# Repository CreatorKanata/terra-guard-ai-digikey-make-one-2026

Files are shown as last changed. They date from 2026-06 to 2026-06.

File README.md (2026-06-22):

<p align="center">
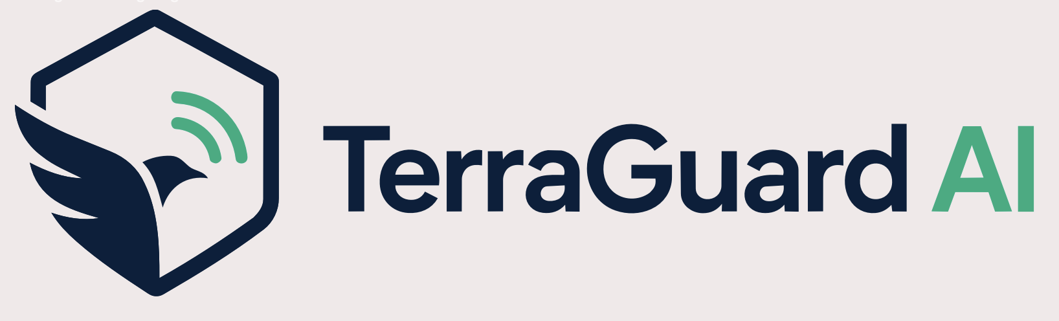
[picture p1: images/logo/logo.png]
TerraGuard AI
  
</p>

<p align="center">
  <b>カメラを使わない、ネットにつながない。<br>
  1 枚のマイコンだけで「カラスがいる」と気づくエッジAI。</b>
</p>

<p align="center">
  <a href="https://protopedia.net/event/digikey2026">DigiKey Make ONE Challenge 2026</a> 応募作品 ／ 使用ボード: <b>NXP FRDM-MCXN947</b>（おすすめ製品）
</p>

---

## 🎥 デモ動画（2分）

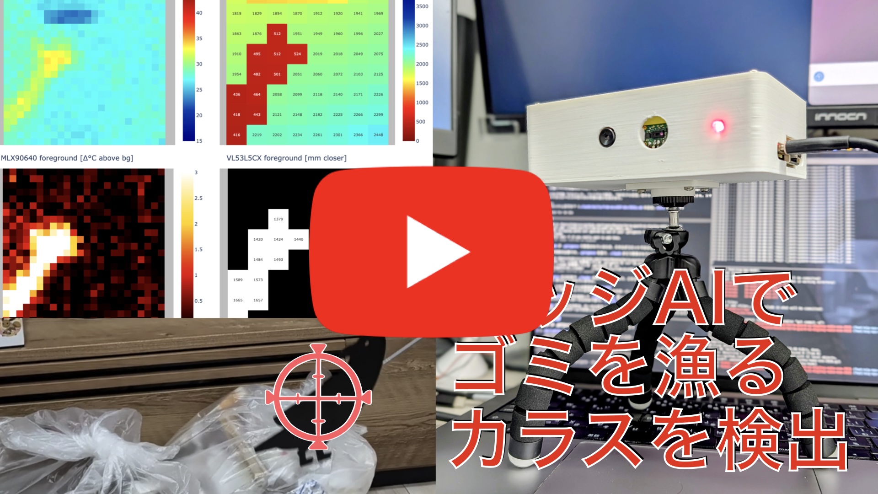
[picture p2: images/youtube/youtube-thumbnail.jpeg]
TerraGuard AI デモ動画 (https://youtu.be/Pb8VNFVwH3w)


> サムネイルをクリックで YouTube が開きます → **https://youtu.be/Pb8VNFVwH3w**

---

## これは何？

**TerraGuard AI** は、ゴミ置き場を荒らすカラスを検出するエッジAIです。
カメラの代わりに **低解像度サーマルセンサ（32×24）** と **距離センサ（8×8）** だけを使い、
**NXP FRDM-MCXN947 という 1 枚のボード上**で、取得 → AI推論 → 検出までを完結させます。

カラスは「**暖かくて（羽毛表面 約30〜35℃）・背景より手前に出た・小さなまとまり**」として現れます。
温度と距離を 1 つの小さな AI（CNN）に同時入力し、約1.4秒の連続検出で確定判定します。

| | |
| --- | --- |
| 🛰 **インターネット接続 不要** | 取得〜推論〜判定まで全部オンボード。クラウドに 1 バイトも送らない。 |
| 🔋 **低消費電力** | 推論はオンチップの **eIQ Neutron NPU**（実測 推論1回 約0.2ms）。 |
| 🔒 **プライバシー配慮** | カメラレス。32×24＋8×8 の低解像度では人物が判別できる映像が原理的に存在しない。 |
| 🧩 **追加ボード 0** | 中継用 Arduino 等は不使用。センサを FRDM-MCXN947 に直接 I2C 接続。 |

> **今回のスコープは「カラス検出」**。これは**カラス追い払いソリューションの第一歩**で、
> 次の展開は検出をトリガーにした **緑色レーザーによる追い払い**です。

---

## ✨ この作品の「イチ（ONE）」

本コンテストのテーマ「**1（イチ）**」に、性質の違う 3 つの「1」を重ねました。

1. **ONE chip** — たった 1 枚の MCU だけでエッジAIを完結（クラウド0・追加ボード0・カメラ0）
2. **ONE crow** — たった 1 羽の侵入者も見逃さない、プライバシー配慮型の番人
3. **ONE first** — 私にとって “1 回目” の、**人間がコードを 1 行も書かない完全AIファームウェア開発**

詳しくは [docs/protopedia/story.md](./docs/protopedia/story.md) を参照してください。

---

## 📸 デモの様子

| カラス検出（ダミーガラス） | 人がいても誤検出しない |
| :---: | :---: |
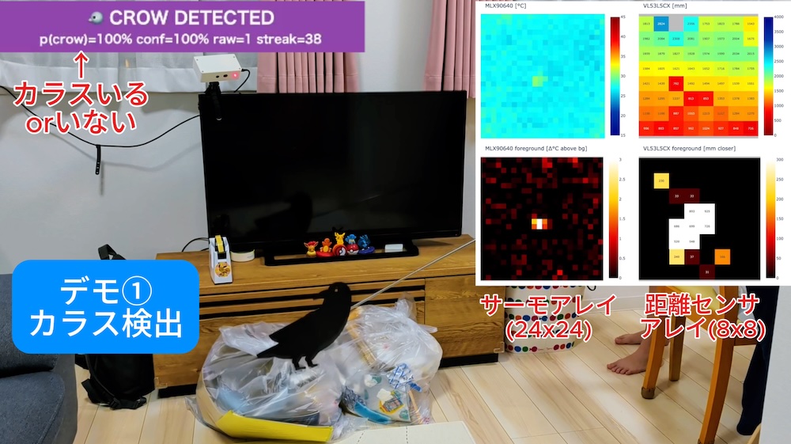
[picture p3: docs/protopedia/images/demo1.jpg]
カラス検出
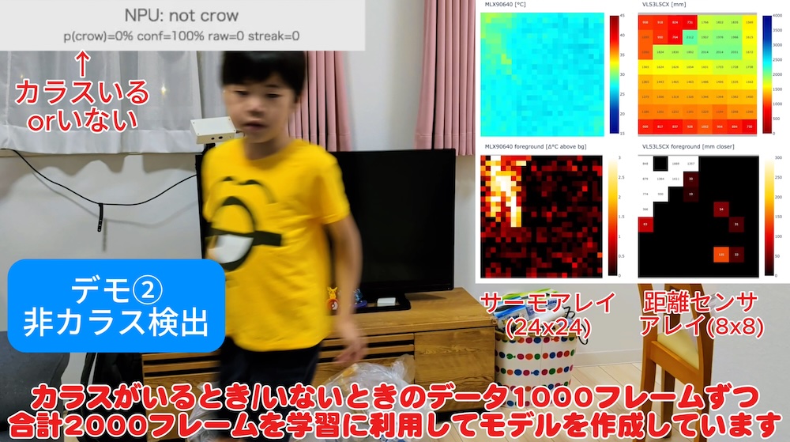
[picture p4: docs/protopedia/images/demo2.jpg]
非カラス
|  |  |
| **CROW DETECTED**（p=100%）。サーマルと距離に「暖かく手前のまとまり」が出ている。 | **not crow**。人が写っても、温度・距離のパターンが違うため誤検出しない。 |

右側の 4 分割は、ホスト側ビューア（`tools/dual_viewer_web.py`）で可視化したサーマル/距離とその前景です。

---

## 🔧 ハードウェア

| 完成体（3Dプリント外装＋三脚） | 中身（FRDM-MCXN947 ＋ センサ2個） |
| :---: | :---: |
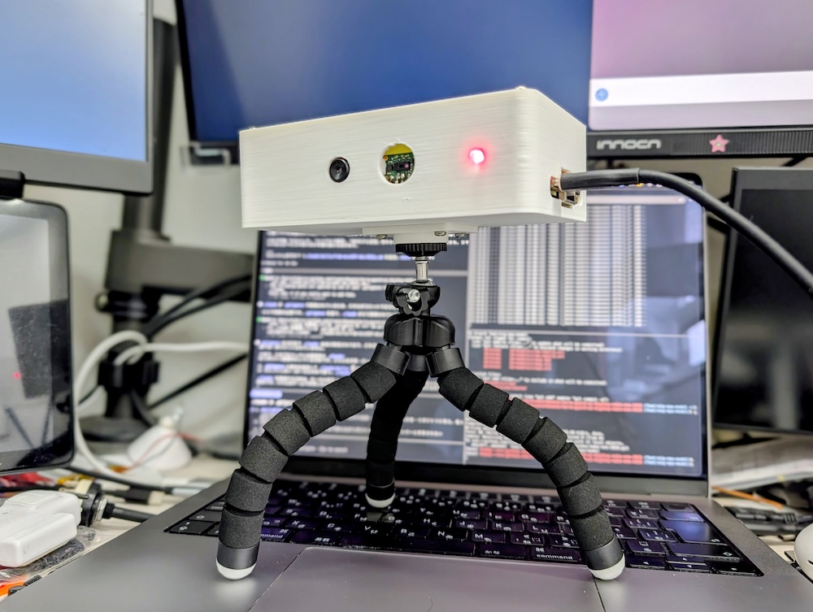
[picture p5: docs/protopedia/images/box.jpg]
外装
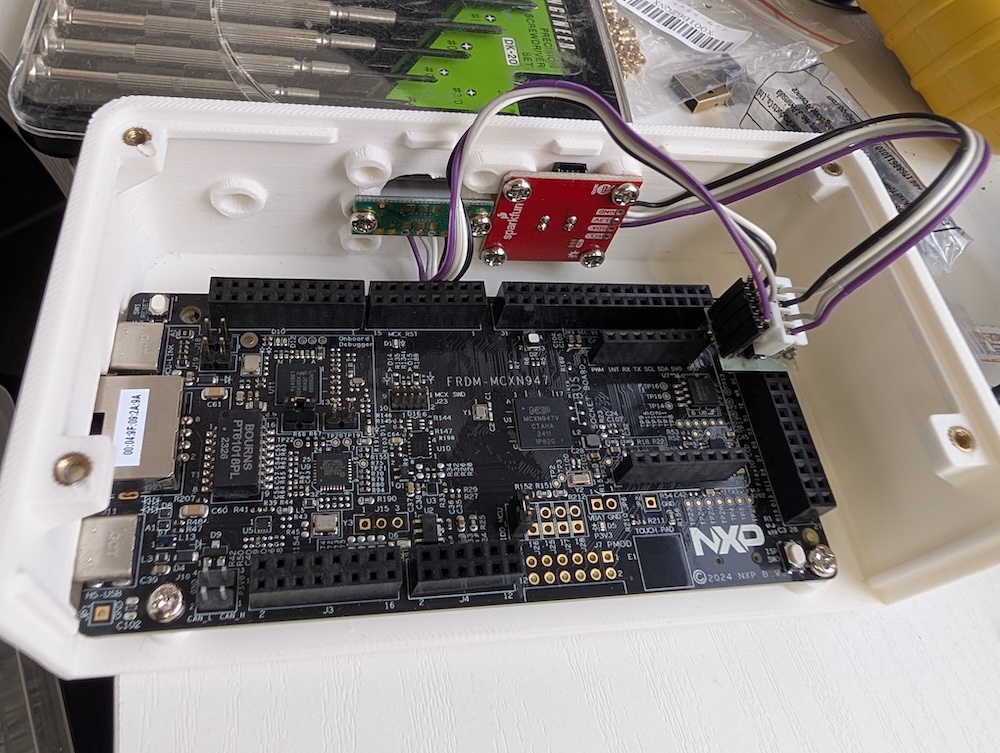
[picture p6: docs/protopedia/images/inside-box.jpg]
内部
|  |  |

| 要素 | 内容 |
| --- | --- |
| 開発ボード | **NXP FRDM-MCXN947**（デュアル Cortex-M33 + DSP + **eIQ Neutron NPU**、オンボード MCU-Link） |
| サーマルセンサ | **MLX90640**（32×24, I2C 0x33） |
| 距離センサ | **VL53L5CX**（ToF 8×8, I2C 0x29） |
| 外装 | Autodesk Fusion で 3D 設計し 3Dプリンタで製作 |

センサは同一 I2C バス（J8 pin1〜4）に直結。配線・ピン配置は [docs/hardware.md](./docs/hardware.md) を参照。

---

## 🧠 どうやってカラスを見分けるか

サーマルと距離をそれぞれ背景差分で「いま現れたもの（前景）」にし、
**4 チャンネル 24×24 のテンソル**にまとめて、オンチップの NPU で動く小型 CNN に通します。

<p align="center">
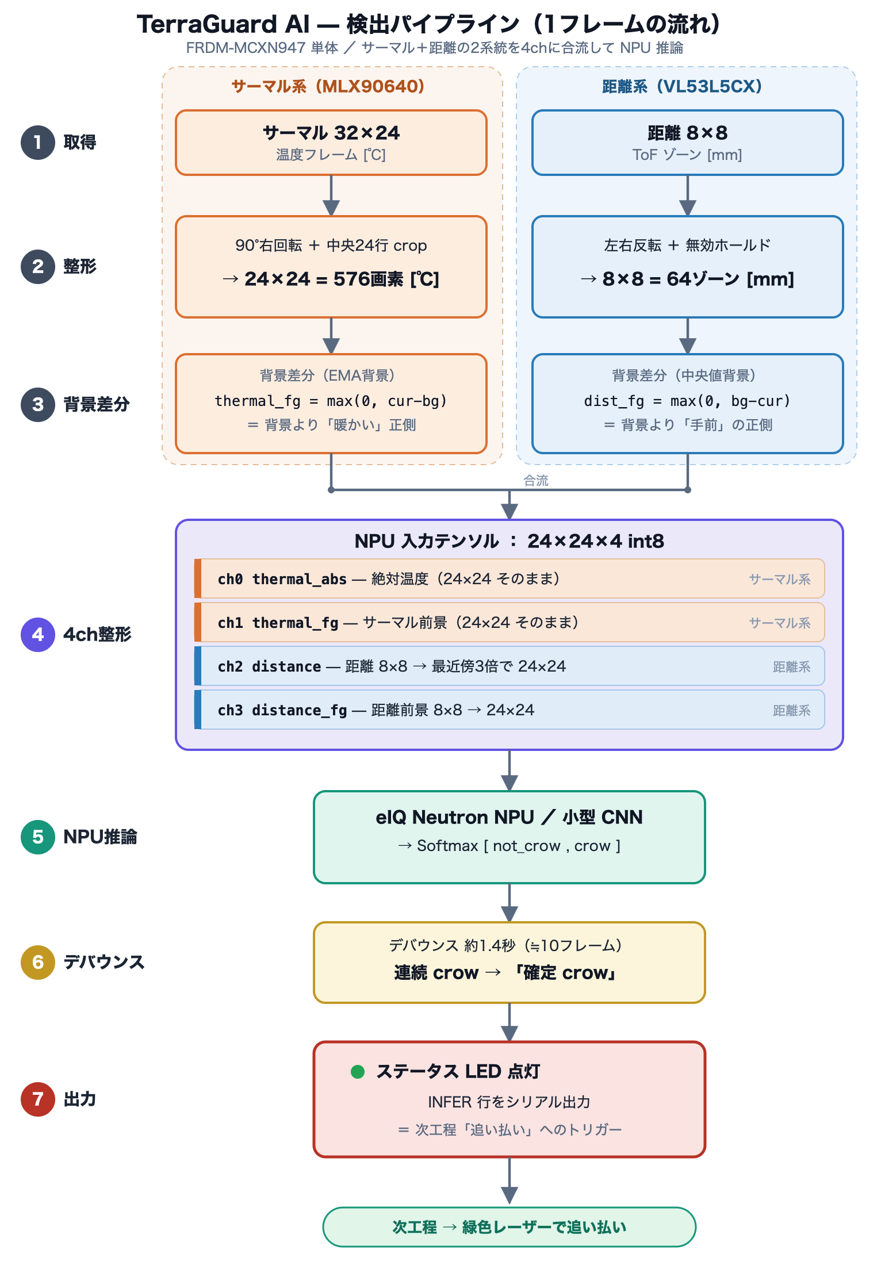
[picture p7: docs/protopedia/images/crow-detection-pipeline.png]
カラス検出パイプライン
  
</p>

ロジックの詳細は [docs/sensor-processing.md](./docs/sensor-processing.md)、
学習データの作り方は [docs/dataset.md](./docs/dataset.md) を参照してください。

---

## 🤖 完全AIファームウェア開発

本作のファームウェアは、**AI コーディングエージェント Claude Code が実装**しました。
制作者（人間）は **コードを 1 行も書かず・1 度も開かず**、ビルド・書き込み（flash）・学習コマンドの実行も**すべて AI がハンドリング**しています。

これを支えたのが、**FRDM-MCXN947 開発用に自作した「スキル」**です。
ビルド／書き込み／シリアル確認／NPU学習などの確定手順とハマりどころを AI 向けに記述しており、
AI はスキルを起動するだけで毎回ブレずに実機開発を進められます。

→ 仕組みと再現方法は [docs/dev-skill.md](./docs/dev-skill.md) を参照。

### 開発体制（人間 × AI）

| 担当 | 役割 |
| --- | --- |
| **キッズクリエーター かなた** | 発案、意匠デザイン、デモデザイン |
| **Claude Code**（AIエージェント） | ファームウェア開発、学習モデルデザイン |
| **かなたパパ** | AI の進捗管理、開発しやすい環境構築、はんだづけ |
| **かなた ＋ かなたパパ**（協働） | 外装の 3D 設計（Autodesk Fusion）・3Dプリント |

---

## 🚀 はじめかた

### センサ可視化ツール（PC側）

FRDM-MCXN947 がシリアル出力するサーマル/距離フレームをブラウザでリアルタイム可視化します。

```bash
cd tools
uv sync --all-extras                 # uv 推奨（pip の場合は pip install -e ".[web,gui]"）
uv run python dual_viewer_web.py     # → http://127.0.0.1:8050
```

### ファームのビルド・書き込み・再学習

NXP 開発（ビルド／flash／学習）は専用スキルに手順を集約しています。
→ [docs/dev-skill.md](./docs/dev-skill.md) ／ [docs/firmware.md](./docs/firmware.md) ／ [docs/ml-model.md](./docs/ml-model.md)

---

## 📁 リポジトリ構成

```text
.
├─ src/FRDM-MCXN947/   FRDM-MCXN947 の MCUXpresso SDK プロジェクト（ファーム本体）
├─ tools/              PC側のセンサ可視化・データ収集・学習ツール（Python）
├─ dataset/            学習データ（raw/=生サンプル, validation/）。built/ は再生成物
├─ docs/               プロジェクトドキュメント（日本語）
│  └─ protopedia/      ProtoPedia 掲載用（ストーリー・システム構成）
└─ images/             ロゴ・デモ・テスト画像
```

---

## 📚 ドキュメント

| ドキュメント | 内容 |
| --- | --- |
| [docs/protopedia/story.md](./docs/protopedia/story.md) | **ストーリー**（課題・3つの「イチ」・完全AI開発） |
| [docs/protopedia/system.md](./docs/protopedia/system.md) | **システム構成**（1チップ完結・部品表） |
| [docs/overview.md](./docs/overview.md) | 課題・ソリューション概要・全体アーキテクチャ |
| [docs/hardware.md](./docs/hardware.md) | 使用部品・配線・ピン配置 |
| [docs/sensor-processing.md](./docs/sensor-processing.md) | センサ処理・特徴量・カラス検出ロジック |
| [docs/dataset.md](./docs/dataset.md) | 学習データの作り方・`dataset/` 構成 |
| [docs/ml-model.md](./docs/ml-model.md) | 学習〜int8量子化〜NPUデプロイ |
| [docs/firmware.md](./docs/firmware.md) | FRDM-MCXN947 開発・ビルド・書き込み |
| [docs/dev-skill.md](./docs/dev-skill.md) | FRDM-MCXN947 開発用スキルの解説 |
| [docs/roadmap.md](./docs/roadmap.md) | 開発ステップ・追い払い機構の拡張 |

ドキュメントの入口は [docs/README.md](./docs/README.md) です。

---

## 🔗 関連リンク

- **[ProtoPedia 作品ページ](https://protopedia.net/prototype/8589)**
- **[デモ動画（YouTube）](https://youtu.be/Pb8VNFVwH3w)**
- **[DigiKey myLists 部品リスト](https://www.digikey.jp/ja/mylists/list/QGSF94NSJU)**

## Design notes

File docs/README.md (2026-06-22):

# TerraGuard AI — DigiKey Make ONE Challenge 2026

## プライバシー配慮型 害鳥・害獣監視＆追い払いAIソリューション

TerraGuard AI は、カラスなどの害鳥・害獣によるゴミ荒らし、農作物被害、施設侵入を検知し、必要に応じて追い払い動作へつなげるエッジAIソリューションである。

一般的なカメラ画像認識ではなく、低解像度サーマルセンサと距離センサアレイを利用し、「温度分布」「奥行き分布」「分布の動き」から異常状態を検出する。人物を識別可能な画像を取得しないため、住宅地や集合住宅のゴミ置き場でも導入しやすいプライバシー配慮型の仕組みを目指す。

本リポジトリは **DigiKey Make ONE Challenge 2026** 向けの実装である。**NXP FRDM-MCXN947 単体**で、センサを直接接続してセンサフュージョンとエッジAI処理を行う。外部のArduino等の中継ボードは使用しない。

> **今回のスコープ: まずは「カラスの検出」のみを実装する。**

---

## 関連リンク

| リンク | 内容 |
| --- | --- |
| [ProtoPedia 作品ページ](https://protopedia.net/prototype/8589) | コンテスト応募作品ページ。開発過程・デモを記事として公開中 |

---

## ドキュメント一覧

| ドキュメント | 内容 |
| --- | --- |
| [overview.md](./overview.md) | 課題・ソリューション概要・全体アーキテクチャ |
| [hardware.md](./hardware.md) | 使用部品・配線・システム構成（[pin-layout.png](./pin-layout.png) 参照） |
| [sensor-processing.md](./sensor-processing.md) | センサデータ処理・特徴量設計・カラス検出ロジック |
| [dataset.md](./dataset.md) | 学習データの作り方・`dataset/` 構成・再現手順 |
| [ml-model.md](./ml-model.md) | eIQ Neutron NPU 向け学習モデルの作り方とデプロイ（Mac → FRDM-MCXN947） |
| [firmware.md](./firmware.md) | FRDM-MCXN947 (MCUXpresso SDK) の開発・ビルド・書き込み |
| [dev-skill.md](./dev-skill.md) | FRDM-MCXN947 開発用スキルの解説（完全AI開発を支える仕組み） |
| [demo.md](./demo.md) | デモ構成・実験手順 |
| [roadmap.md](./roadmap.md) | 開発ステップ・追い払い機構の拡張 |
| [protopedia/](./protopedia/) | ProtoPedia 掲載用（[ストーリー](./protopedia/story.md)・[システム構成](./protopedia/system.md)） |
| [datasheets/](./datasheets/) | ボード/センサの公式マニュアル・ジャンパ早見表 |

---

## クイックスタート（FRDM-MCXN947）

FRDM-MCXN947 はオンボードの MCU-Link デバッガを搭載しているため、USB 接続のみでビルド・書き込み・デバッグができる。

```text
1. MCUXpresso IDE もしくは VS Code 用 MCUXpresso 拡張をインストール
2. FRDM-MCXN947 用 MCUXpresso SDK を取得
3. src/FRDM-MCXN947 のプロジェクトをビルド
4. USB(MCU-Link)経由で書き込み・デバッグ
```

詳細は [firmware.md](./firmware.md) を参照。

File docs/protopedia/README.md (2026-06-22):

# ProtoPedia 掲載用ドキュメント

DigiKey Make ONE Challenge 2026（ProtoPedia 登録）向けの、TerraGuard AI 紹介ドキュメントです。

- [story.md](./story.md) — **ストーリー**。なぜ作ったか、何を実現したか（カラス検出＝追い払いソリューションの第一歩）、次の展開（緑色レーザー追い払い）、3つの「イチ」、アプローチの面白さ。
- [system.md](./system.md) — **システム構成**。ハードウェア（FRDM-MCXN947・センサ）、検出パイプライン、AIモデル、開発手法、部品表。

> 技術詳細は `docs/` 直下（[overview](../overview.md) / [hardware](../hardware.md) / [sensor-processing](../sensor-processing.md) / [ml-model](../ml-model.md)）を参照。

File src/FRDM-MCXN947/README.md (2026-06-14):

# src/FRDM-MCXN947

NXP FRDM-MCXN947 の MCUXpresso SDK プロジェクト。MCUXpresso for VS Code 拡張で作成した、リポジトリ管理（repo-managed）プロジェクト。

- 開発ボード: NXP FRDM-MCXN947（Cortex-M33 ×2 + DSP + eIQ Neutron NPU）
- 現状: **LED点滅（led_blinky）でビルド・書き込み環境を確認する段階**
- 今回のスコープ: カラスの検出（センサ取得は次ステップ）

## ディレクトリ構成

- `terra-guard-ai/` — アプリ本体（VS Code 拡張が生成したプロジェクト）
  - `led_blinky.c` — メイン（SysTick割り込みでオンボードLEDをトグル）
  - `CMakePresets.json` / `mcux_include.json` — ビルド設定（toolchain / SDK パス / board / core_id）
  - `frdmmcxn947_cm33_core0/` — ボード初期化・pin_mux・clock 等
  - `.vscode/` — VS Code 用の build / debug / flash 設定
- `sdks/`（gitignore） — プロジェクト専用の MCUXpresso SDK クローン。**コミットしない**（容量大。west / VS Code 拡張で再取得）。

## ビルド・書き込み

### VS Code（推奨）

1. `terra-guard-ai/` を MCUXpresso for VS Code 拡張で開く
2. プロジェクトをビルド（preset: `debug`）
3. FRDM-MCXN947 を USB-C で MCU-Link ポート（J17）に接続
4. Flash / Debug ボタンで書き込み・実行 → オンボードLEDが点滅

### CLI（CMake Presets）

必要な環境変数は `terra-guard-ai/mcux_include.json` の preset 内に定義済み（ARMGCC_DIR / SdkRootDirPath / MCUX_VENV_PATH）。

```bash
cd terra-guard-ai
cmake --preset debug      # configure
cmake --build debug       # build → debug/terra-guard-ai_cm33_core0.elf
```

> 注: `mcux_include.json` の SDK パス等はローカル環境の絶対パスを含む。別環境では VS Code 拡張で再生成するか、パスを調整する。

詳細な開発方針は [../../docs/firmware.md](../../docs/firmware.md) を参照。

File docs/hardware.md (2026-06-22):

# ハードウェア — 使用部品・配線・システム構成

| 完成体（3Dプリント外装） | 内部（FRDM-MCXN947 ＋ センサ2個の結線） |
| :---: | :---: |
| 外装 | 内部 |

## 部品一覧

### 1. サーマルセンサ — MLX90640（視野角110°版）

SparkFun MLX90640 Thermal Camera Breakout
<https://www.sparkfun.com/products/14843>

用途：

- 32×24 の低解像度サーマル画像を取得
- ゴミ置き場周辺の温度分布を取得
- 背景との差分から、熱源の出現や移動を検出

備考：

- 今回の試作では 110° 版を使用する（広角のため近距離でゴミ置き場全体を捉える用途に向く）
- **解像度の扱い**: センサ生は 32×24=768 だが、**取得直後に `rotate_crop()`（90度右回転＋中央24行crop）で 24×24=576 に整える**（センサを90度回転して取り付けているため）。背景差分・特徴量・**NPU入力まで、すべての処理は 24×24** で行う（旧設計の「16×12へ縮小」は廃止）。
- インターフェースは I2C

---

### 2. ToF距離センサ — VL53L5CX

用途：

- 8×8 のマルチゾーン距離データを取得
- ゴミ袋の形状変化を検出
- カラスがゴミ袋の上に乗る、袋を引っ張る、周辺で動くなどの奥行き変化を取得

備考：

- 8×8 の距離マップをそのまま特徴量として利用可能
- サーマルでは見えにくい夏場や高温背景に対して、距離変化で補完する
- インターフェースは I2C

---

### 3. 制御・AIボード — NXP FRDM-MCXN947

本プロジェクトの中核ボード。センサを直接接続し、取得・前処理・AI推論まで単体で完結する。外部のArduino等の中継ボードは使用しない。

| 項目 | 内容 |
| --- | --- |
| MCU | MCXN947（**デュアル Arm Cortex-M33、最大150MHz** + DSP コプロセッサ） |
| AIアクセラレータ | **eIQ Neutron NPU**（エッジAI推論を高速・低消費電力で実行） |
| メモリ | 最大 2MB デュアルバンク Flash（ECC RAM オプション） |
| センサ接続 | **I2C / I3C**（MLX90640・VL53L5CX を直接接続） |
| デバッガ | オンボード **MCU-Link**（USB接続のみで書き込み・デバッグ可。追加プローブ不要） |
| 拡張 | Arduino シールド互換ヘッダ、MikroElektronika Click、Pmod |
| 開発環境 | **MCUXpresso SDK**（MCUXpresso IDE / VS Code 拡張） |

用途：

- MLX90640 と VL53L5CX を I2C で直接取得
- センサデータの前処理（差分マップ生成、特徴量抽出）
- カラス検出のAI推論（eIQ / 必要に応じて Neutron NPU を活用）またはルールベース判定
- 検出結果に応じた出力（今回はLED等での通知、後続で追い払い機構）

このボードを使う理由：

- eIQ Neutron NPU によりエッジで低消費電力AI推論ができる
- I2C/I3C でサーマル・距離センサを直接扱える
- オンボード MCU-Link で開発・デバッグが容易
- DigiKey で入手可能

---

## システム構成

```text
MLX90640 110°
32×24 サーマルアレイ
        │
        │ I2C
        ▼
┌─────────────────────────────┐
│  NXP FRDM-MCXN947           │
│   Cortex-M33 ×2 + DSP       │
│   + eIQ Neutron NPU         │
└─────────────────────────────┘
        ▲
        │ I2C
        │
VL53L5CX
8×8 ToF距離センサ
```

ボード上で行う処理：

```text
1. サーマルデータ取得
2. 距離データ取得
3. 背景フレームとの差分計算
4. 時間差分の計算
5. 重心位置・変化量などの特徴量抽出
6. カラス検出の判定（AI推論 / ルールベース）
7. 検出結果の出力（今回はLED等での通知）
```

---

## ピン配置（ピンレイアウト図）

FRDM-MCXN947 の全ヘッダのピン配置は [pin-layout.png](./pin-layout.png) を参照（配線時の早見図）。

## 外部センサ（MLX90640 / VL53L5CX）の I2C 配線

外部I²Cセンサは **バス LPI2C2 / FLEXCOMM2**（P4_0=SDA / P4_1=SCL）に接続する。オンボード温度センサ(I3C1)とは別バスで独立。このバスは複数のヘッダに引き出されており、**どれを使っても電気的に同一バス**（同じ P4_0/P4_1）。

### 推奨: J8（FlexIO ヘッダ）pin1〜4 ← **疎通確認済み**

| センサ側 | J8 ピン | 信号 / MCU |
| --- | --- | --- |
| **VCC** | **J8 pin 1** | **3.3V (P3V3)** |
| **GND** | **J8 pin 2** | **GND** |
| **SCL** | **J8 pin 3** | I2C_SCL / **P4_1**（FC2_I2C_SCL） |
| **SDA** | **J8 pin 4** | I2C_SDA / **P4_0**（FC2_I2C_SDA） |

- **コネクタ実装済み**なので追加ハンダ付け不要。電源・GND・I²Cがpin1〜4に隣接して並び、センサ1個ぶんが最短で配線できる。
- **✅ MLX90640 を J8 pin3/4 に接続し、起動時 I²Cスキャンで 0x33 の ACK を確認済み**（[firmware.md](./firmware.md) 参照）。

```text
FRDM-MCXN947                     センサ(MLX90640 / VL53L5CX)
  J8 pin1 (P3V3, 3.3V) ───────── VCC/VIN
  J8 pin2 (GND)        ───────── GND
  J8 pin3 (P4_1, SCL)  ───────── SCL
  J8 pin4 (P4_0, SDA)  ───────── SDA
```

### 代替: J2（Arduino ヘッダ）pin18/20 — J8 と同一バス

| センサ側 | 接続先 | 信号 / デバイスピン |
| --- | --- | --- |
| **SDA** | **J2 pin 18** | ARD_D18 / **P4_0**（FC2_I2C_SDA） |
| **SCL** | **J2 pin 20** | ARD_D19 / **P4_1**（FC2_I2C_SCL） |
| **VCC** | **J3 の P3V3（3.3V）** | 3.3V（5Vピンは使わない） |
| **GND** | J2/J3 の GND | — |

> J8 pin3/4 と J2 pin18/20 は**同じ P4_0/P4_1（同一 FC2 バス）**。電源/GNDの取り回しの都合で選んでよい。

### 別系統が欲しい場合: J7（Pmod）pin6/8/10/12 — 独立 FC7 バス（要ハンダ付け）

2本目の独立 I²C バスが必要なときは J7 を使える。**ただし J7 はコネクタDNP（未実装）でヘッダのハンダ付けが必要**。

| J7 ピン | 信号 / MCU |
| --- | --- |
| 6 | FC7_I2C_SCL / P3_3（SJ12 デフォルトのまま） |
| 8 | FC7_I2C_SDA / P3_2 |
| 10 | GND |
| 12 | 3.3V (P3V3) |

> J7 は別バス（**LPI2C7 / FLEXCOMM7**）。ソフトは FC7 用に別途セットアップが必要。当面は J8/J2(FC2) を主に使い、2系統に分ける必要が出たら検討する。

### 共通の注意

- 信号は **3.3V レベル**。MLX90640・VL53L5CX とも3.3V直結OK（レベル変換不要）。
- ソフト側は「pin_mux で P4_0/P4_1 を FC2 に割当 + `CLOCK_AttachClk(kFRO12M_to_FLEXCOMM2)` + `prj.conf` にドライバ」の3点セット（[firmware.md](./firmware.md) のペリフェラル追加手順参照）。

## I2C アドレスの注意

MLX90640（0x33）と VL53L5CX（0x29）は同一 I2C バス上に共存可能（アドレス衝突なし）。複数センサ接続時のプルアップ・電源容量に注意する。Breakout基板は通常プルアップ実装済み。各センサ単体での疎通（I²Cスキャンでの ACK 確認）を先に済ませてから統合する。

---

関連: [sensor-processing.md](./sensor-processing.md) / [firmware.md](./firmware.md) / [datasheets/](./datasheets/)

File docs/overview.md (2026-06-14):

# 概要 — 課題・ソリューション・全体アーキテクチャ

## 解決したい課題

都市部や住宅地では、カラスがゴミ袋を破り、ゴミ置き場を荒らす被害が発生している。従来の対策はネット、物理カバー、人による監視が中心であり、カラスの学習能力や設置環境によって効果が限定的になることがある。

カメラAIによる監視も考えられるが、住宅地では通行人や住民の映像を取得してしまうため、プライバシー面の課題がある。また、クラウドAIは通信環境、消費電力、運用コストの問題もある。

TerraGuard AI は、低解像度センサとオンデバイスAIを用いることで、カメラを使わず、クラウドにも依存しない害鳥・害獣検知を目指す。

---

## ソリューション概要

TerraGuard AI は、ゴミ置き場などの監視対象エリアに設置し、以下の情報を取得する。

- サーマルセンサによる温度分布
- ToF距離センサによる奥行き分布
- 背景との差分
- 時間方向の変化
- 変化領域の重心位置や移動量

本システムは、カラスをカメラ画像で直接認識するのではなく、ゴミ置き場に発生する状態変化を学習する。

分類対象の例：

```text
1. 通常状態
2. カラスによるゴミ漁り
3. 人によるゴミ出し
```

**今回のスコープでは「カラスによるゴミ漁り」の検出に絞って確実に動作させる。** その後、追加学習により「人によるゴミ出し」を含む多状態分類へ拡張する。

---

## 全体アーキテクチャ

DigiKey Make ONE Challenge 2026 版では、**NXP FRDM-MCXN947 単体**で、センサを直接接続してセンサフュージョンとエッジAI処理を行う。外部のArduino等の中継ボードは使用しない。

FRDM-MCXN947 は **eIQ Neutron NPU** を内蔵しており、低消費電力でエッジAI推論を実行できる。

```text
  MLX90640 (サーマル 32×24)
        │ I2C
        ▼
  ┌─────────────────────────────────────┐
  │  NXP FRDM-MCXN947                    │
  │   - Cortex-M33 ×2 + DSP             │
  │   - eIQ Neutron NPU (エッジAI推論)   │
  │                                     │
  │   センサ取得 → 前処理(差分/特徴量)     │
  │     → カラス検出AI/ルール判定         │
  └─────────────────────────────────────┘
        ▲                    │
        │ I2C                │ 検出結果
        │                    ▼
  VL53L5CX (ToF 8×8)   追い払い機構（後続: LED/ブザー/サーボ等）
```

> 今回は「カラス検出」まで。追い払い機構の駆動は後続ステップ（[roadmap.md](./roadmap.md)）。

---

## 重点ポイント（DigiKey Make ONE Challenge 2026）

- NXP MCU 単体でのセンサフュージョン（サーマル + 距離）
- eIQ Neutron NPU を活かしたエッジAI推論
- 害鳥・害獣対策ソリューションとしての実用性
- DigiKey で入手可能な部品構成
- 検知から追い払いまでの一連の動作デモ（最終形）
- カメラを使わないプライバシー配慮型検知

---

関連: [hardware.md](./hardware.md) / [sensor-processing.md](./sensor-processing.md)

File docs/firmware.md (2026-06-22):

# ファームウェア — FRDM-MCXN947 (MCUXpresso SDK) の開発

本プロジェクトのファームウェアは **NXP FRDM-MCXN947** 上で動作する。開発には **MCUXpresso SDK** を使用する。プロジェクトルートは `src/FRDM-MCXN947`。外部のArduino等の中継ボードは使用しない。

## ボード概要

| 項目 | 内容 |
| --- | --- |
| MCU | MCXN947（デュアル Arm Cortex-M33、最大150MHz + DSP） |
| AIアクセラレータ | eIQ Neutron NPU |
| センサ接続 | I2C / I3C（MLX90640・VL53L5CX を直接接続） |
| デバッガ | オンボード MCU-Link（USB接続のみで書き込み・デバッグ・仮想COM） |

## 開発環境のセットアップ

以下のいずれかを使用する。

1. **MCUXpresso IDE** + FRDM-MCXN947 用 MCUXpresso SDK
2. **VS Code** + MCUXpresso for VS Code 拡張（CMake / arm-none-eabi-gcc）

手順の概要：

```text
1. MCUXpresso IDE もしくは VS Code 用 MCUXpresso 拡張をインストール
2. FRDM-MCXN947 用の MCUXpresso SDK を取得（NXP の SDK Builder / 拡張から）
3. src/FRDM-MCXN947 のプロジェクトをインポート / 生成
4. ビルド
5. USB(MCU-Link)経由で書き込み・デバッグ
```

## プロジェクト構成（`src/FRDM-MCXN947/terra-guard-ai`）

CLI ビルドの中心は MCUXpresso SDK の CMake/Kconfig。役割ごとにファイルが分かれている。

| ファイル | 役割 |
| --- | --- |
| `led_blinky.c` | アプリ本体（`main`）。薄いオーケストレータ。起動時に外部I²Cスキャン → P3T1755(I3C)初期化 → **MLX90640(サーマル)と VL53L5CX(距離)を同時初期化し、1ループで両センサのフレームを同一シリアルへ出力** |
| `app/sensor_bus.c` / `.h` | センサ共通基盤。I3C 低レベルアクセス、P3T1755(オンボード温度)初期化/読み出し、外部I²C(LPI2C2)初期化・バススキャン、float温度のシリアル出力 |
| `app/thermal_mlx90640.c` / `.h` | MLX90640 サーマルセンサ（初期化 / data-ready 確認 / サブフレーム取得・温度変換 / 統計・全画素フレーム出力） |
| `app/tof_vl53l5cx.c` / `.h` | VL53L5CX ToF距離センサ（初期化 / 新フレームのポーリング取得 / 8×8 距離・状態の出力） |
| `prj.conf` | 有効化する SDK コンポーネント（ドライバ等）。**新ドライバを使うときはここに追記して `cmake --preset debug` を再実行** |
| `frdmmcxn947_cm33_core0/cm33_core0/app.h` | ペリフェラル/アドレス等のマクロ定義（I3C1=0x48, LPI2C2 ベース/クロック等） |
| `frdmmcxn947_cm33_core0/cm33_core0/hardware_init.c` | `BOARD_InitHardware()`。**クロックアタッチ**と各ピン初期化呼び出しをまとめる |
| `frdmmcxn947_cm33_core0/led_blinky/pin_mux.c` / `.h` | **ピンmux**設定（`BOARD_InitPins`=UART/LED, `BOARD_InitI3CPins`=温度センサ, `BOARD_InitI2CPins`=外部I²C） |
| `CMakeLists.txt` | ソース/インクルード登録 |
| `CMakePresets.json` / `mcux_include.json` | CMake preset と環境変数（SDKパス・ツールチェイン）の供給 |

> ⚠️ `pin_mux.c` の冒頭コメントに「Config Tools が上書きする」とあるが、本プロジェクトは CLI 開発のため**手書き編集して問題ない**（Config Tools を再実行しない運用）。

### ペリフェラルを追加する手順（I²C/I3C/UART 共通の「3点セット」）

新しいバス・ペリフェラルを使うときは必ず以下の3つをそろえる。1つでも漏れると**ハング or 無音**になる（何度もハマった実績あり）。

1. **クロックアタッチ**（`hardware_init.c`）: `CLOCK_SetClkDiv(...)` + `CLOCK_AttachClk(...)`
2. **ピンmux**（`pin_mux.c`）: 対象ピンを該当 FLEXCOMM/I3C の機能に割当（`PORT_SetPinConfig`）
3. **ドライバ有効化**（`prj.conf`）: `CONFIG_MCUX_COMPONENT_driver.xxx=y` を追記
   （+ 必要に応じて `RESET_ClearPeripheralReset(...)`、`app.h` にベース/クロックのマクロ追加）

確立済みの具体値:

| バス | 用途 | クロック | ピン(mux) | ドライバ(prj.conf) |
| --- | --- | --- | --- | --- |
| **FLEXCOMM4 (LPUART4)** | デバッグUART/PRINTF | `kFRO12M_to_FLEXCOMM4`, Div=1 | P1_8/P1_9 = `kPORT_MuxAlt2` | `driver.lpflexcomm_lpuart` |
| **I3C1** | オンボード温度センサ | `kPLL0_to_I3C1FCLK`, Div=6 | P1_11/16/17 = `kPORT_MuxAlt10` | `driver.i3c`, `driver.p3t1755` |
| **FLEXCOMM2 (LPI2C2)** | 外部I²Cセンサ（1MHz/FM+） | `kFRO_HF_DIV_to_FLEXCOMM2`, FRO_HF_DIV=÷2(24MHz) | P4_0/P4_1 = `kPORT_MuxAlt2`(内部PU有効) | `driver.lpflexcomm_lpi2c` |

> ⚠️ **I²C を 1MHz で動かす鍵はクロック源**: MLX90640/VL53L5CX とも最大1MHz(FM+)対応だが、FC2 に FRO12M(12MHz) を供給すると 1MHz SCL を12分周でしか作れず波形が規格を満たさず**通信不可**になる。**FRO_HF(48MHz)→FRO_HF_DIV ÷2=24MHz** を供給すれば 1MHz SCL を綺麗に生成でき、両センサが安定動作する（`hardware_init.c`）。`BOARD_InitBootClocks()` で FRO_HF を確定させた**後**にアタッチすること。
>
> ⚠️ **バスロックの回復**: 高速化テスト等でセンサが I²C バスをロック(SDA Low張り付き)すると、以後 probe/通信がハングし MCU リセット(flash/run)では戻らない。**USB 抜き差しで電源リセット**すると解除される。

> FLEXCOMM2 のクロック周波数取得は `CLOCK_GetLPFlexCommClkFreq(2u)`、ベースは `LPI2C2`。
> NXP の `driver_examples/lpi2c/polling_b2b/master`（`LPI2C2_InitPins`）が正準リファレンス。

## ビルド・書き込み・デバッグ

- FRDM-MCXN947 を USB で PC に接続すると、オンボードの **MCU-Link** がデバッガ兼仮想COMポートとして認識される。
- MCUXpresso IDE / VS Code 拡張からビルドし、そのまま書き込み・ステップ実行ができる。追加のデバッグプローブは不要。
- ログは **デバッグUART（MCU-Link の仮想COM, 921600 baud）** に出力し、PC のシリアルターミナルで確認する（高fpsのサーマルフレームを捌くため 115200→921600 に引き上げ済み・`board.h`）。
- **出力フォーマット**: 距離はテキスト行 `DIST,<z0..z63>` / `STAT,<s0..s63>`、サーマルは**バイナリフレーム** `0xAA 0x55 + Ta(int16 LE) + 576×int16 LE`（計1156B、PRINTF の書式変換コストを避け高速化）。サーマル前景（背景差分の正側）は `0xAA 0x56 + 576×int16 LE`。`tools/dual_viewer.py` がバイナリ＋テキスト混在を `extract_messages` で分離して2画面表示する。
  - **解像度は 24×24（576画素）**: MLX90640 の生は 32×24=768 だが、ファームは**取得直後に `rotate_crop()`（90度右回転＋中央24行crop）で 24×24 に整える**（センサを物理的に90度回転して取り付けているため）。**送出・統計・背景差分・NPU入力・データ収集まで、すべての処理は 24×24 で行われる**。シリアルに流れるサーマルフレームも 576×int16 である。

### CLI でのビルド・書き込み・シリアル確認

> 🛠️ **実行コマンドは `frdm-mcxn947-dev` スキルに一本化**してある。ビルド・書き込み・
> シリアル確認・west サンプルビルドを行うときは、まず `frdm-mcxn947-dev` スキルを起動し、
> その手順（確定パス／ビルド／書き込み／シリアル確認）に従うこと。VS Code を使わず
> ターミナルだけで完結できる。以下は手順そのものではなく、運用上の**重要な前提知識**。

- **ビルド**: CMake Presets（`debug`/`release`）。`prj.conf` 変更時のみ configure を再実行。
  成果物は `src/FRDM-MCXN947/terra-guard-ai/debug/terra-guard-ai_cm33_core0.elf`。
- **書き込み**: LinkServer で上記 ELF を flash。`LinkServer` に単体の `reset` サブコマンドは無い。
- **シリアル確認**（最重要）: ⚠️ **必ず `921600` で開くこと**。本ファームの VCOM は `board.h` の
  `BOARD_DEBUG_UART_BAUDRATE=921600U`（MLX90640 の大フレームを捌くため 115200 の8倍）。
  **115200 で開くと全バイト文字化けし「ファーム異常」「センサ無反応」と誤診しやすい。**
  受信側ツール（`dual_viewer.py` / `dual_viewer_web.py` / `fps_meter.py`）のデフォルトも 921600。
  （※ core1 のデバッグUARTのみ 115200。hello_world で経路切り分けする際も hello_world 側は 115200。）
  サーマルはバイナリなので `screen` では文字化けする。pyserial で時間窓読みするのが基本。
- **起動直後の1回きりの出力（I²Cスキャン等）を拾うコツ**: 後からシリアルを開くと取り逃す。
  **先に受信をバックグラウンド開始 → その後 flash** すると再起動時の起動ログを最初から拾える。
- ⚠️ **flash 中に VCOM が切断される環境がある**: flash 中にシリアルを開いたままだと MCU-Link が
  一旦 USB から消え `Device not configured` で読み取りが落ちる（無音=ハングは誤り）。
  定常出力（DIST/STAT 等）を見たいときは **flash 完了 → ポート再列挙を待つ → 改めて開く** 手順が安定。

### west で SDK サンプルを直接ビルド（動作確認に便利）

新機能はまず公式サンプルを west で焼いて疎通確認すると早い（例: 温度センサ）。
**実行コマンドは `frdm-mcxn947-dev` スキルを参照。** 注意点だけ記す:
システムPython（3.14等）には yaml が無くビルドが失敗するため、必ず MCUXpresso venv の
Python/west を PATH 先頭に入れること（`ARMGCC_DIR` の設定も必要）。

### トラブル: シリアルに何も出ない / MCU-Link が消えた

これは何度かハマった実績がある。チェック順:

1. **MCU-Link ファームが古い** → VCOM が機能しないことがある。`LinkServer probes` で版を確認し、古ければ更新（[datasheets/README.md](./datasheets/README.md) のリカバリ手順、J21ショート→`program_CMSIS -s`→J21戻す）。
2. **J18 がショート** されていると VCOM 無効。**オープン**にする。
3. アプリ側の **UART(FC4) pin_mux** と **FLEXCOMM4 クロックアタッチ** が両方必要。
4. センサ通信がハングする場合、対象バスの **クロックアタッチ + pin_mux** が両方そろっているか確認（I3Cなら PLL0→I3C1、`BOARD_InitI3CPins`）。

> 切り分けのコツ: 純正 `hello_world` を west で焼いて 115200 で読む。出れば「シリアル経路OK＝自分のコードの問題」、出なければ「ハード/ファーム側の問題」と一発で分かる。

## センサ接続

### オンボード温度センサ（P3T1755DP / I3C, 0x48）— 疎通確認に最適

FRDM-MCXN947 には **温度センサ P3T1755DP** がオンボード実装されている（**加速度センサは非搭載**）。配線なしで I3C・シリアルの動作確認に使える。

- バス: **I3C1**（P1_16=SCL / P1_17=SDA）、アドレス 0x48
- SDK ドライバ `components/sensor/p3t1755`、公式サンプル `driver_examples/i3c/master_read_sensor_p3t1755`
- **動作確認済み**: 上記サンプルで約28℃の室温がシリアル出力されることを確認
- 詳細: [datasheets/FRDM-MCXN947.md](./datasheets/FRDM-MCXN947.md)

### 外部センサ（MLX90640 / VL53L5CX）— I2C 接続（LPI2C2/FC2）

- バスは **LPI2C2 / FLEXCOMM2**（P4_0=SDA / P4_1=SCL）。配線は **J8(FlexIO) pin1〜4** が最も楽（後述）。J2(Arduino) pin18/20 も**同一バス**。
- MLX90640（サーマル 32×24, **0x33**）と VL53L5CX（ToF 8×8, **0x29**）はアドレス衝突せず同一バス共存可。プルアップ・電源容量に注意（Breakout基板はプルアップ実装済みが通常）。
- **✅ 疎通確認済み**: J8 pin3=SCL/pin4=SDA に MLX90640 を接続し、起動時の **I²Cバススキャンで 0x33 の ACK を確認**（`led_blinky.c` の `i2c_bus_scan()`）。

#### J8 ピン配置（I²C 接続の早見）

| J8 ピン | 信号 | MCU |
| --- | --- | --- |
| 1 | **3.3V (P3V3)** | — |
| 2 | **GND** | — |
| 3 | **I2C_SCL** | P4_1 / FC2_I2C_SCL |
| 4 | **I2C_SDA** | P4_0 / FC2_I2C_SDA |

> J8 はコネクタ実装済みのため**ハンダ付け不要**。J2 と同一の FC2 バスなので**ソフトは共通**。別系統の独立 I²C バスが欲しい場合のみ J7(FC7, ただし DNP=要ハンダ付け) を使う。詳細は [hardware.md](./hardware.md)。

#### I²C 疎通確認の定番手法（バススキャン）

新規 I²Cデバイスはまず **アドレススキャンで ACK を確認**してからレジスタアクセスへ進む。
`LPI2C_MasterStart(addr, kLPI2C_Write)` → `LPI2C_MasterStop()` の戻り値が `kStatus_Success` なら、そのアドレスにデバイスが存在（ACK）。0x08〜0x77 を総当たりすれば結線・電源・アドレスを一発で確認できる（`led_blinky.c` 参照）。

#### MLX90640 フレーム取得（✅ 実装・実機確認済み）

Melexis 公式 API（Apache-2.0）を `vendor/mlx90640/` に移植し、I²Cドライバ層だけ LPI2C2 で自前実装。
センサ生は 32×24=768 画素の校正済み温度[℃]を取得し、**取得直後に `rotate_crop()` で 24×24=576 に整えてから**シリアル出力・背景差分・NPU入力へ渡す（以降の処理はすべて 24×24。[datasheets/MLX90640.md](./datasheets/MLX90640.md) に詳細）。

- **vendor 構成**: `MLX90640_API.c/.h`・`MLX90640_I2C_Driver.h`（公式原文）＋ `mlx90640_i2c_lpi2c.c`（自前/BSD-3）。
  CMake で `mcux_add_source` と `mcux_add_include(INCLUDES vendor/mlx90640)`。インクルードは `<MLX90640_API.h>` 形式。
- **API 呼び出し順**: `SetRefreshRate(2Hz) → SetChessMode → DumpEE → ExtractParameters`（起動時1回）→
  ループ `GetFrameData → GetTa → CalculateTo(0.95, Ta-8)`。
- **ハマりどころ2点（重要・再発しやすい）**:
  1. **大容量連続リードでハング** → `MLX90640_I2CRead` を 32ワードずつ**分割読み出し**で実装。
  2. **`ExtractParameters` が `float[768]`(3KB) のローカル配列を使い、デフォルトスタック2KBで HardFault**
     → CMake に `mcux_add_linker_symbol(SYMBOLS __stack_size__=0x4000)` を追加（16KBへ拡張）。
- **メモリ見積り**: 校正パラメータ(約2.5KB)＋eeData(1.6KB)＋frameData(1.6KB)＋to[768](3KB) を **static** に確保
  （スタックではなく BSS）。RAM 512KB に対し十分余裕。

#### VL53L5CX 距離取得（✅ 実装・実機確認済み）

ST 公式 ULD（BSD-3）を `vendor/vl53l5cx/` に移植し、プラットフォーム層だけ LPI2C2 で自前実装。
8×8 の距離[mm]マップを取得（[datasheets/VL53L5CX.md](./datasheets/VL53L5CX.md) に詳細）。

- **vendor 構成**: `vl53l5cx_api.c/.h`・`vl53l5cx_buffers.h`(FW 84KB)・`platform.h`（ST公式原文）＋ `vl53l5cx_platform_lpi2c.c`（自前/BSD-3）。
- **API 呼び出し順**: `is_alive → init(FW転送) → set_resolution(8X8) → set_ranging_frequency_hz(15) → start_ranging`
  → ループ `check_data_ready → get_ranging_data → WaitMs(5)`（ST公式 Example_1 準拠）。
- **ハマりどころ（重要）**:
  1. **FW転送(84KB)・大容量転送でハング** → `RdMulti`/`WrMulti` を **128バイトずつ分割**（分割時はアドレスを `reg+処理済み` で進める）。
  2. **8bit/7bit アドレス**: ULD は 0x52（8bit）→ platform 層で `>>1`（0x29）して LPI2C に渡す。
  3. **全ゾーンの距離を常に出力**（status で捨てない）。status==255 は「対象なし」で距離0が正常。`debug_console_lite` の `%d` は負数を符号表示できない点も注意。
- **メモリ**: `VL53L5CX_Configuration` と `VL53L5CX_ResultsData` は **static** 配置。FW本体は `const` で Flash へ。

## AI推論（eIQ）

- カラス検出はまずルールベースで実装し、その後 **eIQ**（必要に応じて eIQ Neutron NPU）で軽量モデル推論へ拡張する。
- 学習データは、デバッグUART 経由で収集した差分マップ・特徴量を用いる。

---

関連: [hardware.md](./hardware.md) / [roadmap.md](./roadmap.md)

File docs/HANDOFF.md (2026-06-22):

# 引き継ぎメモ（セッション間の作業状態）

最終更新: 2026-06-22（コード分割・両センサ同時動作・1MHz化・NPU推論まで完了。実測 サーマル・距離とも 約7fps）

## プロジェクト概要

TerraGuard AI — DigiKey Make ONE Challenge 2026 向け。**FRDM-MCXN947 単体**（MCUXpresso SDK）で、
カラスなどの害鳥をサーマル+距離センサで検知するプライバシー配慮型エッジAI。
**今回のスコープ: カラス検出のみ。** 外部Arduino等の中継ボードは使わない。ROHM関連記述は禁止。

ルール: ドキュメント・チャットは**日本語**（[CLAUDE.md](../CLAUDE.md) 参照）。

## いまどこまで完了したか（✅）

### Step 1: 環境・疎通 — 完了
- ✅ ビルド・書き込み・デバッグ環境（CLI / VS Code 両方）
- ✅ LED点滅、シリアル出力（115200）動作確認
- ✅ **オンボード温度センサ P3T1755DP（I3C1, 0x48）の読み取りを `terra-guard-ai` プロジェクトに実装・実機確認・コミット済み**（約29℃出力）
- ✅ MCU-Link ファーム更新（V3.160）でVCOM復活
- ✅ ドキュメント・データシート・実装メモ・メモリ完備

### Step 2(前半): 外部I²C(MLX90640)疎通 — 完了
- ✅ **外部I²Cバス LPI2C2/FLEXCOMM2（P4_0=SDA / P4_1=SCL）を初期化**（`BOARD_InitI2CPins` + FC2クロックアタッチ + `prj.conf` に `driver.lpflexcomm_lpi2c`）。
- ✅ **配線は J8(FlexIO) pin1=3.3V / pin2=GND / pin3=SCL / pin4=SDA**（コネクタ実装済みでハンダ付け不要。J2 pin18/20 と同一 FC2 バス）。
- ✅ **起動時の I²Cバススキャンで MLX90640(0x33) の ACK を実機確認**（`led_blinky.c` の `i2c_bus_scan()`）。温度センサ(I3C)とも並行動作。
- 📝 訂正: 旧メモの「J7 は FC0 ベース」は誤り。J7 pin6/8 は **FC7_I2C**（独立バス, ただしコネクタDNP=要ハンダ）。外部I²Cの標準は J8/J2 の **FC2**。

### Step 2(後半): MLX90640 サーマルフレーム取得 — 完了
- ✅ **Melexis 公式 API(Apache-2.0) を `vendor/mlx90640/` に移植**。I²Cドライバ層 `mlx90640_i2c_lpi2c.c` だけ LPI2C2 で自前実装(BSD-3)。
- ✅ **32×24 の校正済み温度[℃]フレームを取得・シリアル出力**（2Hz/Chess、放射率0.95、tr=Ta-8）。室温で Ta≈31℃/min≈27.6/max≈33/avg≈28.8℃、P3T1755 と整合。
- ⚠️ **2大ハマりどころ（[datasheets/MLX90640.md](./datasheets/MLX90640.md) / [firmware.md](./firmware.md)）**:
  1. 大容量連続リードで `LPI2C_MasterTransferBlocking` がハング → `I2CRead` を32ワードずつ**分割読み出し**。
  2. `ExtractParameters` が `float[768]`(3KB)ローカル配列を使い 2KBスタックで **HardFault** → CMake で `__stack_size__=0x4000`。

### Step 2(完): VL53L5CX 8×8 距離取得 — 完了
- ✅ **ST 公式 ULD(BSD-3) を `vendor/vl53l5cx/` に移植**。platform 層 `vl53l5cx_platform_lpi2c.c` だけ LPI2C2 で自前実装。FW(84KB)転送→8×8/15Hz 測距。
- ✅ **全64ゾーンの距離[mm]を取得・出力**（`DIST,...` + `STAT,...`）。天井2.5m環境で center≈2000mm の妥当な奥行き勾配を確認。`tools/distance_viewer.py`(term/gui) で表示。
- ⚠️ **ハマりどころ**:
  1. FW転送(84KB)・大容量転送でハング → `RdMulti`/`WrMulti` を128バイト分割（アドレスを進める）。
  2. ULDは8bitアドレス0x52 → platformで `>>1`(0x29)。
  3. **全ゾーン距離を常に出す**（status で捨てない）。status==255=「対象なし」で距離0が正常。「一部画素取れない」はこれ。
  4. **flash中にシリアルを開くと VCOM 切断**（`Device not configured`）→ flash完了→ポート再列挙待ち→開く。

### Step 3(完): コード分割 + 両センサ同時動作 + 高速化 — 完了
- ✅ **センサごとにモジュール分割**: `led_blinky.c` を薄いオーケストレータに縮小し、`app/sensor_bus.{c,h}`（I3C/P3T1755/LPI2C 共通基盤）・`app/thermal_mlx90640.{c,h}`・`app/tof_vl53l5cx.{c,h}` に分離。
- ✅ **MLX90640 と VL53L5CX を同一 FC2 バスで同時動作**。アドレスが異なる(0x33/0x29)ためバス共存可。1ループで「VL53 を高頻度ポーリング → `DIST`/`STAT` 出力」「MLX は data-ready を**非ブロッキング確認**してから取得 → バイナリ`FRAME`出力」。
- ✅ **両方を同一シリアルへ出力** → `tools/dual_viewer.py` でサーマル(左)と距離(右)を1ウィンドウに並べてリアルタイム表示。
- ✅ **実測レート（実機）: サーマル・距離とも 約7fps、壊れフレーム0**。
- ✅ **市松模様の解消**: Chess は subpage 0/1 を市松状に交互測定するため、動体時は片サブページだけ更新されて市松模様になる。**0/1 両方が揃ってから1完成フレーム**として扱う（`thermal_mlx90640_poll_frame`）。
- ✅ **I²C を 1MHz(FM+) 化**（両センサとも公式最大1MHz）。**鍵は FC2 のクロック源**: FRO12M(12MHz) では 1MHz SCL を12分周でしか作れず波形が規格を満たさず通信不可だった。**FRO_HF(48MHz)→FRO_HF_DIV ÷2=24MHz を FC2 へ供給**し 1MHz SCL を綺麗に生成（`hardware_init.c`）。これで 100kHz 時代の 1.3/3.3fps から約5.5倍/3倍に。
- ✅ **シリアル高速化**: サーマルフレームは**バイナリ送出**（`0xAA 0x55` + Ta(int16) + 768×int16 = 1540B、`thermal_mlx90640_send_frame_bin`）で PRINTF の書式変換コストを回避。VCOM は **921600 baud**（`board.h`）。距離 DIST/STAT はテキストのまま（軽量）。`dual_viewer.py` がバイナリ＋テキスト混在を `extract_messages` でパース。
- ⚠️ **ポイント1**: MLX の `GetFrameData` は data-ready までブロックするため、先に status レジスタ(0x8000)の data-ready ビットだけを読んで準備済みのときのみ取得する。これで VL53(10Hz)のポーリングを阻害しない。
- ⚠️ **ポイント2**: MLX リフレッシュは **16Hz(完成8Hz狙い)が最良で実測 約7fps**。32Hz に上げると data-ready とポーリング間隔(VL53と交互)の同期がずれ逆に 5.9fps に低下した。
- ⚠️ **ポイント3（重要・ハマり）**: 高速化テスト等でセンサが**I²Cバスをロック**(SDA Low張り付き)すると、以後 probe/通信がハングし、MCU リセット（flash/run）では回復しない。**USB を抜き差しして電源リセット**すると解除される。`i2c_probe_addr` は NACK 検出＋タイムアウト＋STOP 解放で堅牢化済みだが、バスロック自体はソフトでは戻せない。

### コミット履歴（直近）
- `047f4b2` docs: ピンレイアウト図と外部センサI2C配線情報
- `eff5f05` docs: roadmapに温度センサ実装完了
- `725fac1` feat: オンボード温度センサP3T1755DP(I3C)読み取り実装 ← **動作する実装**
- `a84b745` docs: 開発手順の実績反映
- `a2f3585` docs: MLX90640/VL53L5CX/FRDM-MCXN947の実装メモとデータシート

## 開発環境（重要・確立済み）

🛠️ **ビルド・書き込み・シリアル確認・ビューア・west サンプルビルドの実行コマンドは
`frdm-mcxn947-dev` スキルに一本化**してある。開発作業を行うときは、まず
`frdm-mcxn947-dev` スキルを起動し、その確定パス・手順に従うこと。
（成果物 ELF は `src/FRDM-MCXN947/terra-guard-ai/debug/terra-guard-ai_cm33_core0.elf`、
シリアルは 921600、ビューアは `tools/dual_viewer.py` 等を使用。）

## 重要な教訓（ハマりどころ）

1. **UART(FC4)の pin_mux 必須**: `BOARD_InitPins` に P1_8/P1_9(FC4, MuxAlt2)を入れないと PRINTF が物理ピンに出ず無音。
2. **クロックアタッチ + pin_mux の3点セット**: I2C/I3C/UART すべて「pin_mux + CLOCK_AttachClk (+リセット)」が必要。漏れるとハング or 無音。
3. **debug_console_lite は %f 非対応**: 温度等は整数演算で小数表示する。
4. **west は mcux venv の python/west を使う**: システムPython(3.14)は yaml が無く失敗。
5. **MCU-Link ファーム古いとVCOM不調**: J21ショート→`MCU-LINK_installer/scripts/program_CMSIS -s`→J21戻す（[datasheets/README.md](./datasheets/README.md)）。
6. **オンボードは温度センサのみ**（加速度センサFXLS8974CFは非搭載。SDK汎用board.cの定義に注意）。
7. **I²C 大容量連続リードはハングする**: MLX90640 の EEPROM(832ワード)/画素(768ワード)を `LPI2C_MasterTransferBlocking` で一括読みすると固まる → **32ワードずつ分割読み出し**（`mlx90640_i2c_lpi2c.c`）。
8. **大きなローカル配列でスタックオーバーフロー→HardFault**: 公式 `ExtractParameters` が `float[768]`(3KB)を複数使う。デフォルト2KBでは落ちる → CMake `mcux_add_linker_symbol(SYMBOLS __stack_size__=0x4000)`。ログが途中で止まりリセットもしない症状はこれを疑う。

## 現状の構成（`led_blinky.c`）
起動シーケンス: ①I²Cバススキャン(ACK確認) → ②I3C温度センサ(P3T1755)初期化 → ③MLX90640初期化(2Hz/Chess/DumpEE/ExtractParameters) → ④ループでサーマルフレーム取得・温度統計表示（数フレームごとにP3T1755も参考表示）。I3C(温度)とLPI2C(サーマル)は独立バスで並行動作。

## 次にやること: Step 4 — 前処理（両センサ同時取得まで完了）

### 配線（確定済み・実機確認済み・[hardware.md](./hardware.md) / [pin-layout.png](./pin-layout.png)）
外部I²Cセンサ（MLX90640=0x33, VL53L5CX=0x29）は **J8(FlexIO) pin1〜4** に共存接続。バスは **LPI2C2 / FLEXCOMM2**（P4_0/P4_1）。

| センサ側 | 接続先 |
| --- | --- |
| VCC | **J8 pin1**（P3V3 / 3.3V） |
| GND | **J8 pin2** |
| SCL | **J8 pin3**（P4_1 / FC2_I2C_SCL） |
| SDA | **J8 pin4**（P4_0 / FC2_I2C_SDA） |

- 信号は 3.3V レベル。J8 はコネクタ実装済みでハンダ付け不要。両センサとも実機で ACK・データ取得確認済み。
- J2 pin18/20 も同一 FC2 バス。別系統の独立 I²C が要るときのみ J7(FC7, DNP=要ハンダ)。

### 進め方の推奨
1. ✅ サーマル(MLX90640) 32×24 温度[℃]取得 — **完了**
2. ✅ 距離(VL53L5CX) 8×8 距離[mm]取得 — **完了**
3. ✅ **コード分割 + 両センサ同時動作 + 高速化** — **完了**。`app/` にセンサ別モジュール分割。1MHz(FRO_HF クロック源)＋バイナリFRAME＋921600baud で **サーマル・距離とも 約7fps**。`tools/dual_viewer.py` で2画面同時表示。
4. **前処理**（[sensor-processing.md](./sensor-processing.md)）: サーマルは**取得直後に 32×24→`rotate_crop`→24×24** に整え、以降の背景差分・特徴量化・NPU入力まですべて 24×24 で行う（旧「16×12縮小」は廃止）。距離は 8×8 の背景差分。
   重心/変化量/面積などを特徴量化（`thermal_mlx90640` の 24×24 温度配列と `tof_vl53l5cx` の距離データが入力）。
5. その後 **カラス検出判定**（まずルールベース、のちに eIQ/Neutron NPU）。

## 参照ドキュメント
- [datasheets/FRDM-MCXN947.md](./datasheets/FRDM-MCXN947.md) — ボード・ピン・クロック
- [datasheets/MLX90640.md](./datasheets/MLX90640.md) — サーマルセンサ
- [datasheets/VL53L5CX.md](./datasheets/VL53L5CX.md) — 距離センサ
- [firmware.md](./firmware.md) — ビルド/書き込み/トラブル対処
- [hardware.md](./hardware.md) — 配線・ピン配置
- [roadmap.md](./roadmap.md) — 開発ステップ

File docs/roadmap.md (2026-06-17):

# 開発ロードマップ

開発はすべて **NXP FRDM-MCXN947 単体**（MCUXpresso SDK）で行う。センサは FRDM-MCXN947 に直接 I2C 接続する。

> **今回のゴール: カラスの検出まで（Step 1〜4）。** 多状態分類・追い払い機構は後続。

## Step 1: 開発環境とボード疎通 ✅ 完了

- ✅ MCUXpresso SDK + VS Code 拡張のセットアップ
- ✅ FRDM-MCXN947 のLED点滅で書き込み・デバッグ（MCU-Link）を確認
- ✅ デバッグUART（仮想COM, 115200）でのログ出力を確認（hello_world）
- ✅ オンボード温度センサ P3T1755DP（I3C, 0x48）を読み、約29℃をシリアル出力確認
  → **I3C・シリアル・センサ通信の一連が動作することを実証**
- ✅ **`terra-guard-ai` プロジェクト本体に温度センサ読み取りを実装・コミット済み**
  （I3C動的アドレス割当 → P3T1755_Init → 1秒周期で温度をUART出力）
- ✅ CLI でのビルド(`cmake --preset/--build`)・書き込み(LinkServer)・west サンプルビルドを確立
- ✅ MCU-Link ファーム更新手順を確立（[datasheets/README.md](./datasheets/README.md)）

### Step 1 で得た実装上の要点（[firmware.md](./firmware.md) 参照）

- **UART(FC4)ピンの pin_mux 設定が必須**（漏れると PRINTF が物理ピンに出ず無音）
- **クロックアタッチ + pin_mux の3点セット**（I3C/UART共通。漏れるとハングor無音）
- **debug_console_lite は `%f` 非対応** → 温度は整数演算で小数表示
- I3C は PLL0 を使うため `BOARD_InitBootClocks()`(PLL150M) が必要

## Step 2: センサ取得（外部センサ I2C 直結）

- ✅ **外部I²Cバス LPI2C2/FC2（J8 pin1〜4）を確立、MLX90640(0x33)・VL53L5CX(0x29)を同一バスで2台検出**
- ✅ **MLX90640 のサーマル画像取得（32×24, I²C 0x33）完了** — Melexis公式API移植、2Hz/Chess、放射率0.95/tr=Ta-8で温度[℃]をUART出力。室温で妥当値を実機確認
- ✅ **VL53L5CX の 8×8 距離データ取得（I²C 0x29, ULD）完了** — ST公式ULD移植、FW(84KB)転送→8×8/15Hz。全64ゾーンの距離[mm]をUART出力。天井2.5m環境で妥当値を実機確認
- ✅ 取得データをデバッグUARTで確認（サーマル: Ta/min/max/avg/center、距離: DIST/STAT 全ゾーン）。`tools/` に Python ビューア

### Step 2 で得た実装上の要点（[datasheets/MLX90640.md](./datasheets/MLX90640.md) / [datasheets/VL53L5CX.md](./datasheets/VL53L5CX.md) / [firmware.md](./firmware.md)）

- **I²C 大容量連続リード/ライトはハングする** → MLX90640は32ワード、VL53L5CXは128バイトで分割転送
- **公式 `ExtractParameters` が `float[768]` ローカル配列で HardFault** → スタックを `__stack_size__=0x4000` に拡張
- 公式ドライバは `vendor/` に隔離（MLX90640=Apache-2.0, VL53L5CX=BSD-3）、I²C層のみ自前(BSD-3)
- **VL53L5CX は全ゾーンの距離を常に出力**（status で捨てない）。status==255=「対象なし」で距離0が正常
- **flash中にシリアルを開くと VCOM 切断**（`Device not configured`）→ flash完了→ポート再列挙待ち→開く

## Step 3: 差分・特徴量

- 通常状態の背景データ取得
- サーマル差分マップ / 距離差分マップ生成
- 平均/最大変化量・重心位置・移動量・継続時間などの特徴量抽出

## Step 4: カラス検出（今回のゴール）

- ルールベースでカラスの有無を判定
- ダミーカラス実験で検出が動くことを確認
- （発展）eIQ / Neutron NPU による軽量モデル推論へ拡張

## Step 5: 多状態分類への拡張（後続）

- 「人によるゴミ出し」のデータ収集とロジック追加
- 通常 / カラス / 人 の分類

## Step 6: 追い払い機構の追加（後続）

- LED
- ブザー
- サーボ
- 音声
- 水噴射 など

検出から追い払いまでの一連の動作をデモとして仕上げる。

---

関連: [overview.md](./overview.md) / [demo.md](./demo.md)

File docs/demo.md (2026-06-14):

# デモ構成 — 仮想ゴミ置き場・実験手順

> **今回のスコープ: カラス検出のデモ。** FRDM-MCXN947 にセンサを直接接続し、カラスを検出できることを示す。

## 仮想ゴミ置き場

- ゴミ入りゴミ袋を 5〜6 個設置
- USBヒーターを 40℃ 程度に設定
- 鳥ぬいぐるみに USBヒーターまたはカイロを組み込む（ダミーカラス）
- ダミーカラスに棒を取り付け、センサ視野外から動かせるようにする

---

## デモ動作（カラス検出）

```text
1. 通常状態
   ゴミ袋だけを設置し、背景データを取得する（カラスなし）

2. カラスゴミ漁り状態
   ヒーター入りダミーカラスをゴミ袋付近で動かす

3. 検出結果表示
   FRDM-MCXN947 がカラスを検出したら、オンボードLED等で通知する
   （検証用にデバッグUART/MCU-Link経由でサーマル・距離・特徴量・判定を出力）
```

ポイント：

- 「通常状態 → カラス出現 → 検出」の流れを実演する
- 検出のオン/オフがダミーカラスの動きに追従することを示す

---

## 検証用の出力（開発時）

開発・チューニング時には、ボードから以下を確認できるようにする。FRDM-MCXN947 のデバッグUART（MCU-Link 経由の仮想COM）でPCへ送る想定。

- サーマルマップ / サーマル差分マップ
- 距離マップ / 距離差分マップ
- 抽出特徴量
- カラス検出の判定結果

これにより、センサが何を捉えているかを確認しながらしきい値やモデル入力を調整できる。

---

## 追い払い動作（将来）

カラス検出が安定したら、検出結果に応じて追い払い動作を追加する。

- LED
- ブザー
- サーボ
- 音声
- 水噴射 など

詳細は [roadmap.md](./roadmap.md) を参照。

---

関連: [sensor-processing.md](./sensor-processing.md) / [firmware.md](./firmware.md)

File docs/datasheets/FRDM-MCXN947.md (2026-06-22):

# FRDM-MCXN947 実装メモ

TerraGuard の中核ボード。MCUXpresso SDK で開発（[../firmware.md](../firmware.md)）。

- 原本: [`UM12018_FRDM-MCXN947_User_Manual_Rev2.0.pdf`](./FRDM-MCXN947/UM12018_FRDM-MCXN947_User_Manual_Rev2.0.pdf)（NXP UM12018, Rev 2.0）
- クイックスタート: [`FRDM-MCXN947-QSG.pdf`](./FRDM-MCXN947/FRDM-MCXN947-QSG.pdf)、基板図: [`FAB_90818_C.pdf`](./FRDM-MCXN947/FAB_90818_C.pdf)
- ジャンパ早見表・MCU-Linkリカバリ手順は [README.md](./README.md) を参照

## MCU 仕様

| 項目 | 値 |
| --- | --- |
| MCU | MCXN947（デュアル Arm Cortex-M33、最大150MHz） |
| AI | DSP コプロセッサ + **eIQ Neutron NPU** |
| Flash | 2MB デュアルバンク（内蔵） + 64Mbit QSPI外部Flash（Winbond W25Q64） |
| RAM | 512KB |
| デバッガ | オンボード **MCU-Link**（LPC55S69ベース、USB Type-C J17） |

## オンボード実装部品（UM12018で確認・確定）

| 部品 | 種別 | 接続 | 備考 |
| --- | --- | --- | --- |
| **P3T1755DP** | **温度センサ** | **I3C1**（P1_16/P1_17, アドレス0x48） | 唯一のオンボード環境センサ |
| W25Q64JVSSIQ | 64Mbit QSPI Flash | FlexSPI | 実装済み |
| LAN8741 | Ethernet PHY | ENET0 | RJ45コネクタ |
| TJA1057GTK/3Z | CAN PHY | FlexCAN | 4ピンCAN FDコネクタ |
| RGB LED | LED | GPIO | 赤=オンボードLED（Lチカで使用） |
| Touch pad | 静電容量タッチ | TSI | — |
| Push buttons | ボタン（SW2/SW3等） | GPIO | SW3はISPモードスイッチ |
| SDHC | microSDスロット | uSDHC | **カードスロットはDNP（未実装）** |

> ⚠️ **加速度センサ(FXLS8974CF)は搭載されていない。** SDKの汎用 board.c に `BOARD_ACCEL_I2C`（LPI2C2）の定義があるが、これは別ボード向けの汎用コードで、FRDM-MCXN947 の実機には加速度センサが無い。オンボードで使える環境センサは温度センサ P3T1755DP（I3C, 0x48）のみ。

## オンボード温度センサ P3T1755DP

| 項目 | 値 |
| --- | --- |
| 種別 | デジタル温度センサ、12bit、±0.5℃（-20〜+85℃） |
| バス | **I3C1**（I2C互換アクセスも可） |
| ピン | **P1_16 = I3C1_SCL / P1_17 = I3C1_SDA** |
| プルアップ | P1_11/I3C1_PUR が 1kΩ(R53)経由でPUR制御 |
| アドレス | **0x48**（7bit I2C） |
| アラート | プログラム可能な過温度アラート出力 |

## センサ拡張ヘッダ（外部センサ接続用）

MLX90640 / VL53L5CX などの外部I²Cセンサは以下のヘッダに接続:

| ヘッダ | 用途 |
| --- | --- |
| **J3 / J4** | Arduino互換（外側）/ FRDM（内側）ヘッダ。I²C(SCL/SDA)ピンあり |
| **J6** | mikroBUS ヘッダ（I²C/SPI/UART/AN/PWM/INT） |
| J7 | Pmod コネクタ（DNP） |
| J5 | SmartDMA / カメラ |
| J8 | FlexIO / LCD |

> 外部I²Cセンサは Arduino ヘッダの SCL/SDA、または mikroBUS の I²C ピンに接続する。実際のポート/FLEXCOMM番号は MCUXpresso Config Tools の pin_mux で割り当てる。

## クロックとペリフェラルの注意（実装で重要）

MCXN947 の LPFLEXCOMM / I3C を使うときは、**ピンmux + クロックアタッチ + リセット解除**の3点セットが必要:

```c
/* 例: FLEXCOMMn を使う場合 */
CLOCK_SetClkDiv(kCLOCK_DivFlexcomNClk, 1u);
CLOCK_AttachClk(kFRO12M_to_FLEXCOMMn);   /* クロック源アタッチ */
/* + pin_mux で SCL/SDA を該当ピンに割当 */
/* + 必要に応じて RESET_ClearPeripheralReset(...) */
```

> 教訓: クロックアタッチ漏れ → I²C転送がハング。pin_mux漏れ → 信号が物理ピンに出ない（UARTなら出力されない、I²Cなら通信不可）。デバッグUART(FC4)・センサバス、どちらもこの3点を揃えること。

## デバッグUART（シリアル / PRINTF）

| 項目 | 値 |
| --- | --- |
| ペリフェラル | **LPUART4 (FLEXCOMM4)** |
| ピン | **P1_8 = FC4_P0 (TX) / P1_9 = FC4_P1 (RX)**（MuxAlt2） |
| クロック | kFRO12M_to_FLEXCOMM4 |
| ボーレート | **115200**（8N1） |
| 経路 | MCU-Link 仮想COM (VCOM) → PC |

> シリアルが出ないときは: ①J18オープン(VCOM有効) ②MCU-Linkファーム最新 ③pin_mux(P1_8/P1_9) ④FC4クロックアタッチ を確認（[README.md](./README.md)）。

## ビルド・書き込み（CLI）

🛠️ ビルド・書き込みの実行コマンドは `frdm-mcxn947-dev` スキルに一本化してある。
ビルド／書き込みを行うときは、まず `frdm-mcxn947-dev` スキルを起動してその手順に従うこと。

## MCU-Link ファーム更新（VCOM不調・USB消失時）

詳細は [README.md](./README.md) のリカバリ手順を参照。要点:
1. USB抜く → **J21ショート**（強制ISPモード）→ USB挿す
2. `MCU-LINK_installer/scripts/program_CMSIS -s` でファーム書き込み
3. **J21オープンに戻す** → USB再接続

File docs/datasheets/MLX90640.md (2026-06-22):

# MLX90640（サーマルセンサ 32×24）実装メモ

TerraGuard で使うサーマルセンサ。**110°広角版**（SparkFun Breakout は標準55°版なので、視野角の違いに注意）。

- 原本データシート: [`MLX90640_Datasheet_Melexis.pdf`](./MLX90640_Datasheet_Melexis.pdf)（Melexis, Rev.11）

## 基本仕様

| 項目 | 値 |
| --- | --- |
| 画素数 | **32×24 = 768画素**（FIR） |
| インターフェース | **I²C**（最大1MHz、EEPROMアクセス時は400kHzまで） |
| **I²C スレーブアドレス** | **0x33**（デフォルト、プログラム可能） |
| 電源電圧 | **3.3V** |
| リフレッシュレート | 0.5Hz〜64Hz（プログラム可能） |
| NETD | 0.1K RMS @1Hz |
| 視野角 | 今回は **110°版**（広角） |
| 測定対象温度 | -40℃〜300℃ |

## メモリ／レジスタ構成（16bitワード単位、I²Cは16bitアドレス）

| 領域 | アドレス範囲 | 用途 |
| --- | --- | --- |
| EEPROM | 0x2400〜0x273F | 校正パラメータ（起動時に全部読み出して保持） |
| RAM | 0x0400〜0x073F | 画素データ・Ta・VDD等（測定結果） |
| Status register | **0x8000** | サブページ更新フラグ、データ準備完了 |
| Control register1 | **0x800D** | リフレッシュレート、解像度、読み出しパターン（chess/interleaved）、サブページモード |
| I²C config register | **0x800F** | I²C動作設定 |

### Status register (0x8000) 主要ビット
- データ準備完了フラグ（新フレーム取得済み）
- どのサブページ(0/1)が更新されたか

### Control register1 (0x800D) 主要設定
- リフレッシュレート設定
- 解像度（ADC）
- 読み出しパターン: **Chess pattern（工場デフォルト・推奨）** / Interleaved
- サブページモード有効化

## 読み出しの基本フロー

```text
1. 起動時: EEPROM(0x2400〜)を全読み出し → 校正パラメータをRAMに保持
2. Control register1 (0x800D) でリフレッシュレート・パターン設定
3. ループ:
   a. Status register (0x8000) をポーリングし、新データ準備完了を待つ
   b. RAM (0x0400〜) からサブページの画素データを読む
   c. 校正パラメータを使って生データ → 温度[℃] に変換
   d. サブページ0と1の両方が揃うと1フレーム(32×24)完成
```

> MLX90640 は1フレームを2サブページ（chessパターン）に分けて更新する。32×24の全画素を得るには両サブページを読む。

## TerraGuard での前処理（[../sensor-processing.md](../sensor-processing.md)）

- **取得直後に 32×24（生）→ `rotate_crop`（90度右回転＋中央24行crop）→ 24×24=576** に整える（センサを90度回転して取り付けているため）。**以降のすべての処理（背景差分・特徴量化・バイナリ送出・NPU入力・データ収集）は 24×24 で行う**（旧設計の「16×12縮小」は廃止）。
- 背景差分・時間差分
- 平均/最大温度変化量、熱源の重心・移動量、変化継続時間 を特徴量化

## FRDM-MCXN947 への接続

- **I²C**（LPI2C または I3C のI²C互換モード）で接続。Arduino R3 / mikroBUS ヘッダを利用。
- 3.3V 電源。SCL/SDA にプルアップ必要（Breakout基板に実装済みのことが多い）。
- VL53L5CX と同一バス共存可（アドレス 0x33 と 0x29 で衝突しない）。

## ライブラリ（実装済み）

- **Melexis 公式ドライバ（Apache-2.0）を移植して使用**。MCUXpresso SDK には専用コンポーネントが無い。
- 配置: `src/FRDM-MCXN947/terra-guard-ai/vendor/mlx90640/`
  - `MLX90640_API.c` / `.h` … 公式原文（EEPROM展開・温度変換、OS非依存。`math.h` のみ）。
  - `MLX90640_I2C_Driver.h` … 公式原文（プロトタイプ宣言）。
  - `mlx90640_i2c_lpi2c.c` … **自前(BSD-3)** の I²Cドライバ層。`LPI2C_MasterTransferBlocking`
    （`subaddress`=16bitレジスタ, `subaddressSize=2`, MSBファースト）で実装。
- 主要 API 呼び出し順（実装済み・`led_blinky.c`）:
  `SetRefreshRate(2Hz) → SetChessMode → DumpEE → ExtractParameters`（起動時1回）→
  ループで `GetFrameData → GetTa → CalculateTo(放射率0.95, tr=Ta-8)`。

## ✅ 動作確認済み（2026-06-17）

- J8 pin1〜4（LPI2C2/FC2）に接続し、32×24 の校正済み温度[℃]フレームを取得・シリアル出力。
- 室温で Ta≈31℃ / 画素 min≈27.6℃・max≈33℃・avg≈28.8℃。オンボード温度センサ(P3T1755, I3C)とも整合。
- フレームを Python（`tools/thermal_viewer.py`）で受信しヒートマップ化。手をかざすと体温域(36℃)がはっきり写る。

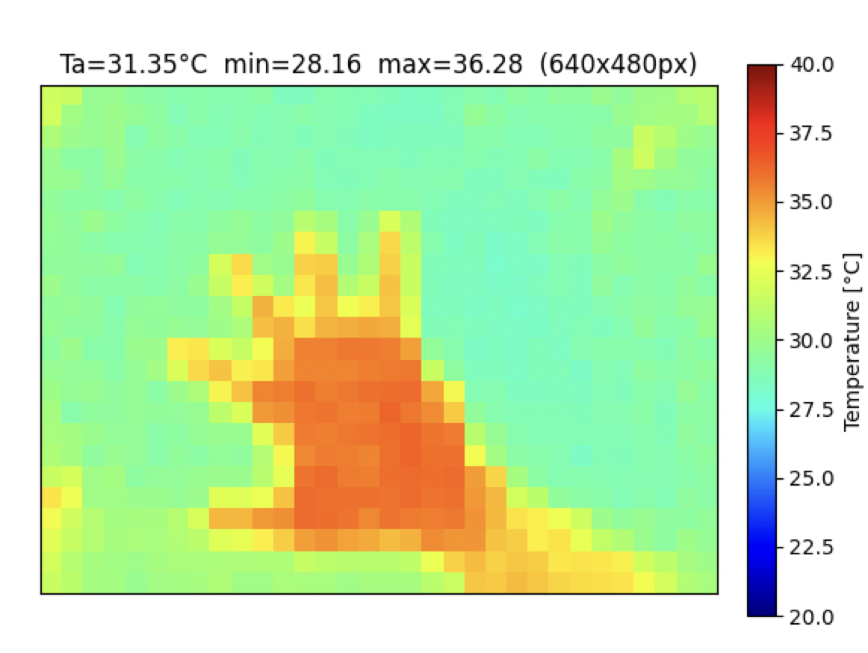
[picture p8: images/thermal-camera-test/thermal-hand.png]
サーマルカメラ動作テスト（手をかざした例, 640×480px）


## 実装上のハマりどころ（重要）

1. **大容量連続リードでハング**: EEPROM(832ワード=1664B) や画素(768ワード)を LPI2C の単一
   トランザクションで読むと `LPI2C_MasterTransferBlocking` がハングする。
   → `MLX90640_I2CRead` を **32ワードずつ分割読み出し**に実装（アドレスを更新して連続読み）。
2. **スタックオーバーフロー → HardFault**: `MLX90640_ExtractParameters` 内の
   `ExtractAlpha/Kta/KvPixelParameters` が `float[768]`(各3KB) のローカル配列を使う。
   デフォルトスタック 0x800(2KB) では溢れて HardFault。
   → CMake で `mcux_add_linker_symbol(SYMBOLS __stack_size__=0x4000)` に拡張。
3. スキャン(低レベル Start/Stop)後はバス状態をクリーンにするため、フレーム取得前に LPI2C を再初期化。

## 注意点

- EEPROM書き換え時は事前に該当セルへ 0x0000 を書く（消去）必要あり。
- 110°版は広角ゆえ周辺画素の歪み・感度低下に注意。
- 16bitレジスタアドレス・16bitデータのMSBファースト。
- Chess パターンでは1フレーム=サブページ0/1の両方。起動直後の1フレーム目は片サブページのみで
  min/center が 0 になることがある（2フレーム目以降は正常）。

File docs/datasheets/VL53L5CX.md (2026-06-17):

# VL53L5CX（ToF 距離センサ 8×8）実装メモ

TerraGuard で使う Time-of-Flight マルチゾーン距離センサ。

- ULDガイド（実装の主資料）: [`UM2884_VL53L5CX_ULD_Guide.pdf`](./UM2884_VL53L5CX_ULD_Guide.pdf)（ST UM2884）
- データシート本体（DS13754）は ST サイト参照: <https://www.st.com/resource/en/datasheet/vl53l5cx.pdf>
  （bot除けにより自動DL不可だったため未格納。必要時に手動取得）

## 基本仕様

| 項目 | 値 |
| --- | --- |
| 測距ゾーン | **4×4 または 8×8**（マルチゾーン） |
| 視野角 (FoV) | 63°対角（ソフトで縮小可） |
| 測距範囲 | 最大 **400cm** |
| フレームレート | 最大 **60Hz**（8×8時は最大15Hz程度） |
| インターフェース | **I²C**（最大1MHz）/ SPI |
| **I²C アドレス** | **0x52**（8bit表記、デフォルト）= 7bit表記 **0x29** |
| 電源 | 3.3V または 2.8V（IOVDD 1.8V併用可） |
| パッケージ | 6.4 × 3.0 × 1.5 mm |

> アドレス表記注意: STは **8bit表記 0x52** を使う。多くのMCU I²C APIは7bit表記なので **0x29** を渡す。

## ULD（Ultra Lite Driver）の構成

VL53L5CX は「ハードウェア + ホスト上で動く ULD ソフト」で構成。**センサ内蔵RAMにファームウェア(~84KB)をI²Cで転送してから動作**する点が他センサと大きく異なる。

### Platform層の自前実装が必須
`/Platform` フォルダの2ファイルをターゲット(FRDM-MCXN947)向けに実装する:

- **platform.h**: 必須マクロ定義（I²Cアドレス、バッファ形式など）
- **platform.c**: 以下のI²C low-level関数をMCUXpresso LPI2C/I3Cで実装
  - `VL53L5CX_RdByte` / `VL53L5CX_WrByte`
  - `VL53L5CX_RdMulti` / `VL53L5CX_WrMulti`（マルチバイト転送。FW転送で必須）
  - `VL53L5CX_WaitMs`（ミリ秒待ち）
  - （任意）`VL53L5CX_Reset_Sensor`, `SwapBuffer`

## 初期化〜測距の基本フロー（ULD API）

```text
1. platform.c の I²C 関数を実装
2. VL53L5CX_Dev 構造体に I²Cアドレス等を設定
3. vl53l5cx_is_alive()           … センサ存在確認
4. vl53l5cx_init()               … FW(~84KB)をI²Cで転送（数十ms〜）
5. vl53l5cx_set_resolution(8x8)  … 解像度設定（4x4 or 8x8）
6. vl53l5cx_set_ranging_frequency_hz(...) … フレームレート
7. vl53l5cx_start_ranging()      … 測距開始
8. ループ:
   a. vl53l5cx_check_data_ready() で新データを待つ
   b. vl53l5cx_get_ranging_data() で結果取得
      → 各ゾーンの距離[mm]・ステータスが得られる(8x8=64ゾーン)
```

## 主要API（ULD）

| 関数 | 用途 |
| --- | --- |
| `vl53l5cx_is_alive()` | デバイス存在確認 |
| `vl53l5cx_init()` | FW転送・初期化（必須・重い） |
| `vl53l5cx_set_resolution()` | 4×4 / 8×8 |
| `vl53l5cx_set_ranging_frequency_hz()` | フレームレート |
| `vl53l5cx_start_ranging()` / `stop_ranging()` | 測距開始/停止 |
| `vl53l5cx_check_data_ready()` | 新データ準備確認 |
| `vl53l5cx_get_ranging_data()` | 距離データ取得（mm） |
| `vl53l5cx_set_i2c_address()` | アドレス変更（複数台共存時） |

## TerraGuard での前処理（[../sensor-processing.md](../sensor-processing.md)）

- 8×8 距離マップをそのまま特徴量に利用
- 背景差分・時間差分
- 平均/最大距離変化量、変化領域の重心・面積、ゴミ袋表面の形状変化、小刻みな動きの有無

## FRDM-MCXN947 への接続

- **I²C**（LPI2C / I3CのI²C互換）。Arduino R3 / mikroBUS ヘッダを利用。
- 3.3V電源。SCL/SDA プルアップ必要。
- MLX90640(0x33) と同一バス共存可（0x29 と衝突しない）。
- LPn / I2C_RST ピンは、複数台でアドレス変更する場合に制御。単体なら固定でよい。

## 複数台を同一バスに繋ぐ場合

各デバイスの **LPn ピンで1台ずつ有効化 → `vl53l5cx_set_i2c_address()` で別アドレスに変更** していく（デフォルト0x52同士は衝突するため）。TerraGuardでは1台想定なので通常不要。

## ライブラリ（実装済み）

- **ST 公式 VL53L5CX ULD（BSD-3-Clause）を移植して使用**。配置: `src/FRDM-MCXN947/terra-guard-ai/vendor/vl53l5cx/`
  - `vl53l5cx_api.c` / `.h` … ULD コア（ST公式原文）。
  - `vl53l5cx_buffers.h` … **約84KBのファームウェア本体**（22000行/550KB。起動時にセンサへ転送）。
  - `platform.h` … ST公式 porting テンプレート原文（6関数プロトタイプ + マクロ）。
  - `vl53l5cx_platform_lpi2c.c` … **自前(BSD-3)** のプラットフォーム層。LPI2C2 で I²C を実装。
  - `LICENSE.md` … ST の BSD-3 条文（保持）。
- 取得元: `STMicroelectronics/stm32-vl53l5cx`（modules/ と porting/）。
- 主要 API 呼び出し順（実装済み・`led_blinky.c` の `vl53l5cx_setup()`）:
  `is_alive → init(FW転送) → set_resolution(8X8) → set_integration_time_ms(20) → set_ranging_frequency_hz(10) → start_ranging`
  → ループ `check_data_ready → get_ranging_data`。
- **積分時間の設定で低信頼ゾーンを低減**: `set_integration_time_ms` は `set_ranging_frequency_hz` の**前**に呼ぶ。
  積分時間を伸ばすと遠距離・弱反射ゾーンの信頼度が上がり、status==255 が減る（実機で 30%→15%）。
  制約: integration は **2〜1000ms** かつ **< (1000/freq − 4)ms**（10Hzなら最大96ms、15Hzなら62ms）。8×8 の最大レートは 15Hz。

## ✅ 動作確認済み（2026-06-17）

- MLX90640 と同じ FC2 バス（J8）に共存（0x29 と 0x33、I²Cスキャンで2台検出）。
- 8×8 の距離[mm]マップを取得・シリアル出力。正面2.5mに天井がある環境で **center≈2000mm / avg≈1800mm** と妥当な奥行き勾配を確認。
- **全64ゾーンの距離を常に出力**（ST公式 `Example_1_ranging_basic` に準拠。status でゾーンを捨てない）。
  status==255 のゾーンも distance_mm は妥当な値を持つ（例: 天井2.3m）。**距離は捨てず、status は信頼度ラベルとして別途見る**。
- 10Hz / 積分時間20ms で **高信頼ゾーン 57〜60/64** を安定取得。
- 出力形式（`led_blinky.c` の `vl53l5cx_print_frame()`）:
  - `DIST,z0,...,z63` … 全64ゾーンの距離[mm]（status不問）
  - `STAT,s0,...,s63` … 各ゾーンの target_status（受信側で信頼度フィルタ可能）
- Python ビューア `tools/distance_viewer.py`（term/gui）で 8×8 を表示。全ゾーンを色表示し、status==255 は括弧/`*` で区別（白抜けなし）。

### target_status の意味（UM2884）— 「全画素が取れない」の理解に必須
- **5** = 100% 有効（最高信頼）
- **6 / 9** = 50%以上の信頼度（実用可）
- **10** = range valid だが wrap-around の可能性
- **255** = **測距範囲内に対象なし**（4m超 or 反射が弱い方向）。距離は 0 が返る。**センサの正常動作**であり故障ではない。
- → 「一部ゾーンが取れない」と見えるのは status==255（その方向に物理的に対象が無い）か、status で隠していたのが原因。
  公式どおり**全ゾーンの距離を出し、status を別途見て判断**するのが正しい。

## 実装上のハマりどころ（重要）

1. **FW転送(84KB)・大容量転送でハング**: `vl53l5cx_init` は FW を `WrMulti(addr=0, &FW[off], 0x8000)` を3回で転送する。
   LPI2C の単一トランザクションで32KBを送るとハングするため、`RdMulti`/`WrMulti` を **128バイトずつ分割**で実装。
   分割時は **レジスタアドレスを進める**（`reg + 既処理バイト数`。ST公式 HAL と同じ流儀）。
2. **8bit/7bit アドレス**: ULD は `VL53L5CX_DEFAULT_I2C_ADDRESS=0x52`（8bit表記）。LPI2C は7bitを要求するので platform 層で `>>1`（=0x29）して渡す。
3. **`debug_console_lite` の `%d` は負数を符号表示できない**（neg を無視する実装）。無効ゾーンの `-1` は自前で `",-1"` を出力する。
4. **メモリ**: `VL53L5CX_Configuration`（temp_buffer 等内包, 数KB）と `VL53L5CX_ResultsData` は **static 配置**（スタックに置かない）。FW本体は `const` で Flash に載る。
5. **連続取得ループは ST公式 `Example_1_ranging_basic` に準拠**: `check_data_ready` → ready なら `get_ranging_data` → `WaitMs(5)`。ゾーン読み出しは `distance_mm[VL53L5CX_NB_TARGET_PER_ZONE * i]`。
6. **flash 中はシリアルを開かない**（環境依存の重要点）: `LinkServer flash` 実行中に VCOM を開いていると MCU-Link がリセットで一旦消え、`Device not configured` でハングに見える。**flash 完了 → ポート再列挙を待つ（`ls /dev/cu.usbmodem*`）→ 開く** 順にする。「無音=ハング」と早合点しない。
7. **「近距離で数秒固定」はセンサでなく Python GUI の描画ブロックが原因**だった: matplotlib ビューアで `ser.read(timeout=1)` がデータ待ちで最大1秒固まり、描画が止まって見えた。センサ側は stream カウンタが常時更新され値固定なし（直接シリアル読みで確認）。対策: GUIは **timeout を短く(0.02s) + `in_waiting` でノンブロッキング読み + 溜まった分は最新フレームのみ描画**（`tools/distance_viewer.py`）。

## ライブラリ（旧メモ）

- ST 公式 **VL53L5CX ULD** をダウンロードし、`/Platform` を FRDM-MCXN947 の LPI2C/I3C 向けに実装して組み込む。

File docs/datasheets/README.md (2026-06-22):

# データシート・マニュアル

FRDM-MCXN947 や各センサの公式ドキュメントを格納する。

## 実装メモ（要約 Markdown）

各デバイスの実装に必要な情報を日本語で要約。まずこちらを読み、詳細は原本PDFを参照。

| メモ | 対象 |
| --- | --- |
| [FRDM-MCXN947.md](./FRDM-MCXN947.md) | ボード仕様・オンボード部品・UART/I2C/I3Cピン・クロック注意点 |
| [MLX90640.md](./MLX90640.md) | サーマルセンサ 32×24（I²C 0x33、レジスタ、読み出しフロー） |
| [VL53L5CX.md](./VL53L5CX.md) | ToF距離センサ 8×8（I²C 0x52/0x29、ULD、Platform実装） |

## 原本ファイル一覧（PDF）

FRDM-MCXN947 関連は `FRDM-MCXN947/` サブフォルダにまとめてある。

| ファイル | 内容 | 出典 |
| --- | --- | --- |
| `FRDM-MCXN947/UM12018_FRDM-MCXN947_User_Manual_Rev2.0.pdf` | FRDM-MCXN947 ボードユーザーマニュアル（Rev 2.0, 2024-08-23） | NXP UM12018 |
| `FRDM-MCXN947/FRDM-MCXN947-QSG.pdf` | FRDM-MCXN947 クイックスタートガイド | NXP |
| `FRDM-MCXN947/FAB_90818_C.pdf` | FRDM-MCXN947 基板図（FAB 90818 Rev C） | NXP |
| `MLX90640_Datasheet_Melexis.pdf` | MLX90640 サーマルセンサ データシート（Rev.11） | Melexis |
| `UM2884_VL53L5CX_ULD_Guide.pdf` | VL53L5CX ULD（Ultra Lite Driver）使用ガイド | ST UM2884 |

> VL53L5CX データシート本体（DS13754）は ST サイトの bot 除けにより自動取得できず未格納。
> 必要時に <https://www.st.com/resource/en/datasheet/vl53l5cx.pdf> から手動取得すること。

---

## FRDM-MCXN947 ジャンパ早見表（よく使うもの）

| ジャンパ | 役割 | デフォルト | 備考 |
| --- | --- | --- | --- |
| **J17** | MCU-Link USB Type-C コネクタ | — | ここにUSBを挿す（書き込み・デバッグ・VCOM） |
| **J18** | MCU-Link VCOM ポート | **オープン=有効** | ショートすると VCOM(シリアル) 無効化。**シリアルが出ないときは要確認** |
| **J19** | MCU-Link SWD 機能 | オープン=有効 | ショートで onboard SWD 無効（外部デバッグプローブ使用時） |
| **J21** | MCU-Link 強制 ISP モード | **オープン=通常起動** | **ショートで強制ISP(DFU)モード**。ファーム再書き込み/リカバリ時に使う |
| **J22** | MCU-Link SWD クロック | **ショート=有効（デフォルト）** | そのままでよい。触らない |
| **J24** | P3V3_MCU 電源 | 1-2 ショート=P3V3から供給 | デフォルトのまま |

### MCU-Link ファームリカバリ手順（USBから消えた / VCOM不調時）

1. USB を抜く
2. **J21 をショート**（J22 はデフォルトのショートのまま触らない）
3. USB を挿す → MCU-Link が **ISP(DFU)モード**で起動
4. `LinkServer` または MCU-LINK_installer でファームを再書き込み
5. 完了後 **J21 をオープンに戻して** USB 再接続（通常起動）

### シリアル(VCOM)が出ないときのチェック

- **J18 がオープン**であること（ショートだとVCOM無効）
- MCU-Link ファームが新しいこと（古いとVCOM不調の例あり）
- アプリ側で UART(FC4) ピン mux と FLEXCOMM4 クロックが設定されていること

---

## In-System Programming (ISP) / SW3

- **SW3**: ISPモードスイッチ。押すと P0_6/ISPMODE_N-DEBUG が Low。MCXN947 本体のISP用。
  （MCU-Link の J21 とは別物。MCU-Link のリカバリは J21 を使う）

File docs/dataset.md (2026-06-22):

# 学習データセット — 作成方法と `dataset/` 構成

TerraGuard AI のカラス検出モデル（2クラス: `not_crow` / `crow`）の**学習データの作り方**と、
`dataset/` ディレクトリの**中身・再現手順**をまとめる。

> **データの流れ（全体像）**
>
> ```text
> 実機(FRDM-MCXN947) ──シリアル──▶ collect_dataset.py ──▶ dataset/raw/*.npz
>                                       (ライブ収集・キーでラベル付け)   (1サンプル=1ファイル)
>                                                                          │
>                                              build_trainset.py ◀─────────┘
>                                                       │
>                                                       ▼
>                                            dataset/built/X.npy, y.npy, meta.json
>                                                       │
>                                              train_model.py（int8量子化）
>                                                       ▼
>                                       NPU変換 → モデルヘッダ → ファーム書き込み
> ```
>
> 学習〜NPUデプロイの後半（量子化・neutron変換・ヘッダ生成・書き込み）は [ml-model.md](./ml-model.md) を参照。
> 前処理ロジックの背景は [sensor-processing.md](./sensor-processing.md) を参照。

---

## 1. `dataset/` ディレクトリ構成

```text
dataset/
├── raw/          ★ 実機から収集した生サンプル（1サンプル = 1 .npz）。再現の元データ。
│   └── sample_000000.npz, sample_000001.npz, ...
├── built/        build_trainset.py が raw から生成する学習テンソル（派生物・再生成可能）。
│   ├── X.npy / y.npy            学習用 [N,24,24,4] / [N]
│   ├── X_all.npy / y_all.npy    （split前の全件。split_holdout.py 利用時）
│   ├── X_holdout.npy / y_holdout.npy  ホールドアウト評価用
│   └── meta.json               件数・チャンネル・正規化レンジ・ラベル内訳
└── validation/   前景検出ロジックの検証用 JSON（あり/なしの実測スナップショット）
    ├── 2026-06-22_crow_present.json
    └── 2026-06-22_crow_absent.json
```

| ディレクトリ | Git 追跡 | 理由 |
| --- | --- | --- |
| `dataset/raw/` | ✅ **追跡する** | 再現に必須の元データ。これさえあれば誰でも build→train→NPU変換まで再現できる。 |
| `dataset/validation/` | ✅ **追跡する** | 前景判定の回帰検証用。軽量（数十KB）。 |
| `dataset/built/` | ❌ **追跡しない**（`.gitignore`） | `raw/` から `build_trainset.py` で**完全再生成できる派生物**。容量も大きい。 |

> リポジトリには現在 **2535 サンプル**（`not_crow` 1507 / `crow` 1028, 合計 約10MB）の `raw/` を収録している。
> これがそのまま「学習に必要なデータ」であり、クローンすれば再学習を再現できる。

---

## 2. 生サンプル `.npz` のフォーマット（1サンプル）

`collect_dataset.py` は、サーマル1フレーム到着を基準に「直近の各系統」を1サンプルへ束ね、
**向き補正済みの生データ**として連番 `.npz` に保存する（入力テンソル化はせず、後段で前処理を自由に変えられるようにしている）。

| キー | 形状 / 型 | 内容 |
| --- | --- | --- |
| `thermal` | `[24,24]` float32 | サーマル(℃)。**ファーム側で90度右回転＋中央24行crop済み**。 |
| `thermal_fg` | `[24,24]` float32 | サーマル前景(℃, ≥0)。背景未確立なら全0。 |
| `distance` | `[8,8]` float32 | 距離(mm)。無効ゾーンは NaN。 |
| `distance_fg` | `[8,8]` float32 | 距離前景(mm closer, ≥0)。 |
| `det` | `[5]` int32 | ルールベース候補判定 `(cand,t_max_c,t_area,d_max,d_area)`。無ければ -1。 |
| `label` | scalar `<U` | `'crow'` または `'not_crow'`。 |
| `ts` | scalar float64 | 収集時刻（`time.time()`）。 |

> **向き補正はファームで確定**（サーマル=回転+crop、距離=左右反転）。収集側・ビューア側は無加工で受け取る。
> これにより「実機が見ている向き」と「学習データの向き」が常に一致する。

---

## 3. 学習データの収集方法（`collect_dataset.py`）

実機を対象に向けてシリアルログを流しながら、**キー打鍵でライブにラベルを付ける**方式。

<p align="center">
  収集の様子（カラスがいる/いないをフレームごとに収集）
  <br><em>「カラスがいるとき／いないとき」を多数フレーム収集してモデルを作る。右の4分割はホスト側ビューア。</em>
</p>

### 手順

```bash
# ⚠ NXP 開発作業のため、着手前に frdm-mcxn947-dev スキルを起動すること
tools/.venv/bin/python tools/ml/collect_dataset.py \
    --port /dev/cu.usbmodemXXXX --out dataset/raw
```

ターミナルでキーを押すと、その時点以降のサンプルに `current_label` が付与され続ける:

| キー | 動作 |
| --- | --- |
| `c` | 以降を **crow**（カラスがいる）としてラベル付け |
| `n` | 以降を **not_crow**（カラスがいない＝背景/人/その他）としてラベル付け |
| `s` | 以降を **skip**（曖昧な区間は保存しない） |
| `q` / Ctrl-C | 終了 |

- サーマルは約7fps なので、しばらく `c`/`n` を保持するだけで多数のサンプルが貯まる。
- 受信＞保存で遅延が積まないよう、常に**最新フレームのみ**を束ねて保存する。
- GUI から収集する場合は `tools/dual_viewer_web.py` の Start/Stop/Delete UI も使える。

### 収集のコツ（データ品質）

- **crow**: ダミーガラス／実物を、距離・角度・明るさを変えて。屋外は日射条件（背景温度）も振る。
- **not_crow**: 何もない背景に加え、**人の通過・揺れる物・日なたの壁/路面**など「誤検出しやすい状況」を厚く集める（背景データが弱いと実機で誤爆する）。
- **曖昧なフレームは `s` で捨てる**。中途半端なラベルは精度を下げる。

---

## 4. 学習テンソルへの変換（`build_trainset.py`）

`raw/*.npz` を読み、モデル入力 **[24,24,4] float32(0..1)** とラベル [N] にまとめて
`dataset/built/` へ `X.npy` / `y.npy` / `meta.json` を書き出す。

```bash
tools/.venv/bin/python tools/ml/build_trainset.py \
    --raw dataset/raw --out dataset/built
# → X=(N,24,24,4) y=(N,)  crow=... not_crow=...
```

### 4チャンネルの構成と正規化レンジ

| ch | 内容 | ソース | 形状合わせ | 正規化レンジ → 0..1 |
| --- | --- | --- | --- | --- |
| ch0 | `thermal_abs`（絶対温度） | `thermal` [24,24] | そのまま | `[15, 45]℃` |
| ch1 | `thermal_fg`（サーマル前景） | `thermal_fg` [24,24] | そのまま | `[0, 5]℃` |
| ch2 | `distance`（絶対距離） | `distance` [8,8] | **最近傍3倍 → [24,24]**（`np.kron`） | `[0, 4000]mm`（無効→遠方相当） |
| ch3 | `distance_fg`（距離前景） | `distance_fg` [8,8] | **最近傍3倍 → [24,24]** | `[0, 500]mm` |

- ラベル: `not_crow → 0` / `crow → 1`。`label` が未知のサンプルは skip される。
- int8 量子化は学習側（`train_model.py`）の representative_dataset で行うため、ここでは float32(0..1) で出す。

> **重要**: この前処理（回転/crop は済み、距離3倍、正規化レンジ、無効距離=遠方）は、
> **ファーム `npu_infer.c` と 1 対 1 で厳密一致**させている。一致しないと実機の判定が学習時とずれる。
> 詳細は [sensor-processing.md](./sensor-processing.md) の「学習側との一致」を参照。

### `meta.json`（生成物）

件数・入力形状・チャンネル名・ラベル内訳・正規化レンジを記録する。現状の内訳:

```json
{
  "num_samples": 2535,
  "input_shape": [24, 24, 4],
  "channels": ["thermal_abs", "thermal_fg", "distance", "distance_fg"],
  "label_to_id": {"not_crow": 0, "crow": 1},
  "counts": {"not_crow": 1507, "crow": 1028},
  "norm": {"T_VMIN": 15, "T_VMAX": 45, "T_FG_MAX": 5, "D_VMAX": 4000, "D_FG_MAX": 500}
}
```

---

## 5. クローンから再現する手順

リポジトリの `dataset/raw/` から、学習データを再生成して学習まで回す:

```bash
# 1) 生データ → 学習テンソル（built/ を再生成。built/ は gitignore なのでクローン直後に必要）
tools/.venv/bin/python tools/ml/build_trainset.py --raw dataset/raw --out dataset/built

# 2)（任意）ホールドアウト分割
tools/.venv/bin/python tools/ml/split_holdout.py

# 3) 学習 + int8量子化（arm64 必須）
arch -arm64 tools/ml/.venv/bin/python tools/ml/train_model.py

# 4) 以降の NPU変換・ヘッダ生成・書き込みは docs/ml-model.md
```

> 性能検証・誤検出の切り分けは `terra-guard-model-eval` スキル／[ml-model.md](./ml-model.md) を参照。

---

## 6. データを追加収集して再学習する流れ（まとめ）

1. `collect_dataset.py` で `dataset/raw/` に **不足ケース**（特に誤検出しやすい背景）を追加収集。
2. `build_trainset.py` で `dataset/built/` を作り直す。
3. `train_model.py` で再学習 → int8量子化。
4. NPU変換 → モデルヘッダ生成 → ファーム書き込み（[ml-model.md](./ml-model.md)）。
5. 実機ライブで誤検出を確認（`terra-guard-model-eval` スキル）。合格なら確定。

---

関連: [ml-model.md](./ml-model.md) ／ [sensor-processing.md](./sensor-processing.md) ／ [overview.md](./overview.md)

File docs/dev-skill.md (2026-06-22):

# FRDM-MCXN947 開発用スキル — 完全AI開発を支える仕組み

本作 TerraGuard AI は、**人間がコードを 1 行も書かず**、ビルド・書き込み（flash）・学習コマンドの実行まで
**すべて AI コーディングエージェント（Claude Code）がハンドリング**して開発しました。
それを成立させている中核が、リポジトリに同梱した **Claude Code スキル**です。

> 「スキル」とは、Claude Code（AIエージェント）に**特定作業の確定手順・確定パス・ハマりどころ**を
> 事前に教え込んでおく仕組みです。AI は作業の着手時にスキルを起動するだけで、
> 毎回ブレずに同じ手順で実機開発を進められます。

このドキュメントは、**他の参加者がそのまま学べる／再現できる**よう、スキルの中身と狙いを解説します。

---

## 1. なぜスキル化したのか

組み込み／エッジAI開発は、**環境依存の“地雷”**が多い分野です。

- ビルドツールやプローブの**絶対パス**（LinkServer のバージョン、venv の場所…）
- センサが ACK しない**クロック設定**、LED が光らない**GPIOクロックゲート**
- 起動直後に無音ハングする **SysTick の罠**、NPU が回らない**変換ツールのバージョン不一致**

これらは「一度ハマって解決した」ことを忘れると、AI でも人でも**毎回同じ穴に落ちます**。
そこで、解決済みの確定手順・確定パス・症状と対処を**スキルに集約**し、
**CLAUDE.md からは「作業前に必ずこのスキルを起動せよ」とだけ指示**する構成にしました。

```text
CLAUDE.md（プロジェクト憲法）
   └─「NXP 開発は着手前に必ず frdm-mcxn947-dev スキルを起動」とだけ宣言
        └─ frdm-mcxn947-dev スキル（手順・パス・地雷の実体）
              ├─ ビルド / 書き込み / シリアル確認
              ├─ I2C 配線 / クロック / GPIO・LED / SysTick
              └─ ML / NPU ワークフロー（学習〜変換〜デプロイ）
```

この分離により、**CLAUDE.md は短く保ちつつ、AI は深い手順をいつでも正確に引ける**ようになります。

---

## 2. 同梱している 2 つのスキル

| スキル | 役割 | 場所 |
| --- | --- | --- |
| **frdm-mcxn947-dev** | ビルド・書き込み・シリアル確認・センサ/NPU 開発・ML パイプライン | [`.claude/skills/frdm-mcxn947-dev/SKILL.md`](../.claude/skills/frdm-mcxn947-dev/SKILL.md) |
| **terra-guard-model-eval** | モデル性能検証・誤検出の切り分け・再学習の判定 | [`.claude/skills/terra-guard-model-eval/SKILL.md`](../.claude/skills/terra-guard-model-eval/SKILL.md) |

> リポジトリでは `.claude/skills/*/SKILL.md` のみを追跡しています（個人設定は除外）。
> クローンすれば、同じスキルを Claude Code で起動できます。

---

## 3. `frdm-mcxn947-dev` スキルに書いてあること

ファームと ML パイプラインに関わる操作（ビルド・flash・実機デバッグ・シリアルログ・NPU学習・データ収集）を
**すべてこのスキル経由**で行います。主な内容は以下です。

### 3-1. 確定パス（推測しない）

実機検証済みの絶対パスを列挙してあるため、AI が毎回探索せずに済みます。

- プロジェクトルート / ELF の出力先
- LinkServer の場所（バージョンは都度 `ls` で確認）
- pyserial 入り venv、シリアルポート（`/dev/cu.usbmodem*`）
- **デバッグUART ボーレート = 921600**（115200 ではない、という地雷も明記）

### 3-2. ビルド・書き込み・シリアル確認

```bash
# ビルド
cd src/FRDM-MCXN947/terra-guard-ai
cmake --preset debug      # 初回 or CMakeLists 変更時
cmake --build debug

# 書き込み（LinkServer）
/Applications/LinkServer_xx/LinkServer flash "MCXN947:FRDM-MCXN947" \
  load debug/terra-guard-ai_cm33_core0.elf
```

- `-Werror` 有効（未使用関数も即エラー）といった**ビルドの作法**まで記載。
- **flash 直後に VCOM が一時切断**される → `sleep 1` してポート再確認、という手順も明文化。
- シリアルは**テキスト行とバイナリフレームが混在**するため、`latin-1` decode ＋正規表現で抽出する読み方を指定。

### 3-3. ハマりどころ（実機で解決済み）

スキルの一番の価値はここです。**症状 → 原因 → 対処**をセットで蓄積しています。

| 症状 | 原因 | 対処 |
| --- | --- | --- |
| LED が光らない | GPIO クロックゲート未有効 | `CLOCK_EnableClock(kCLOCK_GpioX)` を呼ぶ |
| 起動直後にシリアル無音 | `SysTick_Handler` 未定義で weak default の無限ループに落ちる | ハンドラを定義する |
| センサが ACK しない | FRO12M では 1MHz SCL を作れない | FC2 のクロック源を FRO_HF_DIV に |
| センサ無反応（バスロック） | I2C バスロック | **USB 抜き差し**で回復（物理操作は人間に依頼してOK） |
| NPU 推論が回らない | converter とドライバの**バージョン不一致** | ドライバ 3.0.0 に合わせて変換 |

### 3-4. ML / NPU ワークフロー

カラス検出 2 クラス（入力 24×24×4）の**データ収集 → 学習 → int8量子化 → NPU変換 → ヘッダ生成 → 書き込み**を
1 本の手順として記載。前処理をファームと学習側で**厳密一致**させる鉄則も明記しています（詳細は [ml-model.md](./ml-model.md) / [dataset.md](./dataset.md)）。

---

## 4. `terra-guard-model-eval` スキル

学習したモデルが**実機で本当に使えるか**を判定するためのスキルです。

- ホールドアウト評価（混同行列 / FN / FP）は**過大評価**になりがち、という前提を共有。
- **実機ライブ背景で誤検出（confirmed crow ≈ 0）を確認**してはじめて合格、という判定基準。
- tflite（ホスト）と ファームNPU の**出力照合**で、誤検出の原因（学習 vs 変換 vs 前処理）を切り分け。
- 結果に応じた**再学習すべきかの判断**まで導く。

---

## 5. AI に任せきりにしないための約束ごと

スキルには、**人間（制作者）がやるべき物理操作**も明記しています。

- **USB ケーブルの抜き差し**（I2C バスロック回復、クリーンな起動ログ取得、文字化けの切り分け）
- はんだづけ等のハード作業

つまり、**ソフトのエンジニアリングは AI、物理は人間**という役割分担を、スキル自体が定義しています。
これにより「何を AI に任せ、何を人がやるか」が毎回ブレません。

---

## 6. 再現方法

1. リポジトリをクローンする（`.claude/skills/*/SKILL.md` が含まれています）。
2. Claude Code で開き、NXP 開発を始める前に **`frdm-mcxn947-dev` スキルを起動**する。
3. スキルに従って、AI がビルド・書き込み・シリアル確認・学習を CLI で実行する。
4. モデル検証時は **`terra-guard-model-eval` スキル**を起動する。

> パス類は環境に合わせて読み替えてください（スキル内に「都度 `ls` で確認」と書いてある箇所が手がかりです）。

---

関連: [firmware.md](./firmware.md) ／ [ml-model.md](./ml-model.md) ／ [dataset.md](./dataset.md) ／ [sensor-processing.md](./sensor-processing.md)

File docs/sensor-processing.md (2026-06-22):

# センサデータ処理 — カラス検出の仕組み（前処理・前景抽出・NPU推論）

> **今回のスコープ: カラスの検出のみ。** 「人によるゴミ出し」など他状態の分類は将来拡張。処理はすべて FRDM-MCXN947 単体（Cortex-M33 + eIQ Neutron NPU）で完結する。カメラを使わず、クラウドにも依存しない。

このドキュメントは、**実装コード（`src/FRDM-MCXN947/terra-guard-ai/app/`）の現状ロジックをそのまま落とし込んだもの**である。サーマル（MLX90640）と距離（VL53L5CX）の2センサを **背景差分で前景化** し、それを **4チャンネル 24×24 のテンソル** にまとめて **eIQ Neutron NPU の小型 CNN** に通し、**時間方向のデバウンス**を経てカラスを確定検出する。各処理が「なぜそうしているか（狙い）」も併記する。

関連ファイル:

| 役割 | ファイル |
| --- | --- |
| サーマル取得・回転crop・段差補正 | `app/thermal_mlx90640.c` |
| 距離取得・ホールド・左右反転 | `app/tof_vl53l5cx.c` |
| 背景差分・前景抽出・候補判定 | `app/bg_subtract.c` |
| NPU 入力整形・量子化・推論 | `app/npu_infer.c` |
| メインループ・デバウンス・LED | `led_blinky.c`（`main()`） |
| 学習側の前処理（ファームと厳密一致） | `tools/ml/build_trainset.py` |
| CNN 構造・int8量子化 | `tools/ml/train_model.py` |

---

## 0. 全体パイプライン（1フレームの流れ）

<p align="center">
  カラス検出パイプライン
</p>

```text
┌─ MLX90640 (サーマル, 生32×24) ──┐         ┌─ VL53L5CX (距離, 8×8 = 64ゾーン) ─┐
│  サブページ0/1 が揃ったら完成      │         │  高頻度ポーリング, status判定+ホールド │
│  ① 段差補正(dechess)             │         │  ② 左右反転(flip_h) + 無効=-1        │
│  ② 90度右回転＋中央24行crop       │         │                                    │
│     → 24×24=576画素[℃]           │         │     → 8×8=64ゾーン[mm]               │
└──────────────┬──────────────┘         └─────────────┬──────────────┘
               │                                        │
        ③ 背景差分(EMA背景)                       ③ 背景差分(中央値背景)
        thermal_fg = max(0, cur-bg)[℃]          dist_fg = max(0, bg-cur)[mm]
        （背景より「暖かい」正の差）              （背景より「手前」に出た正の差）
               │                                        │
               ▼                                        ▼
        ┌────────────────── ④ NPU 入力整形 (24×24×4 int8) ──────────────────┐
        │  ch0 thermal_abs : サーマル絶対温度   24×24 をそのまま              │
        │  ch1 thermal_fg  : サーマル前景       24×24 をそのまま              │
        │  ch2 distance    : 距離(8×8)          最近傍3倍 → 24×24             │
        │  ch3 distance_fg : 距離前景(8×8)      最近傍3倍 → 24×24             │
        └───────────────────────────┬──────────────────────────────┘
                                     │
                            ⑤ eIQ Neutron NPU 推論
                            小型CNN → Softmax [not_crow, crow]
                                     │
                            ⑥ 時間デバウンス（10連続でcrow確定）
                                     │
                            ⑦ ステータスLED 点灯 / INFER 行をシリアル出力
```

完成サーマルフレームは実測 **約7fps**。NPU 推論は**サーマル完成フレームごと**（＝約7回/秒）に1回駆動する。距離は約10Hz でポーリングするが、推論は常に「最新の距離前景」と「いま揃ったサーマル前景」を組み合わせて行う。

**狙い**: 単一センサでは誤検出が避けられない。サーマル単独だと日なたの壁・路面が熱源として誤反応し、距離単独だと人・車・物の通過に反応する。**サーマル（温度）と距離（奥行き）を4chに束ねて1つの CNN に同時入力**することで、「暖かくて・かつ・背景より手前に出た・小さなまとまり」というカラス特有の同時条件を学習で取り出す。これがプライバシー配慮（カメラ非使用）と低消費電力（オンデバイス）を両立する核心。

---

## 1. サーマル前処理（MLX90640 → 24×24）

> **処理解像度は一貫して 24×24。** MLX90640 の**生**出力は 32×24=768点だが、**取得直後に 24×24=576点へ整形**し、以降の全処理（背景差分・前景・統計・バイナリ送出・NPU入力・データ収集）は 24×24 で行う。「32×24」と書けるのはセンサ生仕様の説明のときだけ。

実装: `app/thermal_mlx90640.c`

### 1-1. 完成フレームの組み立て（Chessモード）

MLX90640 は Chess パターンで **サブページ0/1 を市松状に交互測定**する。リフレッシュ16Hz設定（サブページ単位）で、**完成フレーム（0/1両方が揃った状態）は約半分の ~7fps**。`poll_frame()` は data-ready を非ブロッキングで確認し、サブページ0と1の両方が揃った瞬間だけ「完成」とみなす（`s_subpageSeen == 0x03`）。

- **狙い**: 片サブページだけで描画すると動体時に市松模様（片半分が古い）が出る。両サブページ完成を待つことで動きのある対象でも崩れない。

### 1-2. サブページ段差補正（dechess）

Chess モードはサブページ0/1間に **系統的なオフセット差（実機で約1〜1.6℃）** がある。生フレーム（行24×列32）に対し、各サブページの**中央値** m0/m1 を求め、全体平均に揃うよう subpage0 に `-(m0-m1)/2`、subpage1 に `+(m0-m1)/2` を加える。

- **狙い**: 背景差分の前景は `max(0, cur-bg)` の正側だけを取るため、サブページ段差を放置すると**生サーマルは市松でないのに前景だけ市松模様**になる（片サブページだけが一様に閾値を超える）。段差補正で根本除去する。中央値ベースなので画面内に本物の熱源があっても段差推定が引っ張られにくい。

### 1-3. 90度右回転＋中央24行crop（`rotate_crop`）

センサを物理的に90度回転して取り付けているため、生フレーム（行R=24×列C=32）を**時計回り90度回転**し、回転後の32行のうち**上下を落として中央24行をcrop**、正方の **24×24=576画素** にする。

```text
dst[oi*24 + j] = src[(R-1-j)*C + (oi+4)]   （R=24, C=32, 上4行カット）
```

- **狙い**: 正立かつ正方の画像にすることで、距離(8×8→24×24)と画素位置の対応が素直になり、CNN が空間特徴を学習しやすい。回転・cropは**ファームで確定**し、学習側（`build_trainset.py` の `shape_thermal()`＝無加工）と厳密一致させている。

---

## 2. 距離前処理（VL53L5CX → 8×8）

実装: `app/tof_vl53l5cx.c`。解像度 8×8（64ゾーン）、10Hz、積分時間33ms、シャープナー20%。**回転はしないが左右反転**する。

### 2-1. 信頼度フィルタとホールド

各ゾーンの `target_status` を見て **有効測距（status ∈ {5,6,9,10}）かつ 0〜4000mm** のときだけ距離を更新する。低信頼ゾーンは瞬間的にゴミ距離（例: 2000→300mm）を返すので、そのフレームは捨て、ゾーンごとに保持した**最後の有効値でホールド**する。無効が `VL53_HOLD_MAX`（10フレーム≒1秒）連続したら、古い値を引きずらないよう **無効(-1)** に倒す。

- **狙い**: 背景差分は背景との差を見るので、ゾーンが瞬間的にゴミ値を返すと前景が誤爆する。ホールドでフレーム間のちらつきを抑え、ホールド切れの -1 で「対象なし」を明示する。

### 2-2. 左右反転（`vl53_flip_h`）

取り付け向き補正として 8×8 を左右反転（`row*8 + (7-col)`）し、サーマルと画素の左右を揃える。`s_distHeld`（DIST出力・NPU入力・背景差分が見る側）を反転後の向きで保持する。

---

## 3. 背景差分による前景抽出（カラス検出の心臓部）

実装: `app/bg_subtract.c`。**「背景モデルを持ち、いま現れた差分（前景）だけを取り出す」**のがこの段の役割。サーマルと距離で背景の作り方・前景の向きが異なる。

### 3-1. 背景モデルの確立と更新

| | サーマル | 距離 |
| --- | --- | --- |
| 初期化 | 起動後 **40フレームの平均**（≒5〜6秒） | 起動後 **40フレームのゾーンごと中央値**（無効ゾーンは積まない） |
| 逐次更新 | EMA `α=0.01`（日射・気温変化に追従、少し速め） | EMA `α=0.005`（固定物中心なので遅め） |
| 更新タイミング | **そのセンサの前景が立っていない間だけ更新（立っている間は凍結）** | 同左 |

- **中央値で距離背景を作る狙い**: 起動中に瞬間ノイズが混ざっても、平均より中央値の方が外れ値に強い。
- **センサごとに独立して凍結する狙い（重要）**: 旧実装は「サーマル AND 距離」の候補成立時だけ背景を凍結していた。すると片方（例: サーマル）に前景が出ていても、もう片方の条件不成立で候補にならないと、前景が出ているサーマルの背景まで EMA 更新され続け、**途中で現れたカラスが数秒で背景に吸収されて前景が消える**バグが起きた。現在は **各センサが「自分の前景が立っている間は自分の背景を凍結」** する（`bg_apply_update_policy()`）。

### 3-2. サーマル前景

```text
thermal_fg[i] = max(0, cur[i] - bg[i])   （背景より「暖かい」正の差だけ）
```

前景画素とみなす下限は **+2.0℃**（`BG_THERMAL_FG_MIN_C`）。前景の最大差分 `t_max` と、+2.0℃以上の画素数 `t_area` を特徴量として保持する。

- **+2.0℃という閾値の狙い**: 1.0℃まで下げると前述のサブページ段差（約1〜1.6℃）を拾って市松が再発する。2.0℃ならサブページ差を超えるので安全。一方、カラスの**羽毛表面温度は約30〜35℃**（後述）で、近接・大きく写れば背景と2℃以上の差は出る前提。
- **正側（暖かい側）だけ取る狙い**: カラスは背景より暖かい熱源。冷たい側の差分（影など）は不要。

### 3-3. 距離前景（陸上カラス対応の複合判定）

```text
dist_fg[z] = max(0, bg[z] - cur[z])   （背景より「手前」に出た正の差だけ）
```

距離前景は**ヒステリシス付き**: ゾーンは ON閾値 **30mm** で点灯し、OFF閾値 **15mm** を下回るまで点灯を維持する。境界でのσ揺れによるちらつきを防ぐ。

ただし「ON=30mm の単一ゾーン絶対値」だけでは誤検出が止まらない。**地面に立つ陸上カラスは、背景=地面との距離差が体高ぶん 15〜20cm（最大80mm）しか出ず**、地面ノイズ床（σ p90 41mm / 変動幅 max 126mm）と重なって**単一閾値では分離不能**だからである。そこで **まとまり（連結塊）を見る複合判定** を導入した:

```text
距離側カラス候補あり ⇔
   ( 最大連結塊サイズ ≥ 2px  かつ  その塊内の前景合計 ≥ 100mm )   ← distCluster
 または
   ( 前景 上位3ゾーン和 ≥ 120mm )                                ← distTop3
```

連結塊は前景マップ `s_distFg` を 8×8 グリッドとみなし、点灯ゾーン(fg>0)の **4近傍連結成分を反復DFS** で走査して最大塊のサイズと合計を求める。

- **狙い**: カラスは隣接ゾーンが連結して反応し前景総和が大きい。地面ノイズは単発・散発なので連結も総和も伸びず弾かれる。「まとまった反応」だけを陸上カラス候補とする。（実機検証 2026-06-22 / `tools/ml/test_foreground_detect.py` で保存データの あり/なし 完全分離を確認）

### 3-4. ルールベースの候補判定（背景凍結とログ用）

```text
candidate = hasThermalFg AND hasDistFg
  hasThermalFg = (t_max ≥ 2.0℃) AND (t_area ≥ 4)
  hasDistFg    = distCluster OR distTop3
```

この `candidate` は **DET 行としてシリアル出力**され、また背景凍結ロジックの参考になる（実際の凍結はセンサ独立判定）。

- **狙い**: AND で絞ることで、熱だけ／距離だけの単独反応を弾く。**ただしこの AND 判定は最終的なカラス確定ではない**。最終判定は次段の NPU が行う。ルールベースは「背景に吸収させない（前景を保持する）」ための土台と、開発時の可視化のために残している。

---

## 4. NPU 入力テンソルの整形（24×24×4 int8）

実装: `app/npu_infer.c`（`npu_infer_run()`）。学習側 `build_trainset.py` と**前処理・正規化レンジ・量子化を厳密一致**させている（一致しないと NPU の判定が学習時とずれる）。

### 4-1. 4チャンネルの構成

| ch | 内容 | ソース | 形状合わせ | 正規化レンジ |
| --- | --- | --- | --- | --- |
| **ch0** | thermal_abs（絶対温度） | サーマル24×24[℃] | そのまま | `[15, 45]℃` → 0..1 |
| **ch1** | thermal_fg（サーマル前景） | サーマル前景24×24[℃,≥0] | そのまま | `[0, 5]℃` → 0..1 |
| **ch2** | distance（絶対距離） | 距離8×8[mm] | **最近傍3倍 → 24×24** | `[0, 4000]mm` → 0..1 |
| **ch3** | distance_fg（距離前景） | 距離前景8×8[mm,≥0] | **最近傍3倍 → 24×24** | `[0, 500]mm` → 0..1 |

- 距離の最近傍3倍は `np.kron`（学習側）／ファームでは `dr = y/3, dc = x/3` のインデックス展開で等価。
- 距離の**無効ゾーン(-1)は遠方相当（4000mm）**として扱う（学習側 `nan→D_VMAX` と一致）。

**狙い（なぜ絶対値と前景の両方を入れるか）**:
- **前景（ch1/ch3）** は「いま動いた・現れたもの」を表す（背景差分の出力）。カラスの存在そのものを示す主信号。
- **絶対値（ch0/ch2）** は「その対象が何℃で・何mmにあるか」という文脈を CNN に与える。例えば前景が出ていても、絶対温度が背景同然なら誤反応、35℃近辺で背景より手前なら本物、という判断を学習で獲得できる。前景だけでは温度・距離の絶対水準が失われるため両方入れる。

### 4-2. 量子化（float 0..1 → int8）

各チャンネルを 0..1 にクリップ後、入力テンソルの量子化に合わせて int8 化する:

```text
q = round(x / scale) + zero_point      scale = 1/255 (≈0.003921569),  zero_point = -128
```

学習時の representative_dataset による full-integer 量子化（`train_model.py`）の入力スケールと一致させた固定値で再現している。テンソルレイアウトは `[H=24][W=24][C=4]` の行優先（`in[(y*24 + x)*4 + c]`）。

---

## 5. eIQ Neutron NPU でのCNN推論

実装: モデル構造は `tools/ml/train_model.py`、推論呼び出しは `app/npu_infer.c` ＋ `tflm/`（TFLite Micro + Neutron グラフ）。

### 5-1. モデル構造（NPU対応opのみ）

```text
Input [24,24,4]
  Conv 8  3x3 relu → MaxPool2   → 12x12x8
  Conv 16 3x3 relu → MaxPool2   → 6x6x16
  Conv 24 3x3 relu → AvgPool(6,6) → Flatten   → 24
  Dense 2 softmax
Output [1,2]  = [p_not_crow, p_crow]
```

- GlobalAveragePooling は Neutron 変換(MLIR)で落ちるため、明示サイズの `AveragePooling2D(6,6)` + `Flatten` で代替している。
- 2クラス（`not_crow`=0 / `crow`=1）の Softmax 確率を出す。

### 5-2. 出力の逆量子化と判定

出力テンソル [1,2] は int8。逆量子化して確率に戻す:

```text
p0 = (outq[0] - zp) * scale   （not_crow）   scale = 1/256 (=0.00390625), zp = -128
p1 = (outq[1] - zp) * scale   （crow）

raw_crow   = (p1 ≥ p0)        … この1フレームの生判定
p_crow     = p1
confidence = max(p0, p1)
```

この `raw_crow` は**1フレーム単位の生判定**であり、まだ確定ではない。

- **狙い（NPUを使う理由）**: 背景差分のルールだけでは「前景が出た＝カラス」までしか言えず、人・揺れる物・日なたの誤反応を切り分けられない。CNN は4chの空間パターン（温度分布の形・距離のまとまり・両者の重なり方）からカラスらしさを学習で判別する。推論はオンチップの **eIQ Neutron NPU** で実行するため低消費電力・低レイテンシで、クラウドに画像を送らない（プライバシー配慮）。

---

## 6. 時間方向デバウンス（確定検出）

実装: `led_blinky.c` の `main()`。`CROW_CONFIRM_FRAMES = 10`。

```text
raw_crow が来るたび:
   crow なら  streak++（上限255）
   not_crow なら streak = 0
confirmed = (streak ≥ 10)        … 確定crow
```

サーマル完成フレームは約7fps なので、**10連続 ≒ 約1.4秒のあいだ連続して crow** と判定されたときだけ「確定crow」とする。解除は即時（not_crow が1回来たら streak=0 で確定を落とす）。

- **狙い**: 静止背景でも生判定 `raw_crow` は境界（p_crow≈0.5）で単発的に揺れることがある。10連続を要求することで**単発スパイクの誤点灯を抑える**。一方、解除を即時にするのは、カラスが去ったあとに点灯が残らないようにするため（追い払い動作の誤発火を避ける）。

---

## 7. 出力（シリアルフォーマット）

メインループは同一シリアル上に、行頭マーカ／magic でテキストとバイナリを混在出力する。ホスト側ビューア（`tools/dual_viewer_web.py`）が分離して可視化する。

| 出力 | 形式 | 内容 |
| --- | --- | --- |
| `0xAA55` + Ta + 576×int16 | バイナリ | 生サーマル（24×24, 1/100℃） |
| `0xAA56` + 576×int16 | バイナリ | サーマル前景（24×24, 1/100℃, ≥0） |
| `DIST,<z0..z63>` | テキスト | 距離8×8[mm]（-1=無効） |
| `STAT,<s0..s63>` | テキスト | 距離8×8 の target_status |
| `DFG,<z0..z63>` | テキスト | 距離前景8×8[mm] |
| `DET,<cand>,<t_max>,<t_area>,<d_max>,<d_area>,<d_cluster_size>,<d_cluster_sum>,<d_top3_sum>` | テキスト | ルールベース候補判定の要約（後半3つは距離複合判定の特徴量。後方互換で末尾追加） |
| `INFER,<確定crow 0/1>,<p_crow×1000>,<conf×1000>,<raw crow>,<streak>` | テキスト | NPU推論結果（確定はデバウンス後、raw/streak はデバッグ用） |

確定crow（`INFER` の先頭フィールド=1）の間だけ **ステータスLED(P1_22)** を点灯する（シンク駆動 Low=点灯）。

---

## 8. カラスのサーマル特性（しきい値設計の前提・重要）

サーマル前景閾値（`BG_THERMAL_FG_MIN_C`）を決めるうえで、**「カラスの体温」と「サーマルカメラで実際に見える表面温度」は別物**である点が重要。

| 対象 | 温度目安 | 備考 |
| --- | --- | --- |
| 深部体温 | 約 40〜42℃ | カラス本体の体温。羽毛に覆われ**直接は見えにくい** |
| 羽毛の表面 | 約 30〜35℃ | **MLX90640 で主に見えるのはここ** |
| 観測例 | 羽毛表面 約 34℃ | カラス研究で羽毛表面34℃、顔や胴体の方が高温と報告 |
| 日なたの黒い羽 | さらに高く見える可能性 | 黒い羽は日射で表面温度が上がりやすい |

- **検出ロジック上の目安**: サーマルで狙うべきは**羽毛表面 30〜35℃**（初期値34℃前後）。深部体温41℃を基準に閾値を組むと**実際の見え（34℃）と乖離して検出漏れ**するので避ける。
- **屋外運用の注意**: 日射で背景（地面・壁・ゴミ袋）が30℃台後半まで温まると羽毛表面34℃との差が縮み、前景に出にくくなる。`BG_THERMAL_FG_MIN_C`（現状 2.0℃）はこの状況を見越して調整する余地がある。

---

## 9. 学習側との一致（再学習時の鉄則）

NPU の判定が学習時と一致するには、**ファームの前処理と学習側の前処理を1対1で揃える**必要がある。以下は必ず一致させる:

| 項目 | ファーム | 学習側 |
| --- | --- | --- |
| サーマル整形 | `rotate_crop`（回転＋crop）済み 24×24 を無加工 | `shape_thermal()`＝無加工 |
| 距離拡大 | 最近傍3倍（`y/3, x/3`） | `np.kron`（3倍） |
| 正規化レンジ | T `[15,45]` / Tfg `[0,5]` / D `[0,4000]` / Dfg `[0,500]` | 同左（`build_trainset.py`） |
| 無効距離の扱い | -1 → 4000mm（遠方相当） | `nan → D_VMAX` |
| 入力量子化 | scale=1/255, zp=-128 | representative_dataset による full-integer 量子化 |

再学習〜NPUデプロイの手順は [ml-model.md](./ml-model.md) を参照。性能検証・誤検出の切り分けは `terra-guard-model-eval` スキル参照。

---

関連: [overview.md](./overview.md) / [hardware.md](./hardware.md) / [firmware.md](./firmware.md) / [ml-model.md](./ml-model.md)

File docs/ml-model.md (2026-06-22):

# 学習モデルの作り方とNPUデプロイ（FRDM-MCXN947 / eIQ Neutron NPU）

FRDM-MCXN947 の **eIQ Neutron NPU** で動く学習モデルを、**Mac 上で作って書き込む**までの調査結果と方針をまとめる。

> **今回のスコープ（確定・✅ 2026-06-22 実機検証済み）: カラス検出 2クラス（not_crow / crow）を NPU で動かす。**
> 入力は **24×24×4**（thermal_abs / thermal_fg / distance / distance_fg）、出力 [1,2] Softmax。
> 当初の3クラス（なし/カラス/人）や 32×32 入力は旧設計。現行は本ファイル §3.5 以降が正。
> カラス時の 8×8 ヒートマップ出力は後段（[後述の発展](#5-発展カラス時の-88-ヒートマップ)）。
>
> **⚠️ 解像度に関する重要事項**: MLX90640 の**生**出力は 32×24 だが、ファームは**取得直後に
> `rotate_crop()`（90度右回転＋中央24行crop）で 24×24 に整える**。背景差分・前景・統計・
> バイナリ送出・**NPU入力・データ収集まで、処理パイプラインはすべて 24×24** で統一されている。
> 距離 8×8 は最近傍3倍 kron で 24×24 に拡大して束ねる。よって本文中に残る「32×24」「[1,24,32,C]」
> は §1〜§3.4 の**旧調査記録**であり、確定実装ではない（§3.5 が正）。

---

## 0. 結論（先に要点）

> ⚠️ **§1〜§3.4 と §5〜§6 の前半は設計初期（3クラス none/crow/human・32×32 入力）の
> 調査記録**。実装の確定仕様は **§3.5（2クラス not_crow/crow・24×24×4・実機検証済み）**
> および §3.6（距離前景の複合判定）を参照すること。本文中の「3クラス」「32×32」
> 「[1,24,32,1]」は旧記述。

- **NPU は `int8` 量子化済みの TensorFlow Lite モデルしか加速しない。** float32 や uint8 主体のモデルは CPU フォールバックになる。
- 公式の道は2通り。本プロジェクトは **(B) を主軸**にする。
  - **(A) eIQ Portal GUI**: ノーコードで学習〜量子化〜変換。ただし**画像分類デモ前提**で、カメラ画像(128×128×3)向け。我々の「サーマル+距離の多チャネル小画像」「マルチタスク」には窓が狭い。**eIQ Portal は Windows/Linux 配布で macOS 非対応**。
  - **(B) Keras/TF で自作 → INT8量子化 → `neutron-converter` で NPU 変換**: モデル形状・入力チャネル・出力ヘッドを自由に設計でき、Mac の Python で学習まで完結。**変換ツール `neutron-converter` だけ Linux x86 実行**が必要（本機 Mac は x86_64 なので Docker で動く見込み。[6章](#6-neutron-converter-を-mac-で動かす)）。
- **C言語側の組み込みは SDK サンプル `tflm_cifar10`（FRDM-MCXN947 NPU版 = `pcq_npu`）がそのまま雛形になる。** モデルを差し替えるだけ。32×32×3 の CNN 分類が **約1ms/推論**で動く実績がサンプル readme に記載。
- NPU の対応オペレータ表（int8）に、tiny CNN に必要な op（Conv2D / DepthwiseConv2D / FullyConnected / Pooling / Softmax / Add / Relu 等）は**すべて揃っている**（[4章](#4-npu-対応オペレータint8)）。

---

## 1. 参照ソース（ローカルに取得済み）

調査の一次情報。online doc を読むより手元のこれらが速くて正確。

| 場所 | 内容 |
| --- | --- |
| `docs/nxp/MCXN947：顧客MLモデルをトレーニングし、NPUに展開する方法.pdf` / `.md` | NXP公式記事（[原文](https://community.nxp.com/t5/MCX-Microcontrollers-Knowledge/MCXN947-How-to-Train-and-Deploy-Customer-ML-model-to-NPU/ta-p/1899497)）。eIQ Portal GUI での学習〜変換〜CIFAR10サンプル展開の手順 |
| `~/src/github.com/nxp-mcuxpresso/mcuxsdk-middleware-eiq` | **eIQ Middleware repo**（[GitHub](https://github.com/nxp-mcuxpresso/mcuxsdk-middleware-eiq)）。Neutron NPU の**オンデバイス側**＝`neutron/driver/include/NeutronDriver.h`（NPU実行API）と `libNeutronDriver.a` / `libNeutronFirmware.a`。SDK 25.06 / Neutron Software 3.0.0。<br>※この repo の `docs/index.rst` は online doc `.../eiq/tensorflow-lite/docs/ugindex.html` の**生成元**。ただし手元 clone は部分的で `tensorflow-lite/` サブツリーは含まれない（west で別取得） |
| `~/mcuxpresso/mcuxsdk/mcuxsdk/middleware/eiq/tensorflow-lite/docs/` | **TFLite-Micro 公式UGの実体**（= 上記 online doc と同一内容）。`topics/convert_model.md`（変換手順）、`topics/supported_operators.md`（**対応op表**）など |
| `~/mcuxpresso/mcuxsdk/mcuxsdk/examples/eiq_examples/tflm_cifar10/` | **C側の雛形となる SDK サンプル**。`readme.md` に「自分のモデルへの差し替え手順」「neutron-converter コマンド」「TensorArena サイズ調整」まで全部書いてある |
| `~/mcuxpresso/mcuxsdk/mcuxsdk/examples/_boards/frdmmcxn947/eiq_examples/tflm_cifar10/pcq_npu/` | **FRDM-MCXN947 専用の NPU 版モデル一式**（`cifarnet_quant_int8_npu.tflite` / `model_data.h` / `model_cifarnet_ops_npu.cpp`）。これを我々のモデルで置き換える |

他にも `examples/_boards/frdmmcxn947/eiq_examples/` に `tflm_label_image` / `tflm_kws`（キーワード検出）/ `tflm_modelrunner` / `mpp` がある。

---

## 2. 全体フロー（Mac 中心・(B) 方式）

```
[1] データ収集            実機(FRDM)からUART経由でサーマル/距離フレームを記録（tools/ のビューア基盤を流用）
        │                  ラベル付け：なし / カラス / 人
        ▼
[2] 学習 (Mac, Python)     Keras/TF で tiny CNN を学習（float32）。NHWC [batch,H,W,C]
        │
        ▼
[3] INT8量子化 (Mac)       TFLiteConverter + 代表データセットで full-integer量子化 → quant_int8.tflite
        │                  入出力も int8（NPU要件）
        ▼
[4] NPU変換 (Linux/Docker) neutron-converter --target mcxn94x --dump-header-file-output
        │                  → *_npu.tflite と model_data.h（C配列）+ op登録スニペットを生成
        ▼
[5] 組み込み (Mac, CLI)    tflm_cifar10 を雛形に model_data.h と op resolver を差し替え、
        │                  kTensorArenaSize を調整
        ▼
[6] ビルド・書き込み       ファームをビルドして書き込み（frdm-mcxn947-dev スキル）
        │
        ▼
[7] 実機推論              入力テンソルにセンサフレームを詰めて MODEL_RunInference()
```

ステップ [1][2][3][5][6][7] は **Mac でそのまま**できる。**[4] だけ Linux x86 バイナリ**（[6章](#6-neutron-converter-を-mac-で動かす)）。

---

## 3. モデル設計（分類：なし / カラス / 人）

### 3.1 入力テンソルの作り方

> ⚠️ **本節は旧調査記録（基準グリッドを 32×24 としていた頃）。確定実装は §3.5：基準グリッドは
> 24×24（センサ生 32×24 を取得直後に `rotate_crop` で 24×24 化したもの）、入力は `[1,24,24,4]`。**

センサは解像度が違う（サーマル 32×24、距離 8×8）。**サーマルの 32×24 を基準グリッド**にして、距離を最近傍 or バイリニアで 32×24 に拡大し、**マルチチャネル画像**として 1 本のテンソルに束ねるのがNPUに優しい（Conv2Dが1枝で済む）。

推奨入力（NHWC, `int8`）: **`[1, 24, 32, C]`**（H=24, W=32）

候補チャネル（既存の背景差分実装 [bg_subtract](../src/FRDM-MCXN947/terra-guard-ai/app/bg_subtract.h) を活かす）:

| ch | 内容 | 出所 |
| --- | --- | --- |
| 0 | サーマル生フレーム（℃を正規化） | MLX90640 |
| 1 | サーマル前景（背景差分。暖かい物体） | `bg_thermal_fg()` |
| 2 | 距離前景を24×32へ拡大（手前に出た量） | `bg_dist_fg()` を upsample |

- まずは **ch=1本（サーマル前景だけ）** で最小モデルを動かし、精度が足りなければ ch を足す、が安全な進め方。
- **正規化はC側で固定スケールに揃える**（学習時と同じ式で int8 に量子化）。サーマルは「背景比の差分℃」を 0〜数℃ → 0〜127 にクリップする等、レンジを固定すると安定。

> なぜ画像化するか: NPU が速いのは Conv 系。768+64 を素のベクトルで FullyConnected に入れるより、空間構造（カラス＝小さな塊／人＝大きな塊）を Conv で捉えた方が小さいモデルで効く。

### 3.2 アーキテクチャ候補

いずれも **INT8量子化前提・NPU対応opのみ**で構成（[4章](#4-npu-対応オペレータint8)の表で全てYes）。

**候補A（最小・まず動かす用）— Tiny CNN**
```
Input [24,32,C] int8
→ Conv2D 8ch 3x3 + ReLU → MaxPool 2x2     # 12x16x8
→ Conv2D 16ch 3x3 + ReLU → MaxPool 2x2    # 6x8x16
→ GlobalAveragePool (= AvgPool)           # 1x1x16
→ FullyConnected 3 → Softmax
```
- パラメータ数 ~数千、MACs ~数十万。`cifarnet`(91KB) よりはるかに軽い。推論 < 1ms 見込み。

**候補B（精度寄り）— DepthwiseSeparable**
```
Conv2D(8) → [DW3x3 + PW1x1]×2 を挟む → AvgPool → FC(3) → Softmax
```
- MobileNet 風。DepthwiseConv2D も int8 でNPU対応。パラメータ効率が良い。

**候補C（時系列）— Nフレームスタック**
- 動き（カラスは速い／人はゆっくり大きい）を使うため、直近 N=3 フレームを**チャネル方向に積む**だけ（`[24,32,C×N]`）。アーキは候補A/Bのまま。3D Conv は不要（NPU非対応）。

> 進め方の推奨: **候補A・1チャネル・単フレームから**。動いたらチャネル/フレームを足す。

### 3.3 出力

- 3クラス（none / crow / human）の Softmax。`tflm_cifar10` の `get_top_n` / `output_postproc` 流用で「最尤クラス＋信頼度」を取り出せる。

### 3.4 データ収集とラベル

- **実機ロギング**: 既存の UART ビューア基盤（`tools/dual_viewer.py` 等、サーマル=バイナリ `0xAA55`/前景=`0xAA56`、距離=テキスト `DIST,`）でフレームを保存 → クラス別フォルダに振り分け（eIQ_Toolkit のデータセット構造と同じ流儀）。
- **カラスが集めにくい問題**: 初期は「暖かい小物体を動かす」ダミー（[roadmap.md](./roadmap.md) のダミーカラス実験）で代用しつつ、人は自分で歩いて収集。
- **データ拡張（サーマル向け）**: 左右反転 / 小さな平行移動 / 温度ジッタ（全体 ±数℃）/ 背景差分後ならゲイン微調整。小モデルなので数百〜数千フレーム/クラスで一旦回せる。
- **「なし(none)」が大半になる不均衡**に注意。none をサブサンプリング、または crow/human を拡張で増やす。

### 3.5 データ収集〜実機推論パイプライン（実装・✅ 2026-06-22 実機検証済み）

カラス検出 **2 クラス（not_crow / crow）**。入力は **24×24×4**
（ch0 thermal_abs / ch1 thermal_fg / ch2 distance(8×8を3倍kronで24×24) / ch3 distance_fg）。
収集〜学習〜NPU変換〜実機推論までを実機で疎通確認済み（学習 val_acc 97.6% /
int8 [1,24,24,4]→[1,2] / 3.0.0 NPU変換 12/14 op converted / NPU推論ループ実機稼働）。

**形状の確定（旧 32×32 / pad は廃止）**: サーマルはファーム `thermal_mlx90640.c`
`rotate_crop()` で「90度右回転＋中央24行crop」済みの 24×24 を送る。NPU入力もそのまま
24×24（pad なし）。距離 8×8 は最近傍3倍 kron で 24×24。これらは
ファーム `npu_infer.c` と学習 `build_trainset.py` で**厳密一致**（量子化 scale=1/255・
zp=-128 も一致）。

> 🛠️ **実行コマンドは `frdm-mcxn947-dev` スキルに一本化**してある。再学習・収集・変換・
> ビルド・書き込みを行うときは、まず `frdm-mcxn947-dev` スキルを起動し、その「ML / NPU
> ワークフロー」節の手順に従うこと（このドキュメントには各ステップの**意味**だけを記す）。

ツール（すべて `tools/ml/`、依存は `tools/.venv`／学習のみ `tools/ml/.venv` で arm64）と
各ステップの役割:

1. **収集** — `collect_dataset.py`（CLI・キー打鍵ラベリング c=crow/n=not_crow）または
   `dual_viewer_web.py` の **Start/Stop/Delete UI**。サーマル1フレーム到着を基準に
   「サーマル24×24 / サーマル前景 / 距離8×8 / 距離前景 / DET」を 1 サンプル=1 `.npz` に
   束ねて `dataset/raw/` へ連番保存（向きはファームで確定済みなので無加工で保存）。
   **not_crow には人/腕だけでなく『人もカラスもいない純背景（前景ほぼゼロ）』も十分含める**
   こと（純背景が乏しいと静止シーンが crow に倒れる。2026-06-22 実機で確認）。

2. **`build_trainset.py`** — `.npz` 群 → 学習テンソル `[N,24,24,4] float32(0..1)` + ラベル。
   サーマル無加工、距離は最近傍3倍 kron。正規化レンジはここで一元管理。

3. **`train_model.py`** — 2 クラス CNN を学習し int8 TFLite を出力（⚠️ **arch -arm64 必須**。
   入力 int8 [1,24,24,4] / 出力 int8 [1,2]）。

4. **NPU変換** — `neutron_convert.sh` で mcxn94x 向けに変換（⚠️ **3.0.0 を明示**。
   デフォルトは 3.1.3 を指すので注意。ファーム内蔵ドライバ 3.0.0 と一致させる）。

5. **モデルヘッダ生成＋差し替え** — `make_model_data_h.py` で `model_data.h` を生成し
   `src/FRDM-MCXN947/terra-guard-ai/tflm/pcq_npu/model_data.h` に差し替え。
   op resolver（`model_cifarnet_ops_npu.cpp`）は **Softmax + Slice + NEUTRON_GRAPH の
   3op 固定**で、再変換しても一致するため通常は変更不要。

6. **ビルド・書き込み** — スキルのビルド／書き込み手順に従う（[firmware.md](./firmware.md)）。

> `dataset/` は `.gitignore` 対象（実機から再収集前提・大容量）。
> 距離前景の閾値・複合判定の実測検証データは `dataset/validation/` に保存
> （[§3.6](#36-距離前景の複合判定陸上カラス対応)）。

### 3.6 距離前景の複合判定（陸上カラス対応・✅ 2026-06-22）

地面に立つカラスは背景=地面との距離差が体高ぶん **15〜20cm（最大80mm）**しか出ず、
地面ノイズ床（σ p90 41mm / 変動幅 max 126mm）と重なるため、**距離前景の単一閾値
では分離不能**（旧 ON=300mm は陸上カラスに届かず、下げると地面ノイズで誤検出）。

`bg_subtract.c` は距離前景 ON を **30mm** に下げたうえで、「まとまり」で誤検出を抑える
**複合判定**を導入した:
- **連結塊**: 前景点灯ゾーンが 4近傍で ≥2px 連結し、その塊内 fg 合計 ≥100mm
- **または 前景 上位3ゾーン和 ≥120mm**

カラスは隣接ゾーンが連結して反応し総和が大きい一方、地面ノイズは単発・散発で
連結も総和も伸びないため分離できる。保存データでの検証は
`tools/ml/test_foreground_detect.py`（あり/なし 完全分離を確認）、実測データは
`dataset/validation/2026-06-22_crow_{present,absent}.json`。`DET` 行は後方互換で
末尾に `d_cluster_size,d_cluster_sum,d_top3_sum` を追加出力する。

> この複合特徴量は、NPU が 4ch テンソルの空間パターンから学ぶべきものの明示版でもある。
> 背景差分（前段フィルタ）と NPU（最終分類）の二段構えで陸上カラスを捉える。

---

## 4. NPU 対応オペレータ（int8）

`topics/supported_operators.md`「MCXN947 (eIQ Neutron NPU)」列より。**tiny CNN に必要な op は全部 int8 で Yes**。

| op | int8 NPU | 備考 |
| --- | --- | --- |
| CONV_2D | ✅ | 主力 |
| DEPTHWISE_CONV_2D | ✅ | MobileNet系に必須 |
| FULLY_CONNECTED | ✅ | 分類ヘッド |
| AVERAGE_POOL_2D / MAX_POOL_2D | ✅ | プーリング |
| RELU / RELU6 / LEAKY_RELU | ✅ | 活性化 |
| SOFTMAX / LOGISTIC / TANH | ✅ | 出力・活性化 |
| ADD / SUB / MUL | ✅ | 残差・スケール |
| CONCAT / PAD / TRANSPOSE | ✅ | 接続・整形 |
| RESIZE_NEAREST_NEIGHBOR | ✅ | （距離8×8の拡大をモデル内でやる場合） |
| TRANSPOSE_CONV | ✅ | （ヒートマップのupsampleに使える＝発展で有用） |

- 表に**無い op / int8列がNoの op は CPU フォールバック**（CMSIS-NN or リファレンス実装）。動くが遅く、TensorArena が増える。設計時は上表の op だけで組む。
- **量子化は per-channel int8（PCQ）が前提**（サンプルのフォルダ名 `pcq_npu` = per-channel-quant NPU）。Keras→TFLite の full-integer 量子化が標準でこれ。

---

## 5. C側の組み込み（`tflm_cifar10` 雛形）

差し替えは公式 readme どおり **2ステップ**。

1. **`model_data.h` を差し替え**: neutron-converter が吐く `model_data[]` / `model_data_len` に置換。`kTensorArenaSize` を converter 出力の "Total data" の **約105%** に設定（小さすぎると `AllocateTensors() failed`）。
2. **op resolver を差し替え**: converter が吐く `.h` 内の op 登録スニペット（例 `AddReshape/AddSlice/AddSoftmax/AddDequantize/AddCustom(NEUTRON_GRAPH)`）を `model_cifarnet_ops_npu.cpp` の `MODEL_GetOpsResolver()` に反映。**カスタムop `NEUTRON_GRAPH` の登録が NPU 実行の肝**。

推論API（`examples/eiq_examples/common/tflm/model.cpp` と `main.cpp`）:
```c
MODEL_Init();                                   // インタプリタ生成・AllocateTensors
in  = MODEL_GetInputTensorData(&inDims,&inType);// [batch,H,W,C], int8
out = MODEL_GetOutputTensorData(&outDims,&outType);
// ... in に正規化済みセンサフレームを int8 で詰める ...
MODEL_RunInference();                            // 内部で NeutronDriver が NPU 実行
MODEL_ProcessOutput(out,&outDims,outType,dt);    // argmax + 信頼度
```
- オンデバイス NPU 実行の低レベルAPIは `NeutronDriver.h`（`neutronInit / neutronModelPrepare / neutronRunBlocking`）。通常は TFLite-Micro のカスタムop経由で間接的に呼ばれるので直接触らない。
- Neutron-Software のバージョン更新は `NeutronDriver.h` / `NeutronErrors.h` / `libNeutronDriver.a` / `libNeutronFirmware.a` の4点を差し替えるだけ（readme記載）。

> **本プロジェクトへの統合方針**: まず `tflm_cifar10`(frdmmcxn947) 単体を west でビルド→書き込みし、**NPU で推論が回ること自体を疎通確認**（[firmware.md](./firmware.md) の west 手順と同じ流儀）。その後、推論コードを `terra-guard-ai` 本体へ移植し、入力をセンサフレームに差し替える。

---

## 6. Mac での環境構築と neutron-converter 実行（✅ 実機検証済み 2026-06）

Keras学習(Mac arm64) → int8量子化(Mac) → neutron-converter(Docker) → C ヘッダ生成、までを
**実際に通して確認済み**。手順とハマりどころを残す。

### 6.1 学習用 Python 環境（TF）— ⚠️ arm64 ネイティブ必須

このマシンは **Apple Silicon(M2 Max) だが、シェル環境が x86_64(Rosetta)** という構成。
TensorFlow の macOS wheel まわりで次の落とし穴がある（全部実機で踏んだ）。

- ❌ **x86_64/Rosetta の TF は import 時にクラッシュ**（`AVX instructions ... aren't available`, SIGABRT/exit134）。
  Rosetta は AVX を提供しないため、TF の x86_64 wheel は動かない。
- ❌ **pyenv で arm64 Python を自前ビルドも失敗しやすい**。x86 Homebrew(`/usr/local`)の
  `libintl`(gettext) を拾って `__locale_textdomain ... symbol(s) not found for architecture arm64`、
  `/usr/local` を排除すると今度は OpenSSL が無く `_ssl` 欠損になる。
- ✅ **解決: Apple 付属の `/usr/bin/python3`(universal2, _ssl同梱) を `arch -arm64` で起動して venv を作る。**

```bash
# venv 作成（arm64固定。Python3.9.6 / TF2.16.2 でOK）
arch -arm64 /usr/bin/python3 -m venv tools/ml/.venv
arch -arm64 tools/ml/.venv/bin/python -m pip install -r tools/ml/requirements.txt
# import 確認（machine: arm64 と出れば成功。x86だとここで落ちる）
arch -arm64 tools/ml/.venv/bin/python -c 'import tensorflow as tf,platform; print(platform.machine(), tf.__version__)'
```

> ⚠️ **以降、venv の python を叩くときは必ず `arch -arm64` を前置きする**（シェルが x86_64 のため）。

### 6.2 int8 TFLite の生成 — TF2.16 の変換クラッシュ回避

（以下は初期疎通検証 `make_test_model.py`(旧 [1,24,32,1]/3クラス) の記録。
本番の int8 量子化は `train_model.py` が同じ手筋で 24×24×4/2クラスを出力する。§3.5 参照。）
`tools/ml/make_test_model.py` が雛形（tiny CNN → full-int8量子化）。実装上の注意:

- ❌ `tf.lite.TFLiteConverter.from_keras_model(model)` は TF2.16(Keras3) で MLIR が落ちる
  （`ReadVariableOp: missing attribute 'value'` → `LLVM ERROR: Failed to infer result type`）。
- ✅ **`model.export(saved_dir)` で SavedModel 化 → `from_saved_model(saved_dir)` で変換**すると安定。
- full-int8 設定: `optimizations=[DEFAULT]` + `representative_dataset` +
  `supported_ops=[TFLITE_BUILTINS_INT8]` + `inference_input_type=int8` / `inference_output_type=int8`。

```bash
arch -arm64 tools/ml/.venv/bin/python tools/ml/make_test_model.py --out build/terra_guard_int8.tflite
# → 入力 int8 [1,24,32,1] / 出力 [1,3] の量子化tfliteが出る
```

### 6.3 neutron-converter（Docker amd64 エミュ）

- **`neutron-converter` は eIQ Neutron SDK 同梱の Linux **x86-64** ELF バイナリ**
  （本リポジトリでは `sdk/eiq-neutron-sdk-linux-3.1.3/bin/neutron-converter`、.gitignore済み・各自DL）。
  [eIQ Toolkit / Neutron SDK ダウンロード](https://www.nxp.com/design/design-center/software/eiq-ai-development-environment/eiq-toolkit-for-end-to-end-model-development-and-deployment:EIQ-TOOLKIT)。
- Mac の Docker は `linux/aarch64` で動くため、**`--platform linux/amd64`（QEMUエミュ）で実行**する。
  → `tools/ml/neutron_convert.sh` がこのラッパー（SDKをマウントして amd64 コンテナで実行）。✅ 動作確認済み。

`tools/ml/neutron_convert.sh`（内部で `docker run --platform linux/amd64 ... neutron-converter
--target mcxn94x --dump-header-file-output`）で変換する。**実行コマンドは `frdm-mcxn947-dev`
スキルの「ML / NPU ワークフロー」節を参照**（3.0.0 を `NEUTRON_SDK_DIR` で明示する点が重要）。

- **target デフォルトは `mcxn94x`**（= FRDM-MCXN947。MCXN947 は Neutron-C ターゲット）。
  `neutron-converter --show-targets` で一覧確認可。RT700専用の `--use-sequencer` /
  `--fetch-constants-to-sram` は MCXN947 では不要。
- 出力: NPU版 `*_mcxn94x.tflite` と、C配列 `*_mcxn94x.h`（`model_data[]` / `model_data_len`
  + op登録スニペット `AddSoftmax()` / `AddCustom(NEUTRON_GRAPH)`）。
- 検証時の実例（tiny CNN, 1,299 params）: **オペレータ変換率 9/10 = 0.9**（1 NeutronGraphに集約、
  残りSoftmaxはCPU）、Total data 8,464B / weights 2,272B。`kTensorArenaSize` は Total data ×1.05 が目安。

### 6.4 SDK バージョン互換の注意

- 検証に使ったのは **eIQ Neutron SDK 3.1.3**（converter出力に `Neutron Converter Version: 3.1.3`）。
  一方、ファーム側 eIQ Middleware は **SDK 25.06 / Neutron Software 3.0.0**。
  **converter と オンデバイス NeutronFirmware/Driver のバージョン整合**は要確認
  （ズレると実機で動かない可能性。記事も「converterバージョンをSDKと互換確認」と明記）。
  実機書き込み時に不整合が出たら、`eiq/neutron/` の4ファイル
  （`NeutronDriver.h`/`NeutronErrors.h`/`libNeutronDriver.a`/`libNeutronFirmware.a`）を
  converter と同世代に合わせて差し替える。
- 代替: eIQ Portal が使える Windows/Linux 環境があれば (A) GUI 変換も可
  （ただし多チャネル入力・マルチタスクは GUI では難しい）。

---

## 7. 発展：カラス時の 8×8 ヒートマップ

分類が動いた後の拡張。設計だけ先に置く（実装は後段）。

- **タスク化**: 8×8 の**占有グリッド回帰**（各ゾーンに「カラスらしさ」0〜1）。`Conv → TRANSPOSE_CONV/RESIZE で 8×8 にアップサンプル → Sigmoid(Logistic)` の小ヘッドを分類と共有エンコーダにぶら下げる**マルチタスク**が省メモリ。
- **正解ラベル**: 背景差分の前景ブロブ重心に**ガウシアン**を置いて 8×8 の教師マップを自動生成（手動アノテーション最小化）。
- NPU op 的には TRANSPOSE_CONV / RESIZE_NEAREST_NEIGHBOR / LOGISTIC が int8 Yes なので実装可能。

---

関連: [firmware.md](./firmware.md)（ビルド・書き込み・west）/ [roadmap.md](./roadmap.md)（Step4 カラス検出）/ [sensor-processing.md](./sensor-processing.md)（特徴量）

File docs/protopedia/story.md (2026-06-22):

# TerraGuard AI — ストーリー

> **カラス追い払いソリューションの第一歩として、「カラス検出機能」を実現しました。**
> 低解像度サーマル＋距離センサと、FRDM-MCXN947 のオンチップAI（eIQ Neutron NPU）だけで、
> カメラを使わず・インターネットにもつながず・たった1羽のカラスを見つけ出す番人です。

DigiKey Make ONE Challenge 2026 応募作品 ／ 使用ボード: **NXP FRDM-MCXN947**（おすすめ製品）

---

## この作品の「イチ（ONE）」— 3つの 1 が重なっています

本コンテストのテーマは「**1（イチ）**」。TerraGuard AI には、性質の異なる「1」が三重に重なっています。

### 1️⃣ ONE chip — たった 1 枚の MCU だけでエッジAIを完結

クラウドサーバ **0**、追加のマイコンボード **0**、カメラ **0**。
センサの取得から前処理、AI推論、検出判定までを、**FRDM-MCXN947 という 1 枚のボード（MCU ワンチップ）だけ**でやりきっています。
ネットにつながず、画像も外に出さず、手のひらサイズの 1 チップで完結する——これが本作の技術的な背骨です。
（"Make **ONE** Challenge" のテーマと、"FRDM-MCXN947" を **ONE chip** で使い切るアプローチのダブルミーニングでもあります。）

### 2️⃣ ONE crow — たった 1 羽の侵入者も見逃さない番人

ゴミ置き場を荒らすのは、群れではなく、まず **1 羽**のカラスです。
TerraGuard AI（テラガード＝「大地を守る番人」）は、**その 1 羽が現れた瞬間**を、温度と距離の小さな“まとまり”として捉えます。
カメラの代わりに **32×24 の低解像度サーマル**と **8×8 の距離センサ**しか使わないため、通行人や住民の顔は写りません。
**「1 羽を見つける」プライバシー配慮型の番人**です。

### 3️⃣ ONE first — 私にとって “1 回目” の、完全AIによるファームウェア開発

そしてもう 1 つ。本作は、**人間が一切手を動かさずに**完成させた、
私にとって **初めて（＝1 回目）の「完全AIファームウェア開発」**プロジェクトです。
コードの実装はもちろん、**ビルド・実機への書き込み（flash）・AIモデルの学習コマンドの実行まで、すべて AI コーディングエージェント Claude Code がハンドリング**しました（詳細は後述）。
人間は **コードを 1 行も書かず・1 度も見ず・ビルドも書き込みも学習も実行していません**——これも、もう 1 つの「イチ」です。

---

## なぜ作ったのか — 課題

都市部や住宅地では、**カラスがゴミ袋を破り、ゴミ置き場を荒らす**被害が後を絶ちません。
従来の対策——ネット、物理カバー、人による見張り——は、カラスの学習能力や設置環境によって効果が限定的になりがちです。

「ならばカメラAIで監視すればよい」とも考えられますが、住宅地では大きな問題があります。

- **プライバシー**: 通行人や住民の顔・姿が映り込む。ゴミ出しは生活そのもので、撮られたくない。
- **通信・電力・コスト**: クラウドAIは常時通信・電力・運用費がかかり、屋外の小さな見守りには重すぎる。

**カラスを追い払うには、まず「カラスがいる」と正しく気づくこと。**
TerraGuard AI は、この **“気づき”の部分（検出）**を、**カメラを使わず・クラウドにも頼らず**実現することから始めました。

---

## 何を実現したのか — カラス検出機能（追い払いソリューションの第一歩）

今回のスコープは、追い払いソリューション全体の **第一歩 = 「カラス検出」**です。

ゴミ置き場に向けて設置した 2 つの低解像度センサ——

- **MLX90640**（サーマル、32×24 の温度分布）
- **VL53L5CX**（ToF、8×8 の距離分布）

——のデータを、FRDM-MCXN947 が **背景差分で「いま現れたもの（前景）」だけ**を抜き出し、
温度と距離を **4 チャンネルの小さな画像（24×24×4）** に束ねて、
オンチップの **eIQ Neutron NPU** で動く小型 CNN に通します。

カラスは「**暖かくて（羽毛表面 約30〜35℃）・かつ・背景より手前に出た・小さなまとまり**」として現れます。
温度だけ／距離だけでは、日なたの壁や人・物の通過と区別がつきません。
**温度と距離を 1 つの AI に同時入力する**ことで、その同時条件をAIが学習で捉え、
さらに **約1.4秒の連続検出（デバウンス）**で単発の誤反応を抑えて、「**確定 crow（カラス）**」を判定します。

確定した瞬間に**ステータスLEDが点灯**します。これが、次の「追い払い」へ渡すトリガーになります。

| カラスがいる → **検出** | 人がいる → **誤検出しない** |
| :---: | :---: |
| カラス検出 | 非カラス |
| ダミーガラスに **CROW DETECTED**（p=100%）。 | 人が写っても **not crow**。温度・距離のパターンが違う。 |

> 実機で、ライブ背景に対する誤検出をほぼ 0 に抑えつつ、カラス相当の対象を検出できることを確認済みです。
> 人が写っても誤検出しない（＝カメラレスでプライバシーを守りつつ、人とカラスを取り違えない）点が重要です。

---

## 次の展開 — 緑色レーザーによる追い払い

検出は、ゴールではなく **第一歩**です。

次の展開は、**確定検出をトリガーにした「緑色レーザーによるカラスの追い払い」**です。
カラスは緑色のレーザー光を嫌うことが知られており、検出で得た**位置情報（前景の重心）**に向けて
レーザーを向けることで、**カラスにだけ・ピンポイントで・非接触で**圧力をかけて立ち去らせる——という構想です。

この「検出 → 追い払い」を **同じ FRDM-MCXN947 の 1 チップ**で完結させ、
**気づいて、狙って、追い払う**までを 1 枚のボードでやりきるのが、TerraGuard AI の最終形です。

```text
[今回 ✅ 実現]                 [次の展開]
カラス検出                  →   緑色レーザーで追い払い
(サーマル+距離+NPU)              (検出位置へ照準・カラスだけに作用)
        └──────── 同じ FRDM-MCXN947 1チップで完結 ────────┘
```

---

## アプローチの面白さ① — FRDM-MCXN947 を「1チップのエッジAI」として使い切る

本作の核心は、**おすすめ製品である NXP FRDM-MCXN947 を、外部に頼らず 1 枚で使い切っている**ことです。

| 価値 | TerraGuard AI での実現 |
| --- | --- |
| **インターネット接続 不要** | センサ取得〜AI推論〜判定まで全部オンボード。クラウドに 1 バイトも送らない。 |
| **低消費電力** | 推論はオンチップの **eIQ Neutron NPU**。CPUで回すより高速・低電力（実測 推論 1 回 約0.2ms〜）。 |
| **プライバシー配慮** | カメラを使わず、32×24＋8×8 の低解像度センサのみ。**人物が判別できる映像が原理的に存在しない**。 |
| **追加ボード 0** | 中継用の Arduino 等を一切使わず、センサを FRDM-MCXN947 に**直接 I2C 接続**。 |

FRDM-MCXN947 は、**デュアル Cortex-M33 + DSP + eIQ Neutron NPU** を 1 つに載せ、
オンボード MCU-Link デバッガまで備えた開発ボードです。
「センサを直結でき」「エッジでAIを回せ」「単体で開発・デバッグできる」——
**1 チップでエッジAIプロダクトを成立させる**という本作のコンセプトに、これ以上ない適材でした。

---

## アプローチの面白さ② — “1 回目” の完全AIファームウェア開発

本作のもう 1 つの挑戦は、**開発プロセスそのもの**にあります。
制作者（人間）は、**開発作業に一切手を動かしていません**。具体的には——

- **コードを書いていない**: ファームウェア（C / MCUXpresso SDK）は AI コーディングエージェント **Claude Code が実装**。人間は **1 行も書かず、1 度もコードを開いていません**。
- **ビルドしていない**: `cmake --build`（CMake / armgcc）の実行は**すべて AI**。
- **書き込み（flash）していない**: LinkServer による実機への書き込みも**すべて AI**。
- **学習コマンドも叩いていない**: データセット構築・int8量子化での学習・NPU 変換・モデルヘッダ生成といった ML パイプラインのコマンド実行も**すべて AI**。
- **実機確認も AI**: シリアルログ（921600）の取得・解析による不具合の切り分けまで AI が担当。

つまり制作者の役割は「何を作るか」を伝え、USB の抜き差しなど物理操作を手伝うことだけ。
**コードもビルドも書き込みも学習も、エンジニアリングのハンドリングは丸ごと AI**——これが本作の開発手法です。

これを成立させた仕掛けは 2 つです。

1. **開発プロジェクトの土台づくり**: FRDM-MCXN947 のビルド・書き込み環境（MCUXpresso SDK のプロジェクト一式）をセットアップし、AI が手を動かせる足場を整えた。
2. **FRDM-MCXN947 開発用「スキル」の自作**: ビルド／書き込み／シリアル確認／I2C 配線／NPU 学習・変換などの**確定手順とハマりどころを AI 向けのスキルとして記述**。AI はそのスキルを起動するだけで、毎回ブレずに実機開発を進められる。

> 結果として、**人手のコーディングを 0 にしたまま**、サーマル・距離センサ駆動、背景差分、NPU 推論、デバウンスまでを実装し、**実機でカラス検出が動くところまで到達**しました。
> これは「AIエージェントに、組み込み／エッジAI開発をどこまで任せられるか」の 1 つの実証であり、**他の参加者がそのまま学べる再現可能なアプローチ**として、リポジトリにスキルとドキュメントを公開しています。

---

## 開発体制 — 人間 × AI のチーム

本作は、役割を明確に分けた **人間 × AI のチーム**で制作しました。

| 担当 | 役割 |
| --- | --- |
| **キッズクリエーター かなた** | 発案、意匠デザイン、デモデザイン |
| **Claude Code**（AIエージェント） | ファームウェア開発、学習モデルデザイン |
| **かなたパパ** | AI の進捗管理、開発しやすい環境構築、はんだづけ |
| **かなた ＋ かなたパパ**（協働） | 外装の 3D 設計（Autodesk Fusion）・3Dプリント |

外装（ケース）は、ボードと 2 つのセンサを収めて屋外のゴミ置き場に設置できるよう、
**Autodesk Fusion で 3D 設計し、3Dプリンタで製作**しました（かなたとかなたパパのふたりで協働）。
作品の見た目を作る部分は、親子で手を動かしています。

「**何を作るか**」を子ども（発案・デザイン）が決め、「**どう作るか**」を AI（実装・モデル）が担い、
大人は「**AI が走りやすいレールを敷くこと**（環境構築・進捗管理）と物理作業（はんだづけ）」に徹する——
**人間がコードを書かずに、エッジAIプロダクトを形にできた**のは、この役割分担そのものが成果でもあります。

---

## まとめ — 3 つの「1」で語る TerraGuard AI

- **1 チップ** で完結するエッジAI（クラウド0・追加ボード0・カメラ0）
- **1 羽**のカラスも見逃さない、プライバシー配慮型の番人（検出 → 追い払いの第一歩）
- **1 回目**の完全AIファームウェア開発（コードもビルドも書き込みも学習も、人間は一切手を動かさず AI がハンドリング）

**「1（イチ）」を、コンセプト・プロダクト・開発手法の三層で体現した作品**です。

---

関連: [system.md](./system.md)（システム構成） ／ プロジェクト詳細は [../overview.md](../overview.md) ほか `docs/` 配下を参照。

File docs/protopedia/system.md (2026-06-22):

# TerraGuard AI — システム構成

> **カラス追い払いソリューションの第一歩「カラス検出機能」**のシステム構成です。
> **FRDM-MCXN947 という 1 枚のボード（MCU ワンチップ）だけ**で、センサ取得〜前処理〜AI推論〜検出判定までを完結させます。
> インターネット接続 不要・低消費電力・カメラレス（プライバシー配慮）。

DigiKey Make ONE Challenge 2026 応募作品 ／ ストーリーは [story.md](./story.md) を参照。

<p align="center">
  TerraGuard AI 完成体（3Dプリント外装＋三脚）
  <br><em>完成体：3Dプリント外装にセンサ2個とステータスLEDを収め、三脚で設置できる。</em>
</p>

---

## 1. システム全体図 — すべてが「1 チップ」に集約

```text
       ┌──────────────────────┐                ┌──────────────────────┐
       │ MLX90640 (サーマル)   │                │ VL53L5CX (ToF 距離)   │
       │ 32×24 温度アレイ      │                │ 8×8 マルチゾーン距離   │
       └──────────┬───────────┘                └──────────┬───────────┘
                  │ I2C (3.3V, 同一バス FC2/LPI2C2)        │
                  └──────────────────┬────────────────────┘
                                     ▼
        ╔════════════════════════════════════════════════════════════╗
        ║            NXP FRDM-MCXN947  （★この 1 枚で完結★）          ║
        ║  ┌──────────────────────────────────────────────────────┐  ║
        ║  │ デュアル Arm Cortex-M33 (最大150MHz) + DSP            │  ║
        ║  │ ① センサ取得  ② 前処理(回転/crop/背景差分/前景化)     │  ║
        ║  │ ③ 4ch テンソル整形 (24×24×4 int8)                    │  ║
        ║  ├──────────────────────────────────────────────────────┤  ║
        ║  │ eIQ Neutron NPU  ④ 小型CNN 推論 → [not_crow, crow]   │  ║
        ║  └──────────────────────────────────────────────────────┘  ║
        ║  ⑤ 時間デバウンス(約1.4秒連続でcrow確定)                     ║
        ║  ⑥ ステータスLED 点灯 / シリアル(INFER)出力                  ║
        ╚════════════════════════════════════════════════════════════╝
                                     │
                       (クラウド・外部ボード・カメラは一切なし)
```

- **クラウド 0 / 追加ボード 0 / カメラ 0**。センサは FRDM-MCXN947 に**直接 I2C 接続**。
- 推論は CPU ではなく**オンチップの eIQ Neutron NPU** で実行（低消費電力・低レイテンシ）。
- 出力は**ローカルで完結**（LED 点灯 ＋ デバッグ用シリアル）。画像はボード外に一切出ない。

---

## 2. ハードウェア構成

### 2-1. 中核ボード — NXP FRDM-MCXN947（おすすめ製品）

| 項目 | 内容 |
| --- | --- |
| MCU | MCXN947（**デュアル Arm Cortex-M33、最大150MHz** + DSP コプロセッサ） |
| AIアクセラレータ | **eIQ Neutron NPU**（エッジAI推論を高速・低消費電力で実行） |
| メモリ | 最大 2MB デュアルバンク Flash |
| センサ接続 | **I2C / I3C**（MLX90640・VL53L5CX を直接接続） |
| デバッガ | オンボード **MCU-Link**（USB 1 本で書き込み・デバッグ。追加プローブ不要） |
| 開発環境 | **MCUXpresso SDK**（CMake / armgcc、LinkServer 書き込み） |

**このボードを選んだ理由**: 「センサ直結」「エッジAI（NPU）」「単体で開発・デバッグ完結」が 1 枚で揃い、
**“1 チップでエッジAIプロダクトを成立させる”** という本作のコンセプトに最適だったため。
本コンテストのおすすめ製品でもあります。

### 2-2. センサ

| センサ | 役割 | 解像度 / IF | 検出での意味 |
| --- | --- | --- | --- |
| **MLX90640**（110°版） | サーマル（温度分布） | 32×24 / I2C(0x33) | カラスの**羽毛表面 約30〜35℃**を熱源として捉える |
| **VL53L5CX** | ToF 距離（奥行き分布） | 8×8 / I2C(0x29) | カラスが**背景より手前に出た**ことを距離差で捉える |

- 2 センサは**同一 I2C バス（FC2 / LPI2C2, P4_0=SDA / P4_1=SCL）**に共存（アドレス衝突なし）。
- いずれも **3.3V 直結 OK**（レベル変換不要）。Breakout 基板のプルアップを利用。
- **カメラを使わない**ことが本作の肝。32×24＋8×8 の低解像度では人物を判別できる映像が原理的に成立せず、**プライバシーが構造的に守られる**。

### 2-3. 配線（実機疎通済み）

<p align="center">
  外装内部：FRDM-MCXN947 とセンサ2個の結線
  <br><em>外装内部。FRDM-MCXN947 に MLX90640（サーマル）と VL53L5CX（距離）を I2C 直結している。</em>
</p>

外部センサは **J8 ヘッダ pin1〜4** に最短接続（追加ハンダ付け不要）。

```text
FRDM-MCXN947  J8           センサ (MLX90640 / VL53L5CX)
  pin1 (P3V3, 3.3V) ────── VCC
  pin2 (GND)        ────── GND
  pin3 (P4_1, SCL)  ────── SCL
  pin4 (P4_0, SDA)  ────── SDA
```

> 詳細・代替ヘッダ（J2 / J7）・I2C クロック設定は [../hardware.md](../hardware.md) を参照。

### 2-4. 外装（Autodesk Fusion 設計 ＋ 3Dプリント）

ゴミ置き場に設置することを想定し、ボードと 2 つのセンサを収める**専用外装を Autodesk Fusion で 3D 設計し、3Dプリンタで製作**しました。

- サーマル（MLX90640）と距離（VL53L5CX）の**画角・取り付け向き**（サーマルは90度回転実装）に合わせてセンサ窓・マウント位置を設計。
- USB（給電・書き込み）を通すケーブル口を確保し、**設置したまま開発・デバッグ**できる形状に。
- 外装デザインは作品の見た目（③表現力）にも直結する要素として、**かなた と かなたパパ がふたりで協働**して設計・出力しました。

---

## 3. 検出パイプライン（1 フレームの流れ）

<p align="center">
  カラス検出パイプライン
</p>

実装（`src/FRDM-MCXN947/terra-guard-ai/app/`）に忠実なデータフローです。

```text
① 取得         サーマル32×24[℃]            距離8×8[mm]
                  │                            │
② 整形      90度右回転＋中央24行crop      左右反転＋無効ホールド
            → 24×24=576画素[℃]            → 8×8=64ゾーン[mm]
                  │                            │
③ 背景差分   thermal_fg=max(0,cur-bg)     dist_fg=max(0,bg-cur)
            (背景より暖かい正側)          (背景より手前の正側)
                  └──────────┬─────────────────┘
                             ▼
④ 4ch整形    24×24×4 int8 テンソル
              ch0 thermal_abs (絶対温度)
              ch1 thermal_fg  (サーマル前景)
              ch2 distance     (距離8×8→最近傍3倍で24×24)
              ch3 distance_fg  (距離前景8×8→24×24)
                             ▼
⑤ NPU推論    eIQ Neutron NPU 小型CNN → Softmax [not_crow, crow]
                             ▼
⑥ デバウンス  約1.4秒（≒10フレーム）連続 crow で「確定crow」
                             ▼
⑦ 出力        ステータスLED点灯 ＋ INFER 行をシリアル出力
              （= 次工程「緑色レーザー追い払い」へのトリガー）
```

- 完成サーマルフレームは実測 **約7fps**。NPU 推論はサーマル完成ごと（約7回/秒）に駆動。
- **なぜ温度と距離を 1 つの AI に束ねるか**: カラスは「暖かくて・かつ・背景より手前に出た・小さなまとまり」。
  単一センサでは日なたの壁（温度のみ）や人・物の通過（距離のみ）と区別できない。
  **4ch を 1 つの CNN に同時入力**して、その同時条件を学習で取り出すのが核心。

---

## 4. AIモデル（eIQ Neutron NPU 上の小型CNN）

```text
Input [24,24,4]
  Conv 8  3x3 relu → MaxPool2     → 12x12x8
  Conv 16 3x3 relu → MaxPool2     → 6x6x16
  Conv 24 3x3 relu → AvgPool(6,6) → Flatten → 24
  Dense 2 softmax
Output [1,2] = [p_not_crow, p_crow]
```

- **2クラス**（not_crow / crow）の小型 CNN。**full-integer int8 量子化**して NPU 向けに変換。
- NPU 非対応 op を避ける設計（GlobalAvgPool → 明示サイズ AvgPool で代替 等）。
- **ファームの前処理と学習側の前処理を 1 対 1 で厳密一致**させ、実機判定が学習時とずれないようにしている。

---

## 5. 開発手法 — “1 回目”の完全AIファームウェア開発

本作は、コードの実装からビルド・実機への書き込み・AIモデルの学習まで、
**開発のすべての工程を AI コーディングエージェント Claude Code がハンドリング**しました。
**人間（制作者）は一切手を動かしていません**——コードを 1 行も書かず・1 度も開かず、
ビルドも・書き込みも・学習コマンドの実行もしていません。

| 工程 | 担当 | 人間の関与 |
| --- | --- | --- |
| コード実装 | C / MCUXpresso SDK を **AI が記述** | 0 行（1 度も閲覧せず） |
| ビルド | `cmake --build`（CMake/armgcc）を **AI が CLI 実行** | なし |
| 書き込み（flash） | LinkServer による実機書き込みを **AI が CLI 実行** | なし |
| 学習コマンド | データ収集・int8量子化学習・NPU変換・ヘッダ生成を **AI が CLI 実行** | なし |
| 実機確認 | シリアルログ（921600）を **AI が取得・解析**して切り分け | USB 抜き差し等の物理操作のみ |

これを支えた仕掛け:

1. **開発プロジェクトの土台**: FRDM-MCXN947 のビルド・書き込み環境（MCUXpresso SDK プロジェクト一式）を整備し、AI が手を動かせる足場を用意。
2. **FRDM-MCXN947 開発用スキルの自作**: ビルド／書き込み／シリアル／I2C 配線／NPU 学習の**確定手順とハマりどころ**を AI 向けスキルに集約。AI はスキルを起動するだけで毎回ブレずに実機開発できる。

### 開発体制（人間 × AI）

| 担当 | 役割 |
| --- | --- |
| **キッズクリエーター かなた** | 発案、意匠デザイン、デモデザイン |
| **Claude Code**（AIエージェント） | ファームウェア開発、学習モデルデザイン |
| **かなたパパ** | AI の進捗管理、開発しやすい環境構築、はんだづけ |
| **かなた ＋ かなたパパ**（協働） | 外装の 3D 設計（Autodesk Fusion）・3Dプリント |

---

## 6. 部品表（DigiKey / myLists）

| 部品 | 役割 | 入手 |
| --- | --- | --- |
| **NXP FRDM-MCXN947** 開発ボード | 中核（MCU + DSP + eIQ Neutron NPU、センサ直結・単体開発） | [DigiKey](https://www.digikey.jp/ja/products/detail/nxp-usa-inc/FRDM-MCXN947/22036137) |
| **MLX90640**（サーマル 32×24, 110°） | 温度分布センサ | [DigiKey](https://www.digikey.jp/ja/products/detail/sparkfun-electronics/14843/9657955) |
| **VL53L5CX**（ToF 8×8） | 距離分布センサ | [DigiKey](https://www.digikey.jp/ja/products/detail/sparkfun-electronics/18642/15775141), [StrawberryLinux](https://strawberry-linux.com/catalog/items?code=15315) |

[Digikey 部品リスト](https://www.digikey.jp/ja/mylists/list/QGSF94NSJU) にもまとまっています。

---

## 7. 「1 チップ完結」が生むメリット（まとめ）

| メリット | 仕組み |
| --- | --- |
| **インターネット接続 不要** | 取得〜推論〜判定まで全部オンボード。クラウド送信 0。 |
| **低消費電力** | 推論はオンチップ eIQ Neutron NPU。CPU 実行より高速・低電力。 |
| **プライバシー配慮** | カメラレス。32×24＋8×8 の低解像度のみで人物が判別不能。 |
| **設置が容易** | 追加ボード 0、センサ直結、USB 1 本で開発・給電・デバッグ。 |
| **拡張の一貫性** | 次工程「緑色レーザー追い払い」も同じ 1 チップに載せて完結できる。 |

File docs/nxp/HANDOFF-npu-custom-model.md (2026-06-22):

# 申し送り — 自作NPUモデル差し替え ✅ 疎通成功（converter版不一致 解決済み）

最終更新: 2026-06-20 / branch `feat/eiq-npu-model` / GitHub Issue #2

## 🎉 結論（2026-06-20）

**自作モデルが FRDM-MCXN947 の eIQ Neutron NPU で推論ループを回すことを実機確認。疎通レベルのゴール達成。**

converter 版不一致は、**SDK同梱 3.0.0（`sdk/eiq-neutron-sdk-linux-3.0.0`, microcode `0X6d41ac8b`）で再変換**し、
さらに **op resolver を 3op 化（Softmax + Slice + NEUTRON_GRAPH）** することで完全に解消した
（3.0.0版の生.hは 3.1.3版と違い **Slice が追加される**点が落とし穴）。

実機ログ（115200, 受信先行→flash）:
```
Model: terra_guard_npu
Model Size: 0x1060 (4192 B)
TensorArena ... Used 0x23f4 (9204 B)
     Inference time: 221 us        ← NPU推論が回った（Invoke成功・Microcode mismatch消滅）
     Detected: No label detected (0%)   ← 未学習ランダム重みなので想定通り
```

本番の学習（none/crow/human の実データ学習）は後続フェーズ。

## ゴール

検証済みの tflm_cifar10(NPU版) パイプラインに、自作3クラスモデル（none/crow/human）の
`model_data.h` を差し替えて、自作モデルが FRDM-MCXN947 の eIQ Neutron NPU で
**推論ループを回す（疎通レベル）** ことを実機確認する。
※現状の自作モデルは「未学習のランダム重み tiny CNN」。形だけ本番相当（入力 [1,24,32,1]、出力 [1,3]）。
本番の学習は後続フェーズ。

## ✅ 完了していること

1. **前提**: tflm_cifar10(NPU版) は実機正常動作確認済み（`ship 99%` / 推論7.1ms）。
   「無音」の真因は受信タイミング取りこぼし。**正しい受信手順 = 受信を先に開始(115200) → その後
   `LinkServer flash load` でクリーン起動**（詳細 `docs/nxp/HANDOFF-npu-cifar10-debug.md`）。

2. **自作モデル生成〜変換〜差し替え機構を構築済み**:
   - `tools/ml/make_test_model.py` → int8 TFLite（`arch -arm64 tools/ml/.venv/bin/python` で実行。**arch -arm64 必須**）。
     出力: `tools/ml/build/terra_guard_int8.tflite`（5552B, 入出力int8, [1,24,32,1]→[1,3]）。
   - `tools/ml/neutron_convert.sh` で NPU 変換（変換率9/10）。
   - **新規ツール `tools/ml/make_model_data_h.py`**: neutron-converter の生 `.h` を SDK 枠
     （`__PLACEMENT`=`.model`(flash配置) / `kTensorArenaSize` / `MODEL_INPUT_MEAN/STD` / `MODEL_NAME`）
     に流し込んで、SDK にそのまま置ける `model_data.h` を合成する。
   - SDK の cifar10 pcq_npu を差し替え済み（**バックアップあり**: `pcq_npu.orig`）:
     - `.../tflm_cifar10/pcq_npu/model_data.h` ← 自作モデル（MODEL_NAME="terra_guard_npu", arena=64KB, 4192B/v300）
     - `.../tflm_cifar10/pcq_npu/model_cifarnet_ops_npu.cpp` ← op resolver **3op**(Softmax + Slice + NEUTRON_GRAPH)
       （op構成は model_data.h 冒頭スニペットに合わせる。3.0.0版では Slice が入る）

3. **ビルド・実機・推論まで完了**:
   west build（`--config flash_debug`）成功 → 自作モデル(4192B)が flash1(`.model`)に配置。
   実機で `Model: terra_guard_npu` ロード → `MODEL_Init`/`AllocateTensors` 成功 → **Invoke成功(221us)**。

## ✅ 解決した問題（converter版不一致）

かつて自作モデルの **Invoke(推論実行)** が失敗していた:
```
Microcode version mismatch! ... model converted with 3.5371...-0X59ef
Internal Neutron NPU driver error 109 in model run!  →  Node NeutronGraph failed status 1  →  Invoke failed!
```
**真因**: neutron-converter のバージョン不一致。
- SDK内蔵 mcxn ドライバ = **driver 3.0.0**（元cifar10は **converter 3.0.0+0X6d41ac8b** で変換）。
- 当初使った converter = **3.1.3+0X1e788118**（`sdk/eiq-neutron-sdk-linux-3.1.3`）→ 不一致。

**解決手順（実施済み）**:

1. 3.0.0 で再変換（`sdk/eiq-neutron-sdk-linux-3.0.0`, version `3.0.0+0X6d41ac8b` 確認済み）:
   ```bash
   NEUTRON_SDK_DIR=$PWD/sdk/eiq-neutron-sdk-linux-3.0.0 \
     ./tools/ml/neutron_convert.sh \
       tools/ml/build/terra_guard_int8.tflite \
       tools/ml/build/terra_guard_int8_mcxn94x_v300.tflite mcxn94x
   # 生成 .h の microcode が 0X6d41ac8b（=SDKドライバ3.0.0）になる
   ```
2. **⚠️ op resolver を 3op に修正（重要な落とし穴）**: 3.0.0版の生.h冒頭スニペットは
   `Softmax + Slice + NEUTRON_GRAPH` の **3op**（3.1.3版は2op）。`model_cifarnet_ops_npu.cpp` を
   `MicroMutableOpResolver<3>` + `AddSlice()` に修正。
3. SDK枠に流し込み → 配置:
   ```bash
   arch -arm64 tools/ml/.venv/bin/python tools/ml/make_model_data_h.py \
     --src-h tools/ml/build/terra_guard_int8_mcxn94x_v300.h \
     --out tools/ml/build/model_data.h --name terra_guard_npu --arena 65536
   cp tools/ml/build/model_data.h \
     ~/mcuxpresso/mcuxsdk/mcuxsdk/examples/_boards/frdmmcxn947/eiq_examples/tflm_cifar10/pcq_npu/model_data.h
   ```
4. ビルド → 受信先行 → flash → ログ確認:
   ```bash
   export ARMGCC_DIR=~/.mcuxpressotools/arm-gnu-toolchain-14.2.rel1-darwin-arm64-arm-none-eabi
   export PATH="$HOME/.mcuxpressotools/.mcux-venv-3.12/bin:$PATH"   # ← mcux venv 必須(system python3.14だと失敗)
   (cd ~/mcuxpresso/mcuxsdk/mcuxsdk && west build -b frdmmcxn947 examples/eiq_examples/tflm_cifar10 \
     --toolchain armgcc -Dcore_id=cm33_core0 --config flash_debug -d /tmp/build_cifar10 --pristine always)
   # 受信(115200)を先に開始 → LinkServer flash load .../tflm_cifar10_cm33_core0.elf
   # 結果: Inference time: 221 us / Detected 表示（Microcode mismatch 消滅）= 疎通成功
   ```

## 🔜 次フェーズ（本番化）

疎通は完了。次は **本番モデルの学習・配備**:
- not_crow/crow の2クラス実データで学習し int8 量子化。**入力は 24×24×4**（thermal_abs / thermal_fg / distance / distance_fg）。MLX90640 のサーマルは生 32×24 を取得直後に `rotate_crop` で 24×24 化したものを使い、距離 8×8 は 3倍 kron で 24×24 に拡大する（処理は一貫して 24×24。確定仕様は [../ml-model.md](../ml-model.md) §3.5）。※「none/crow/human の3クラス・32×24」は旧設計。
- 量子化後は同じ手順（3.0.0再変換 → op resolver合わせ → make_model_data_h → 配置 → ビルド/flash）で差し替え。
- 推論結果（`Detected: ...`）を背景差分の検出パイプラインに接続（[[terra-guard-bg-subtraction]]）。
- 最終的には tflm_cifar10 サンプルの間借りをやめ、terra-guard-ai プロジェクト本体へ model.cpp / pcq_npu / op resolver を取り込む。
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

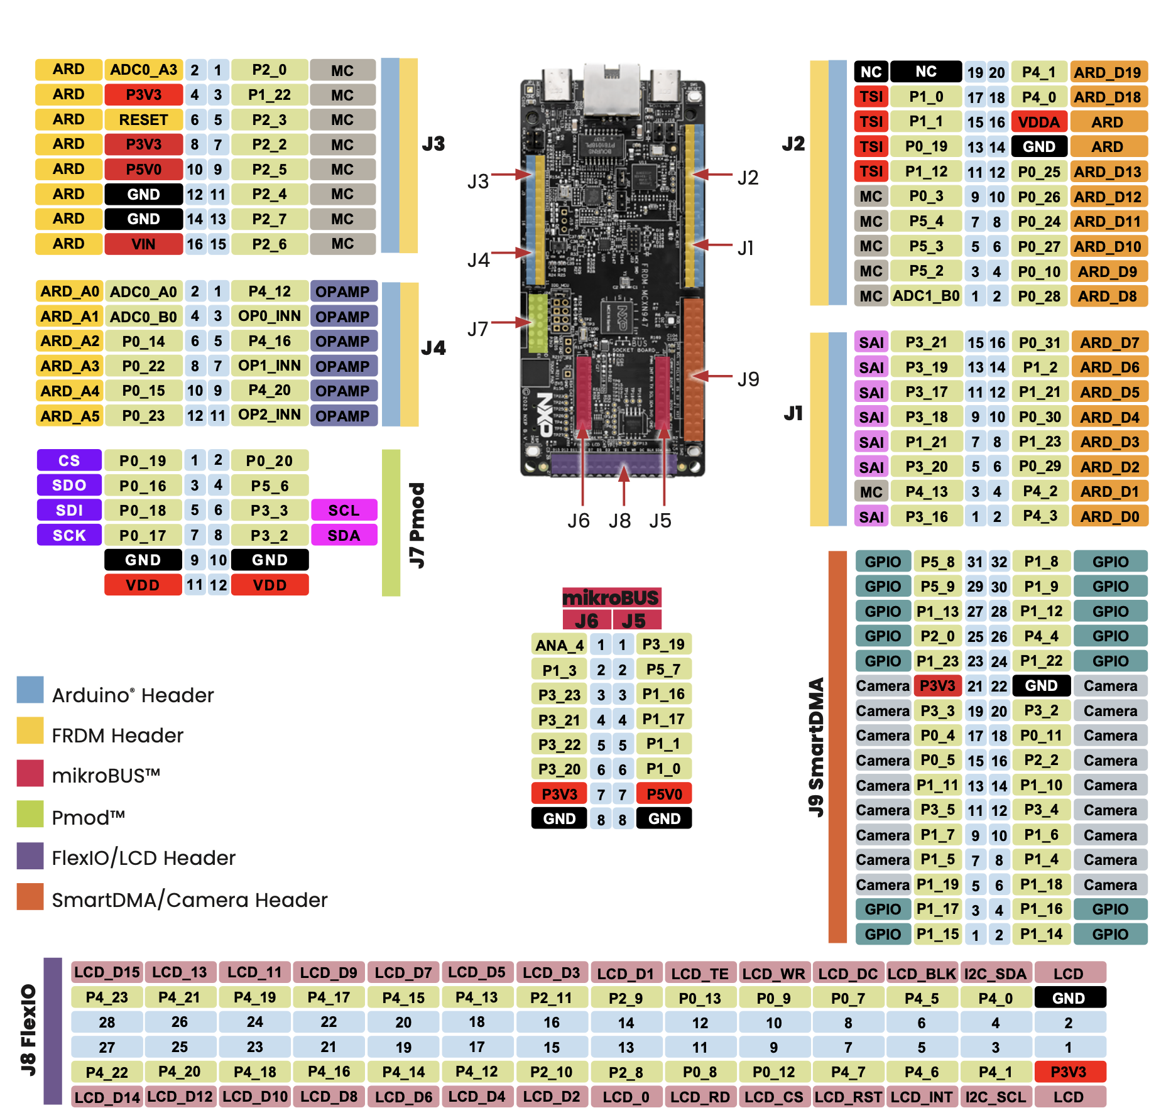
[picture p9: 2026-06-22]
docs/datasheets/FRDM-MCXN947/FRDM-MCXN947-pin-layout.png

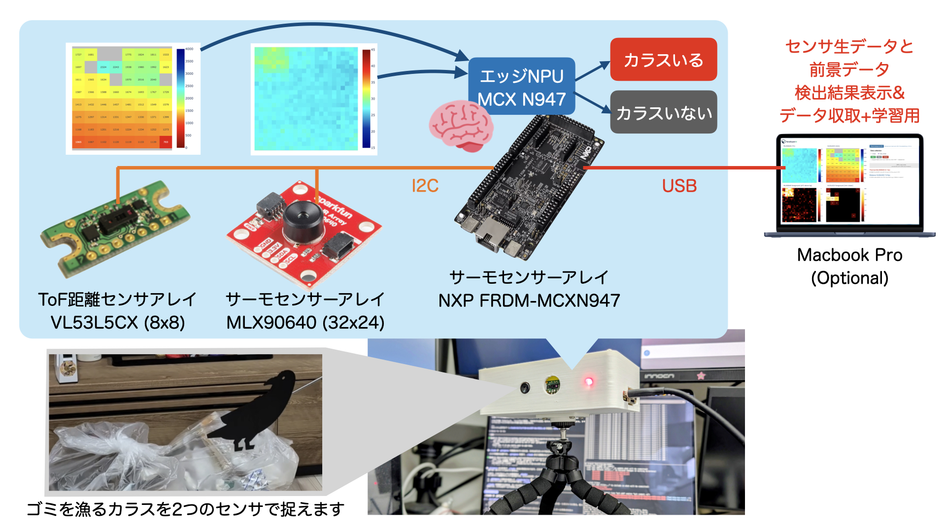
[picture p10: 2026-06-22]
docs/protopedia/drawings/drawings.001.jpeg

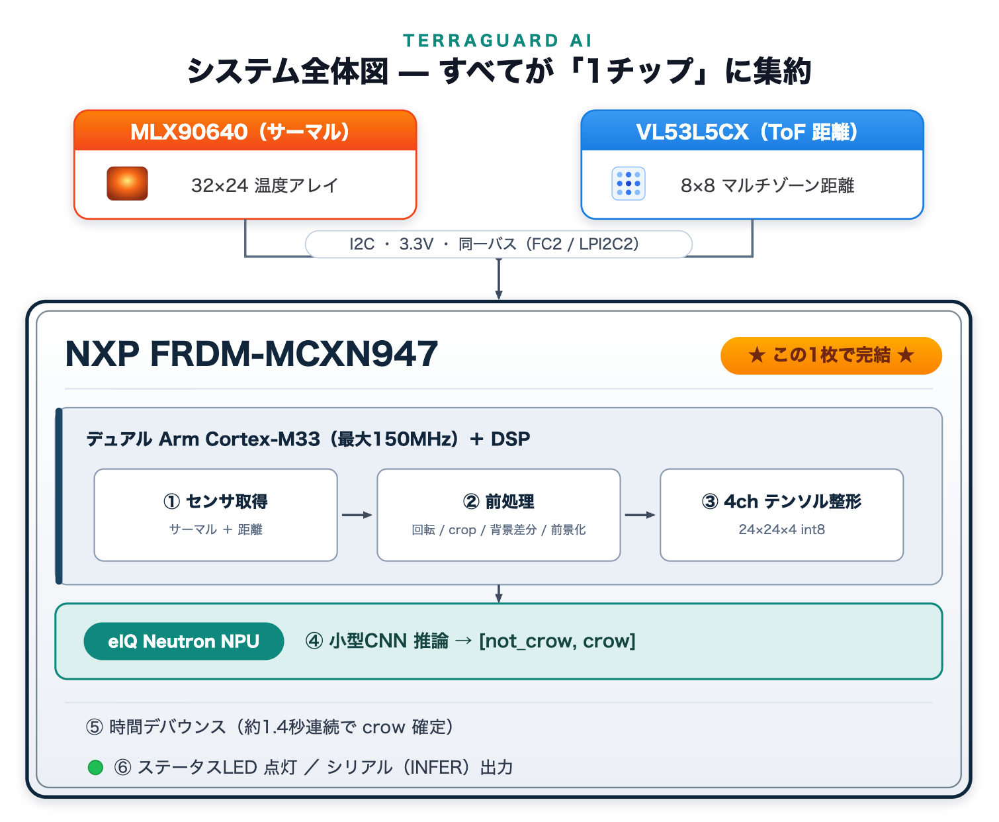
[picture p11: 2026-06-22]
docs/protopedia/images/system-structure.png

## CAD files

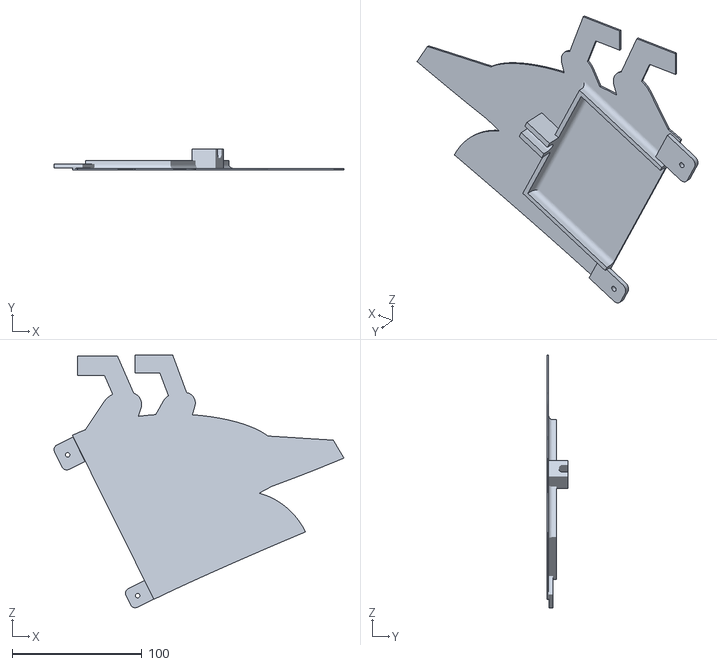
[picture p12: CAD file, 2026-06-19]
3d-models/craw/craw-small1.stl
223.2 x 16.2 x 194.4

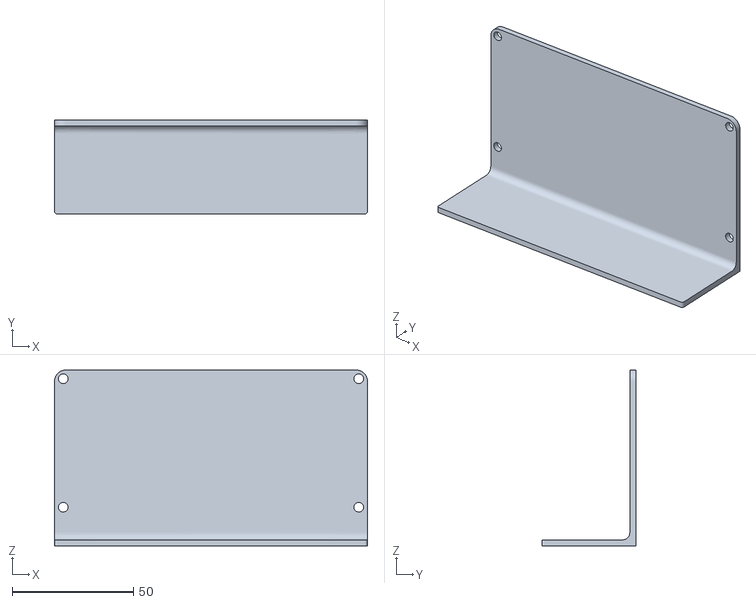
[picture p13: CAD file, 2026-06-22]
3d-models/enclosure/terra-guard-box-top.stl
129.2 x 38.7 x 72.6

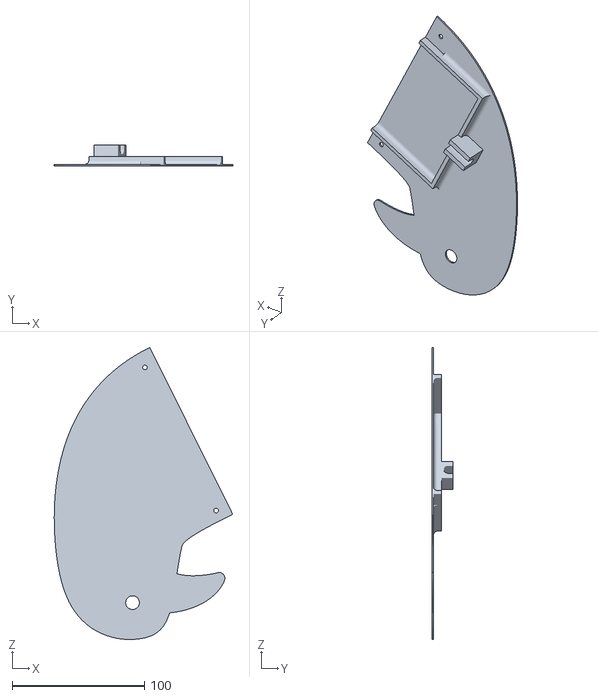
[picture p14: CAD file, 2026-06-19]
3d-models/craw/craw-small2.stl
135.2 x 16.2 x 221.0

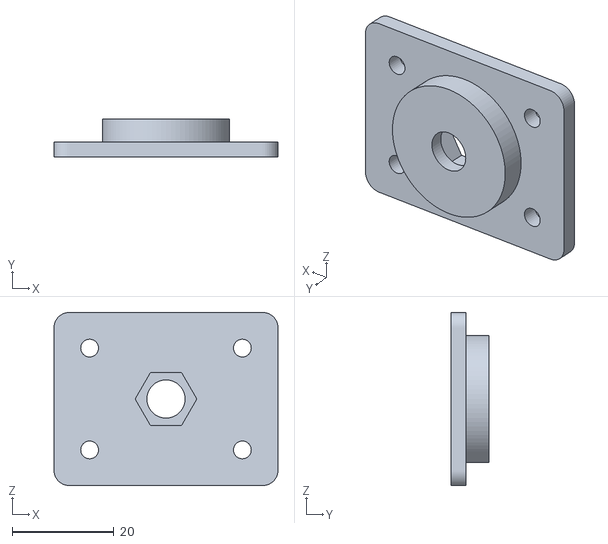
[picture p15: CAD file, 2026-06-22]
3d-models/enclosure/terra-guard-camera-joint.stl
44.0 x 7.50 x 34.0

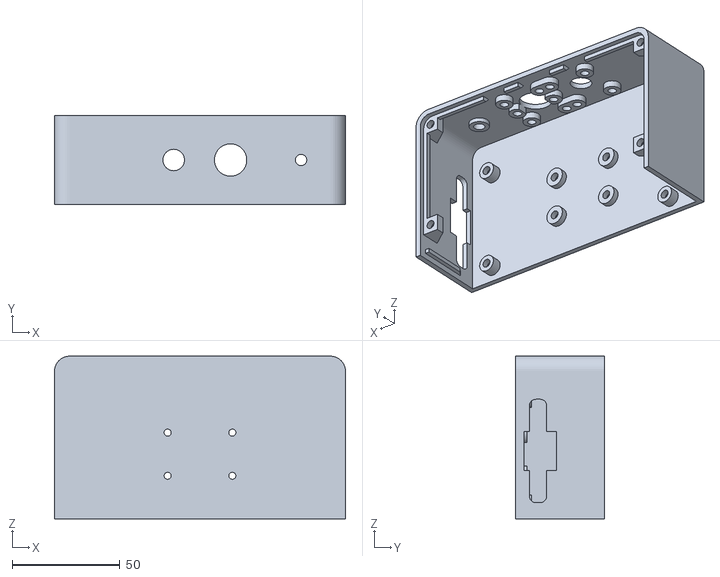
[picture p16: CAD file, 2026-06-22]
3d-models/enclosure/terra-guard-box-bottom.stl
135.0 x 41.4 x 75.5

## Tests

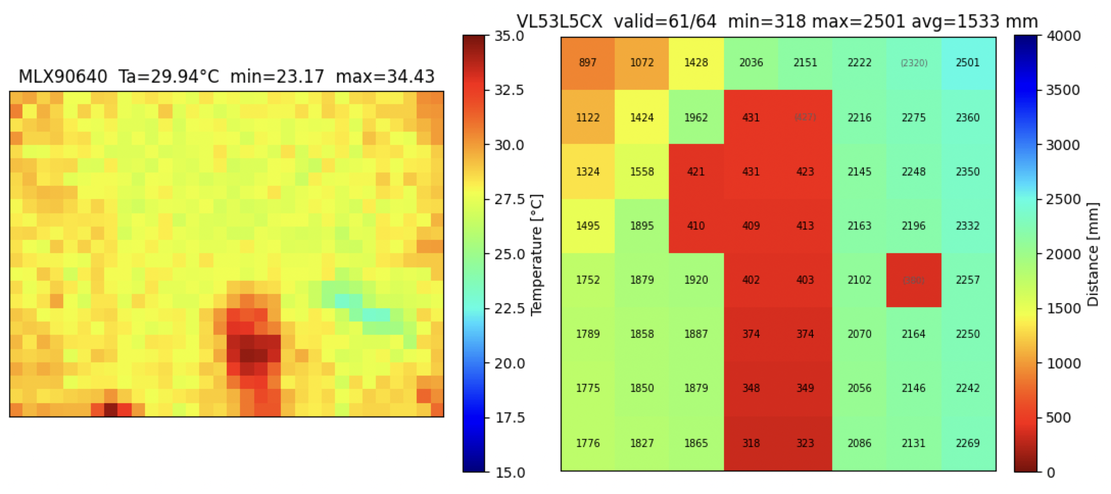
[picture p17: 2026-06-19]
images/thermal-camera-test/thermal-distance.png

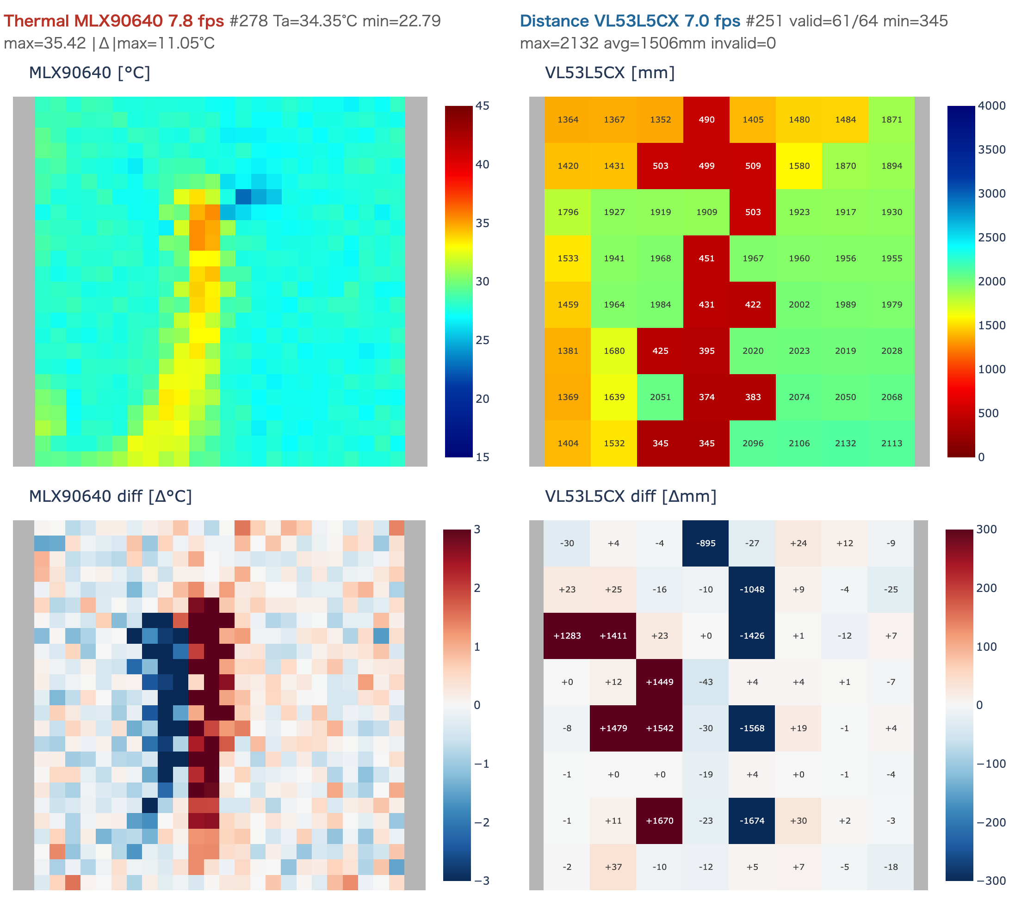
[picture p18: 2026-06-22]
images/thermal-camera-test/thermal-distance-diff.png

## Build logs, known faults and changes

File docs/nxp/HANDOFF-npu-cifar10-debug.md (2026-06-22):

# 申し送り — NPU 疎通確認(tflm_cifar10) ✅ 解決済み

最終更新: 2026-06-20 / branch `feat/eiq-npu-model` / GitHub Issue #2

## 🎉 結論（2026-06-20 解決）

**tflm_cifar10(NPU版) は実機で完全正常動作。NPU 疎通確認は成功。**
受信ログ: `Model: cifarnet_quant_int8_npu` / `Core/NPU Frequency: 150 MHz` / `Inference time: 7130 us` / `Detected: ship (99%)`。

**「シリアル完全無音」の真因 = 受信タイミングの取りこぼし**（ハング/HardFault ではなかった）。
cifar10 は起動ログ＋推論結果を**起動直後に1回だけ**出力するため、「書き込み後にシリアルを繋ぐ」順だと出力済みで無音に見えていた。
**正しい手順: 受信を先に開始(115200, FC4/LPUART4) → その後 `LinkServer flash load` でクリーン起動**（LinkServer 単体 reset コマンドは無い）。

gdb 切り分けで確定: main→BOARD_Init→TIMER_Init→DEMO_PrintInfo→MODEL_Init(GetModel/interpreter/**AllocateTensors完了**/return success)→推論ループ、すべて到達。HardFault は一度も発火せず。

**次フェーズ**: この検証済みパイプラインの `model_data.h` を自作3クラス(なし/カラス/人)に差し替える。

---

## ゴール（このセッションの作業）

FRDM-MCXN947 で **NPU 推論が実機で回ること**を、SDK サンプル `tflm_cifar10`(frdmmcxn947, NPU版) で疎通確認する。これが通れば、自作モデルの `model_data.h` を差し替えて本番（分類: なし/カラス/人）へ進む。

## ✅ ここまで完了していること

1. **Mac での Keras→int8→neutron-converter(mcxn94x) は完全成功**（Issue #2 主目的の半分達成・コミット済み `5df95a4`）。
   - `tools/ml/`: arm64 venv(`arch -arm64 /usr/bin/python3`)、`make_test_model.py`(tiny CNN→int8)、`neutron_convert.sh`(Docker amd64 で neutron-converter)、`requirements.txt`。
   - 検証成果物（.gitignore の `build/`）: `build/terra_guard_int8.tflite`、`build/terra_guard_int8_mcxn94x.tflite` + `.h`（変換率9/10）。
   - 詳細は `docs/ml-model.md` §6（実機検証済み手順・ハマりどころ）。
2. **tflm_cifar10(NPU版) のビルド成功**。
   - コマンド: `~/mcuxpresso/mcuxsdk/mcuxsdk` で
     - `export ARMGCC_DIR=~/.mcuxpressotools/arm-gnu-toolchain-14.2.rel1-darwin-arm64-arm-none-eabi`
     - `export PATH="$HOME/.mcuxpressotools/.mcux-venv-3.12/bin:$PATH"`
     - `west build -b frdmmcxn947 examples/eiq_examples/tflm_cifar10 --toolchain armgcc -Dcore_id=cm33_core0 --config flash_debug -d /tmp/build_cifar10`
   - 成果物: `/tmp/build_cifar10/tflm_cifar10_cm33_core0.elf`（neutron.cpp / pcq_npu モデル含む。ELF内にログ文字列 "CIFAR-10" "Model: cifarnet_quant_int8_npu" 等あり = 正しくビルド済み）。
   - ⚠️ ターゲットは `--config flash_debug`（NPU版は flash 配置前提。`debug` ではなく `flash_debug`）。

## ❌ 詰まっていること（次に解くべき問題）

**tflm_cifar10 を書き込むと シリアルが完全無音**（115200, `DEMO_PrintInfo()` の起動ログすら出ない）。

### 切り分け済み（重要）
- **シリアル経路・LinkServer・flash後の自動起動は正常**。証拠: terra-guard(動作実績) を書き戻したら 921600 で 112,980 バイト受信、DIST/STAT/DET/サーマルマジック(0xAA55/0xAA56)すべて確認。→ **ハード/UART経路/ボードは正常。cifar10 ファーム固有の問題**。
- pin_mux 一致: cifar10 も terra-guard も UART=P1_8/P1_9=FC4(Alt2)。同一。
- clock_config.c は cifar10 ビルドに含まれている（クロック欠落ではない）。
- USB抜き差し物理リセット & RESETボタン押下でも cifar10 は無音（タイミングの問題ではない）。
- → 仮説: **`BOARD_Init()` か起動直後でハング/HardFault**（PrintInfo前で死んでいる）。NPU初期化(`MODEL_Init`)はPrintInfoの後なので、それ以前で止まっている。

### 次の一手（やりかけ）
- **gdb で止め位置(PC)を特定**する。
  - gdb: `~/.mcuxpressotools/arm-gnu-toolchain-14.2.rel1-darwin-arm64-arm-none-eabi/bin/arm-none-eabi-gdb`
  - 手順案: LinkServer gdbserver を起動
    `/Applications/LinkServer_25.6.131/LinkServer gdbserver "MCXN947:FRDM-MCXN947"`（port 3333）
    → gdb で `target remote localhost:3333` → `monitor reset` → `load` →
    `break main` / `break MODEL_Init` / `tbreak DEMO_PrintInfo` を置いて `continue` で
    どこまで到達するか確認。`main` に来ないなら起動コード(reset handler/clock)で死亡。
    `main`到達後 PrintInfo 前で死ぬなら BOARD_Init 内。
  - 注意: バッチの `continue &`+`interrupt` は不安定だった。`-batch -x script` で break を使う方式を推奨。

### 有力な代替方針（gdbで原因が割れない/時間かかる場合）
cifar10 サンプル自体の起動問題に深入りせず、**terra-guard(動作実績ある起動基盤=クロック/pin_mux/コンソール) に NPU 推論コードを移植**する。
- `examples/eiq_examples/common/tflm/model.cpp`(MODEL_Init/RunInference) + `pcq_npu/model_data.h` + op resolver を terra-guard プロジェクトに取り込み、`prj.conf` に
  `CONFIG_MCUX_COMPONENT_middleware.eiq.tensorflow_lite_micro.binary=y` と `...neutron=y` を追加。
- terra-guard は 921600 / debug_console_lite。cifar10 は 115200 / SDK_DEBUGCONSOLE_UART。コンソール差異に注意。
- これなら「起動が確実に動く土台」の上で NPU 推論だけ検証でき、最短で本番(センサ入力→NPU分類)に繋がる。

### もう一つの確認候補
- converter=3.1.3 と ファーム側 eIQ middleware の Neutron Software バージョン整合（前から要注意としている点）。ただし今回は PrintInfo 前で死んでいるので NPU 以前の問題の可能性が高い。優先度は gdb での PC 特定が先。

## 🧹 掃除（セッションリセット前に / 次セッション開始時に確認）

- **LinkServer gdbserver が残っている可能性**: `pgrep -fl "LinkServer gdbserver"` で確認し、いれば `kill <PID>`（このセッションでは PID 7433、port 3333/4444 を握る。残すと次の flash/gdb が衝突）。
- 実機には今 **terra-guard が書かれている**（デバッグ中に書き戻した）。
- 一時物: `/tmp/build_cifar10/`(cifar10ビルド)、`/tmp/gdbserver.log`、`/tmp/gdb*.txt`。
- git: branch `feat/eiq-npu-model`、ワーキングツリーはクリーン（この申し送り追加分を除く）。

## 参照
- `docs/ml-model.md`（全体フロー・§6実機検証済み手順）
- Issue #2: https://github.com/CreatorKanata/terra-guard-ai-digikey-make-one-2026/issues/2
- SDK サンプル: `~/mcuxpresso/mcuxsdk/mcuxsdk/examples/eiq_examples/tflm_cifar10/` と `_boards/frdmmcxn947/eiq_examples/tflm_cifar10/pcq_npu/`
- メモリ: `eiq-npu-workflow.md`

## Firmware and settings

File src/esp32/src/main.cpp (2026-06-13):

// TerraGuard AI — Freenove Control Board V5 (ESP32)
// 動作確認用の最小ファームウェア: オンボードLED（GPIO2）を点滅させる。
//
// 目的:
//   - PlatformIO のビルド/書き込み環境が正しく動くことを確認する
//   - シリアル出力（115200 baud）が PC で受信できることを確認する
//
// 次のステップ:
//   MLX90640（サーマル）と VL53L5CX（ToF距離）のセンサ取得処理を追加していく。

#include <Arduino.h>

// Freenove Control Board V5 のオンボードLEDは GPIO2
#ifndef LED_BUILTIN
#define LED_BUILTIN 2
#endif

// 点滅間隔（ミリ秒）
static const uint32_t BLINK_INTERVAL_MS = 500;

void setup() {
  Serial.begin(115200);
  // シリアルが安定するまで少し待つ
  delay(200);
  Serial.println();
  Serial.println("[TerraGuard] ESP32 起動: LED点滅テスト開始");
  Serial.printf("[TerraGuard] LEDピン: GPIO%d\n", LED_BUILTIN);

  pinMode(LED_BUILTIN, OUTPUT);
}

void loop() {
  // LED ON
  digitalWrite(LED_BUILTIN, HIGH);
  Serial.println("[TerraGuard] LED: ON");
  delay(BLINK_INTERVAL_MS);

  // LED OFF
  digitalWrite(LED_BUILTIN, LOW);
  Serial.println("[TerraGuard] LED: OFF");
  delay(BLINK_INTERVAL_MS);
}

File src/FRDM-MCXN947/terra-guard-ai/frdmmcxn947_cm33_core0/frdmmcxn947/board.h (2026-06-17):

/*
 * Copyright 2022-2023 NXP
 * All rights reserved.
 *
 * SPDX-License-Identifier: BSD-3-Clause
 */

#ifndef _BOARD_H_
#define _BOARD_H_

#include "clock_config.h"
#include "fsl_gpio.h"
/*******************************************************************************
 * Definitions
 ******************************************************************************/
/*! @brief The board name */
#define BOARD_NAME "FRDM-MCXN947"

/*! @brief The UART to use for debug messages. */
#define BOARD_DEBUG_UART_TYPE       kSerialPort_Uart
#define BOARD_DEBUG_UART_BASEADDR   (uint32_t) LPUART4
#define BOARD_DEBUG_UART_INSTANCE   4U
#define BOARD_DEBUG_UART_CLK_FREQ   12000000U
#define BOARD_DEBUG_UART_CLK_ATTACH kFRO12M_to_FLEXCOMM4
#define BOARD_DEBUG_UART_RST        kFC4_RST_SHIFT_RSTn
#define BOARD_DEBUG_UART_CLKSRC     kCLOCK_FlexComm4
#define BOARD_UART_IRQ_HANDLER      LP_FLEXCOMM4_IRQHandler
#define BOARD_UART_IRQ              LP_FLEXCOMM4_IRQn

#define BOARD_DEBUG_UART_TYPE_CORE1       kSerialPort_Uart
#define BOARD_DEBUG_UART_BASEADDR_CORE1   (uint32_t) USART1
#define BOARD_DEBUG_UART_INSTANCE_CORE1   1U
#define BOARD_DEBUG_UART_CLK_FREQ_CORE1   12000000U
#define BOARD_DEBUG_UART_CLK_ATTACH_CORE1 kFRO12M_to_FLEXCOMM1
#define BOARD_DEBUG_UART_RST_CORE1        kFC1_RST_SHIFT_RSTn
#define BOARD_DEBUG_UART_CLKSRC_CORE1     kCLOCK_Flexcomm1
#define BOARD_UART_IRQ_HANDLER_CORE1      FLEXCOMM1_IRQHandler
#define BOARD_UART_IRQ_CORE1              FLEXCOMM1_IRQn

#ifndef BOARD_DEBUG_UART_BAUDRATE
/* MLX90640 32Hz の FRAME 行(約4.6KB)を捌くため 921600 に引き上げ（115200の8倍）。
   受信側ビューアも同じ baud で開くこと（dual_viewer.py 等のデフォルトを921600に変更済み）。 */
#define BOARD_DEBUG_UART_BAUDRATE 921600U
#endif /* BOARD_DEBUG_UART_BAUDRATE */

#ifndef BOARD_DEBUG_UART_BAUDRATE_CORE1
#define BOARD_DEBUG_UART_BAUDRATE_CORE1 115200U
#endif /* BOARD_DEBUG_UART_BAUDRATE_CORE1 */

/*! @brief The UART to use for Bluetooth M.2 interface. */
#define BOARD_BT_UART_BASEADDR   LPUART2
#define BOARD_BT_UART_INSTANCE   2
#define BOARD_BT_UART_BAUDRATE   3000000
#define BOARD_BT_UART_CLK_FREQ   12000000U
#define BOARD_BT_UART_CLK_ATTACH kFRO12M_to_FLEXCOMM2

/*! @brief The ENET PHY address. */
#define BOARD_ENET0_PHY_ADDRESS (0x00U) /* Phy address of enet port 0. */

/*! @brief Memory ranges not usable by the ENET DMA. */
#ifndef BOARD_ENET_NON_DMA_MEMORY_ARRAY
#define BOARD_ENET_NON_DMA_MEMORY_ARRAY                                                     \
    {                                                                                       \
        {0x00000000U, 0x0007FFFFU}, {0x10000000U, 0x17FFFFFFU}, {0x80000000U, 0xDFFFFFFFU}, \
            {0x00000000U, 0x00000000U},                                                     \
    }
#endif /* BOARD_ENET_NON_DMA_MEMORY_ARRAY */

#define BOARD_ACCEL_I2C_BASEADDR   LPI2C2
#define BOARD_ACCEL_I2C_CLOCK_FREQ 12000000

#define BOARD_CODEC_I2C_BASEADDR   LPI2C2
#define BOARD_CODEC_I2C_CLOCK_FREQ 12000000
#define BOARD_CODEC_I2C_INSTANCE   2

/*! @brief Indexes of the TSI channels for on-board electrodes */
#ifndef BOARD_TSI_ELECTRODE_1
#define BOARD_TSI_ELECTRODE_1 3U
#endif

/*! @brief Indexes of the TSI mutual channels for FRDM-TOUCH board */
#define BOARD_TSI_MUTUAL_TX_ELECTRODE_1 0U
#define BOARD_TSI_MUTUAL_RX_ELECTRODE_1 14U

#ifndef BOARD_LED_RED_GPIO
#define BOARD_LED_RED_GPIO GPIO0
#endif
#ifndef BOARD_LED_RED_GPIO_PIN
#define BOARD_LED_RED_GPIO_PIN 10U
#endif

#ifndef BOARD_LED_BLUE_GPIO
#define BOARD_LED_BLUE_GPIO GPIO1
#endif
#ifndef BOARD_LED_BLUE_GPIO_PIN
#define BOARD_LED_BLUE_GPIO_PIN 2U
#endif

#ifndef BOARD_LED_GREEN_GPIO
#define BOARD_LED_GREEN_GPIO GPIO0
#endif
#ifndef BOARD_LED_GREEN_GPIO_PIN
#define BOARD_LED_GREEN_GPIO_PIN 27U
#endif

#ifndef BOARD_SW2_GPIO
#define BOARD_SW2_GPIO GPIO0
#endif
#ifndef BOARD_SW2_GPIO_PIN
#define BOARD_SW2_GPIO_PIN 23U
#endif
#define BOARD_SW2_NAME        "SW2"
#define BOARD_SW2_IRQ         GPIO00_IRQn
#define BOARD_SW2_IRQ_HANDLER GPIO00_IRQHandler

#ifndef BOARD_SW3_GPIO
#define BOARD_SW3_GPIO GPIO0
#endif
#ifndef BOARD_SW3_GPIO_PIN
#define BOARD_SW3_GPIO_PIN 6U
#endif
#define BOARD_SW3_NAME        "SW3"
#define BOARD_SW3_IRQ         GPIO00_IRQn
#define BOARD_SW3_IRQ_HANDLER GPIO00_IRQHandler

/* USB PHY condfiguration */
#define BOARD_USB_PHY_D_CAL     (0x04U)
#define BOARD_USB_PHY_TXCAL45DP (0x07U)
#define BOARD_USB_PHY_TXCAL45DM (0x07U)

#define BOARD_HAS_NO_CTIMER_OUTPUT_PIN_CONNECTED_TO_LED (1)

/* Board led color mapping */
#define LOGIC_LED_ON  0U
#define LOGIC_LED_OFF 1U
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

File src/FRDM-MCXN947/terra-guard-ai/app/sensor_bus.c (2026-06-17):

/*
 * TerraGuard AI — FRDM-MCXN947
 * sensor_bus: センサ共通基盤の実装
 *
 * NXP の I3C master_read_sensor_p3t1755 / lpi2c polling_b2b_master サンプルをベースに移植。
 *
 * Copyright 2022, 2025 NXP / 2026 TerraGuard
 * SPDX-License-Identifier: BSD-3-Clause
 */

#include <string.h>
#include "sensor_bus.h"
#include "fsl_debug_console.h"
#include "fsl_i3c.h"
#include "fsl_lpi2c.h"
#include "app.h"

/*******************************************************************************
 * Definitions
 ******************************************************************************/
/* I3C ボーレート（サンプルの Kconfig デフォルト値を直接定義） */
#define EXAMPLE_I2C_BAUDRATE    400000U
#define EXAMPLE_I3C_OD_BAUDRATE 1500000U
#define EXAMPLE_I3C_PP_BAUDRATE 4000000U

#define I3C_TIME_OUT_INDEX 100000000U

/* P3T1755 のレジスタアクセス用アドレス（動的アドレス割当後） */
#define SENSOR_ADDR 0x08U
#define CCC_RSTDAA  0x06U
#define CCC_SETDASA 0x87

/*******************************************************************************
 * Variables
 ******************************************************************************/
static volatile status_t   s_completionStatus;
static volatile bool       s_masterCompletionFlag;
static i3c_master_handle_t s_i3c_m_handle;
static p3t1755_handle_t    s_p3t1755Handle;

/*******************************************************************************
 * Prototypes
 ******************************************************************************/
static void i3c_master_callback(I3C_Type *base, i3c_master_handle_t *handle, status_t status, void *userData);

static const i3c_master_transfer_callback_t s_masterCallback = {
    .slave2Master = NULL, .ibiCallback = NULL, .transferComplete = i3c_master_callback};

/*******************************************************************************
 * 共通ユーティリティ
 ******************************************************************************/
void sensor_print_temp_c(const char *label, float celsius)
{
    int32_t centi = (int32_t)(celsius * 100.0f + (celsius >= 0 ? 0.5f : -0.5f));
    int32_t ip    = centi / 100;
    int32_t fp    = centi % 100;
    if (fp < 0)
    {
        fp = -fp;
    }
    /* -0.xx のとき整数部が 0 でも符号を保持 */
    if (centi < 0 && ip == 0)
    {
        PRINTF("%s-0.%02d C", label, fp);
    }
    else
    {
        PRINTF("%s%d.%02d C", label, ip, fp);
    }
}

void sensor_write_raw(const uint8_t *data, size_t len)
{
    for (size_t i = 0; i < len; i++)
    {
        /* DbgConsole_Putchar は1バイトをブロッキング送信する（PUTCHAR マクロの実体）。
           書式変換が無いぶん PRINTF("%d") より大幅に軽い。 */
        (void)PUTCHAR((int)data[i]);
    }
}

/*******************************************************************************
 * I3C コールバック / 低レベルアクセス
 ******************************************************************************/
static void i3c_master_callback(I3C_Type *base, i3c_master_handle_t *handle, status_t status, void *userData)
{
    if (status == kStatus_Success)
    {
        s_masterCompletionFlag = true;
    }
    s_completionStatus = status;
}

status_t sensor_i3c_write(uint8_t deviceAddress, uint32_t regAddress, uint8_t *regData, size_t dataSize)
{
    status_t result                  = kStatus_Success;
    i3c_master_transfer_t masterXfer = {0};
    uint32_t timeout                 = 0U;

    masterXfer.slaveAddress   = deviceAddress;
    masterXfer.direction      = kI3C_Write;
    masterXfer.busType        = kI3C_TypeI3CSdr;
    masterXfer.subaddress     = regAddress;
    masterXfer.subaddressSize = 1;
    masterXfer.data           = regData;
    masterXfer.dataSize       = dataSize;
    masterXfer.flags          = kI3C_TransferDefaultFlag;

    s_masterCompletionFlag = false;
    s_completionStatus     = kStatus_Success;
    result                 = I3C_MasterTransferNonBlocking(EXAMPLE_MASTER, &s_i3c_m_handle, &masterXfer);
    if (kStatus_Success != result)
    {
        return result;
    }

    while (!s_masterCompletionFlag)
    {
        timeout++;
        if ((s_completionStatus != kStatus_Success) || (timeout > I3C_TIME_OUT_INDEX))
        {
            break;
        }
    }

    if (timeout == I3C_TIME_OUT_INDEX)
    {
        result = kStatus_Timeout;
    }
    result = s_completionStatus;

    return result;
}

status_t sensor_i3c_read(uint8_t deviceAddress, uint32_t regAddress, uint8_t *regData, size_t dataSize)
{
    status_t result                  = kStatus_Success;
    i3c_master_transfer_t masterXfer = {0};
    uint32_t timeout                 = 0U;

    masterXfer.slaveAddress   = deviceAddress;
    masterXfer.direction      = kI3C_Read;
    masterXfer.busType        = kI3C_TypeI3CSdr;
    masterXfer.subaddress     = regAddress;
    masterXfer.subaddressSize = 1;
    masterXfer.data           = regData;
    masterXfer.dataSize       = dataSize;
    masterXfer.flags          = kI3C_TransferDefaultFlag;

    s_masterCompletionFlag = false;
    s_completionStatus     = kStatus_Success;
    result                 = I3C_MasterTransferNonBlocking(EXAMPLE_MASTER, &s_i3c_m_handle, &masterXfer);
    if (kStatus_Success != result)
    {
        return result;
    }

    while (!s_masterCompletionFlag)
    {
        timeout++;
        if ((s_completionStatus != kStatus_Success) || (timeout > I3C_TIME_OUT_INDEX))
        {
            break;
        }
    }

    if (timeout == I3C_TIME_OUT_INDEX)
    {
        result = kStatus_Timeout;
    }
    result = s_completionStatus;

    return result;
}
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

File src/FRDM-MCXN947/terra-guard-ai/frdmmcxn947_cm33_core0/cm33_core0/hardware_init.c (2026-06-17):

/*
 * TerraGuard AI — FRDM-MCXN947
 * ボード初期化: クロック(UART/I3C) / ピン(UART/I3C) / デバッグコンソール。
 * NXP の master_read_sensor_p3t1755 サンプルに準拠。
 *
 * Copyright 2022-2023, 2025 NXP / 2026 TerraGuard
 * SPDX-License-Identifier: BSD-3-Clause
 */

/*${header:start}*/
#include "pin_mux.h"
#include "clock_config.h"
#include "board.h"
/*${header:end}*/

/*${function:start}*/
void BOARD_InitHardware(void)
{
    /* デバッグコンソール(FLEXCOMM4)へ FRO12M をアタッチ */
    CLOCK_SetClkDiv(kCLOCK_DivFlexcom4Clk, 1);
    CLOCK_AttachClk(BOARD_DEBUG_UART_CLK_ATTACH);

    /* I3C1 へ PLL0 をアタッチ（150MHz / 6 = 25MHz） */
    CLOCK_SetClkDiv(kCLOCK_DivI3c1FClk, 6U);
    CLOCK_AttachClk(kPLL0_to_I3C1FCLK);

    BOARD_InitBootPins();   /* LED/UART等の基本ピン */
    BOARD_InitI3CPins();    /* I3C1 (P1_11/16/17) ピン */
    BOARD_InitI2CPins();    /* LPI2C2 (P4_0/P4_1) ピン */
    BOARD_InitBootClocks(); /* PLL150M / FRO_HF 等を確定（I3CがPLL0を使うため必須） */

    /* 外部I²Cセンサ用 FLEXCOMM2(LPI2C2) のクロック源（J8 pin3/4 = J2 pin18/20, P4_0/P4_1）。
       FRO12M(12MHz) では 1MHz SCL を 12分周でしか作れず波形が FM+ 規格を満たさず、
       MLX90640/VL53L5CX(ともに最大1MHz)が高速で ACK できなかった。
       FRO_HF(48MHz) を FRO_HF_DIV で ÷2=24MHz にして FC2 へ供給し、1MHz SCL を
       24分周で余裕を持って生成する。BootClocks で FRO_HF が確定した後にアタッチする。 */
    CLOCK_SetClkDiv(kCLOCK_DivFrohfClk, 2U);   /* FRO_HF_DIV = FRO_HF/2 = 24MHz */
    CLOCK_SetClkDiv(kCLOCK_DivFlexcom2Clk, 1U);
    CLOCK_AttachClk(kFRO_HF_DIV_to_FLEXCOMM2);

    BOARD_InitDebugConsole();
}
/*${function:end}*/

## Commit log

2026-06-13 chore: ESP32 LED点滅プロジェクトとプロジェクトドキュメントの初期化
    - CLAUDE.md: プロジェクトルール（日本語必須・ROHM記述禁止・PlatformIO使用）
    - docs/README.md: ドキュメント目次
    - src/esp32: Freenove Control Board V5 (ESP32) PlatformIO プロジェクト
    - LED点滅（Lチカ）ファームウェアで書き込み動作確認用
    - シリアル出力 115200 baud、LED=GPIO2
2026-06-13 refactor: プロトタイプ基板をRA4M1(UNO R4 WiFi互換)向けに修正しesp32→arduinoへリネーム
    - Freenove Control Board V5 はメインMCUがRenesas RA4M1、ESP32-S3はWiFi専用サブ
    - platformio.ini: platform=renesas-ra / board=uno_r4_wifi に変更
    - main.cpp: LED_BUILTIN=D13、RA4M1で動作する旨を明記
    - src/esp32 → src/arduino にリネーム
    - CLAUDE.md/docs: ハードウェア構成とパス参照を修正
    [main.cpp]
2026-06-13 docs: プロジェクト詳細ドキュメントを日本語で追加
    - overview.md: 課題・ソリューション・全体アーキテクチャ
    - hardware.md: 使用部品・配線・システム構成（RA4M1/ESP32-S3構成を明記）
    - sensor-processing.md: 前処理・特徴量設計・検出ロジック
    - demo.md: デモ構成・PC表示・実験手順
    - roadmap.md: 開発ステップ・追い払い機構
    - firmware.md: PlatformIO使い方・ESP32-S3の扱い
    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
2026-06-14 docs: FRDM-MCXN947単体(MCUXpresso SDK)構成へ全面改訂、カラス検出にスコープ限定
    - 外部Arduino/RA4M1/ESP32(中継ボード)を全廃。センサはFRDM-MCXN947へ直接I2C接続
    - 開発環境をPlatformIO→MCUXpresso SDKに変更、ルートをsrc/FRDM-MCXN947に
    - eIQ Neutron NPU等のボードスペックを反映
    - 今回のスコープを「カラスの検出のみ」に明記（人検出/追い払いは後続）
    - src/arduino を削除、src/FRDM-MCXN947 プレースホルダ追加
    - CLAUDE.md/全docsを上記方針で整合
2026-06-14 feat: FRDM-MCXN947 led_blinkyプロジェクト追加(MCUXpresso SDK)
    - MCUXpresso for VS Code拡張で生成したrepo-managedプロジェクト
    - SysTick割り込みでオンボードLEDをトグルするLチカ
    - CLI(cmake --preset debug)でビルド成功を確認済み
    - .vscodeのbuild/debug/flash設定を含む
    - sdks/(2GB超)・debug/・.bin・__repo__ は.gitignoreで除外
    - READMEにビルド・書き込み手順を記載
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2026-06-14 feat: LED点滅周期を1秒に変更(トグル0.5s)
    - SysTick_Config を 12,000,000→6,000,000 に変更
    → 0.5秒ごとにトグル、点滅周期1秒(ON 0.5s + OFF 0.5s)
    - 実機(FRDM-MCXN947)で点滅確認済み
    - .vscode/c_cpp_properties.json: IntelliSense用compile_commands.jsonパスを追加(VS Code拡張が自動設定)
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2026-06-14 docs: MLX90640/VL53L5CX/FRDM-MCXN947の実装メモとデータシートを追加
    - datasheets/ にPDF格納: MLX90640(Melexis), UM2884(VL53L5CX ULD), UM12018(既存)
    - 実装メモ(日本語要約)を追加:
    - FRDM-MCXN947.md: オンボード部品確定(温度センサP3T1755DPのみ、加速度センサ非搭載)、UART/I2C/I3Cピン、クロック注意点
    - MLX90640.md: I2C 0x33、レジスタ、読み出しフロー
    - VL53L5CX.md: I2C 0x52/0x29、ULD、Platform実装
    - VL53L5CXデータシート本体はST bot除けで未取得(URL明記)
2026-06-14 docs: 開発手順の実績を反映(CLIビルド/書き込み/シリアル確認/MCU-Linkリカバリ)
    - firmware.md: CLI(cmake preset/LinkServer/west)手順、シリアル不調の切り分け、MCU-Linkファーム更新を追記
    - firmware.md: オンボード温度センサP3T1755DP(I3C,0x48)の記述を追加(加速度センサは非搭載と明記)
    - roadmap.md: Step1完了を反映(LED/シリアル/温度センサI3C疎通を実証)
2026-06-14 feat: オンボード温度センサP3T1755DP(I3C)の読み取りを実装
    - led_blinky.c: I3CでP3T1755の温度を読み1秒周期でシリアル出力
    - 動的アドレス割当(RSTDAA/SETDASA)→P3T1755_Init→ReadTemperature
    - debug_console_lite が%f非対応のため整数演算で小数2桁表示
    - hardware_init.c: I3C1クロック(PLL0,150MHz/6)+UART+PLL150M+I3Cピン初期化
    - pin_mux.c/.h: UART(FC4: P1_8/P1_9)とI3C(P1_11/16/17)ピン設定を追加
    - app.h: I3C1/0x48定義
    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
2026-06-16 docs: ピンレイアウト図と外部センサI2C配線情報を追加
    - pin-layout.png: FRDM-MCXN947全ヘッダのピン配置早見図
    - hardware.md: MLX90640/VL53L5CXのI2C配線表(SDA=J2p18/P4_0, SCL=J2p20/P4_1, FC2/LPI2C2, 3.3V直結)を追記
    - README目次にpin-layout参照を追加
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2026-06-16 feat: 外部I²Cセンサ用 LPI2C2(FC2)を有効化しMLX90640(0x33)を疎通確認
    J8(FlexIO) pin1-4 経由で外部I²Cバス LPI2C2/FLEXCOMM2(P4_0/P4_1)を初期化し、
    起動時のI²Cバススキャンでサーマルセンサ MLX90640(0x33)のACKを実機確認。
    オンボード温度センサ(I3C)の機能は維持。
    - pin_mux: BOARD_InitI2CPins()追加 (P4_0=SDA/P4_1=SCL, MuxAlt2, 内部PU)
    - hardware_init: FC2クロックアタッチ(kFRO12M_to_FLEXCOMM2, Div=1)
    - app.h: LPI2C2ベース/クロック/MLX90640アドレス(0x33)マクロ
    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
2026-06-16 feat: MLX90640 の32×24サーマルフレーム取得・温度変換を実装
    Melexis 公式 API(Apache-2.0)を vendor/mlx90640/ に移植し、I²Cドライバ層のみ
    LPI2C2 で自前実装(BSD-3)。校正済み温度[℃]の32×24フレームをシリアル出力。
    室温で Ta≈31℃/min≈27.6/max≈33/avg≈28.8℃を実機確認(P3T1755とも整合)。
    - vendor/mlx90640/MLX90640_API.c/.h, MLX90640_I2C_Driver.h: 公式原文(Apache-2.0)
    - vendor/mlx90640/mlx90640_i2c_lpi2c.c: LPI2C2 ドライバ層(自前/BSD-3)
    - LPI2C_MasterTransferBlocking + 16bit subaddress(MSBファースト)
    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
2026-06-16 feat: サーマルフレームのシリアル出力とPythonヒートマップビューアを追加
    MLX90640 の32×24フレームをPython側で受信し、リアルタイムにヒートマップ表示
    できるようにした。実機の1フレームを320×240pxのjet画像として描画できることを確認。
    - led_blinky.c: mlx90640_print_frame() を追加
    "FRAME,<Ta>,<t0>,...,<t767>"(各値1/100℃の整数)を1フレームごとに出力。
    既存の min/max/avg/center 統計表示は維持。
    - tools/thermal_viewer.py: シリアル受信→32×24パース→各px10倍拡大(320×240)→
    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
2026-06-17 docs: サーマルカメラ動作テスト画像を images に追加
    MLX90640 のフレームを Python ビューアでヒートマップ化したテスト画像を追加。
    手をかざした際に体温域(36℃)がはっきり写り、ビューアと温度変換が実環境で
    正しく機能することを示す。
    - images/thermal-camera-test/thermal-hand.png: 手をかざしたサーマル画像(640×480)
    - docs/datasheets/MLX90640.md: 動作確認セクションに画像を掲載
2026-06-17 feat: VL53L5CX(ToF 8x8 距離センサ)の全ゾーン距離取得を実装
    ST 公式 ULD(BSD-3)を vendor/vl53l5cx/ に移植し、I²Cプラットフォーム層のみ
    LPI2C2 で自前実装。FW(84KB)転送→8x8/15Hz 測距→全64ゾーンの距離[mm]を出力。
    MLX90640 と同じ FC2 バス(J8)に共存。天井2.5m環境で妥当な奥行き勾配を実機確認。
    - vendor/vl53l5cx/: ST公式 ULD(api.c/.h, buffers.h=FW84KB, platform.h, LICENSE)
    - vendor/vl53l5cx/vl53l5cx_platform_lpi2c.c: 自前(BSD-3) platform 層
    - RdMulti/WrMulti を128バイト分割(FW転送の肝、アドレスを進める)
    - 8bit(0x52)→7bit(0x29)アドレス変換、SwapBuffer/WaitMs
    - led_blinky.c: v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
    [distance_viewer.py, led_blinky.c]
2026-06-17 fix: VL53L5CX の全ゾーン取得・低信頼ゾーン低減・GUI描画固定を修正
    「1/3〜1/2のゾーンが白抜け」「近距離で数秒固定」を解消。距離は全ゾーンで
    妥当に取得できており、白抜けはビューアが status==255 を捨てていたこと、
    数秒固定は GUI(matplotlib)の描画ブロックが原因と判明（センサは正常）。
    - led_blinky.c:
    - vl53l5cx_set_integration_time_ms(20) を frequency 設定前に追加。
    遠距離・弱反射ゾーンの信頼度が上がり status==255 が 30%→15% に低減。
    高信頼ゾーンは 57〜60/64 に改善。
    - フレームレートを 15→10Hz（積分時間を確保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
    [distance_viewer.py, led_blinky.c]
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2026-06-17 feat: 2センサ同時表示ビューア dual_viewer.py を追加
    MLX90640(サーマル)とVL53L5CX(距離)を同一シリアルから受信し、
    matplotlibで左=サーマル(32×24)、右=距離(8×8)を1ウィンドウに
    並べてリアルタイム表示する。
    - バイナリ(0xAA55+Ta+768×int16)とテキスト(DIST/STAT)の混在ストリームを
    extract_messages で分離してパース
    - 各センサの最新フレームのみ描画(古いフレームはスキップ)
    - s=PNG保存 / q=終了、--flip-h/-v でセンサ向き補正
    FRDM側の同時動作ループ(VL53高頻度ポーリング＋MLXはdata-ready確認後取得)は
    前コミットの led_blinky.c / app モジュ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
    [dual_viewer.py]
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2026-06-19 feat: カラス3Dモデル(STL/3MF)を追加（検出テスト用ターゲット）
    [craw-small1.stl, craw-small2.stl, craw1.3mf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]
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2026-06-19 fix: VL53L5CX のちらつき対策（ゾーン別ホールド）と巨大値バグ修正
    低信頼ゾーン(target_status!=5)が瞬間的にゴミ距離を返すちらつきを抑える。
    - ゾーンごとに最後の有効値を保持し、低信頼フレームは前回値でホールド
    - 無効が5フレーム(≒0.5s@10Hz)連続したらホールド切れとして最大レンジに倒す
    - 無効/対象なしを -1 ではなく最大レンジ4000mmで出力（status=5値も上限クランプ）
    これにより DIST は常に0〜4000の非負整数となり、受信側で -1 が
    unsigned 化けして 4294967295 になるバグを根絶。ヒートマップも連続的に。
    [tof_vl53l5cx.c]
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2026-06-19 fix: VL53L5CX のばらつき低減・無効ゾーン処理・巨大値バグ修正
    - 積分時間 20→33ms（σ≈6mm/±12mm程度に低減。実測 距離~7fps維持）
    - シャープナー20% でクロストーク低減（既存）
    - ホールド猶予 5→10フレーム（≒1秒@10Hz）に延長しちらつきをさらに抑制
    - 無効/ホールド切れゾーンは最大レンジ4000ではなく -1 で出力（ビューアでグレー表示）
    - DIST出力の根本バグ修正: このPRINTF実装は %d に負値を渡すと unsigned 化け
    (-1→4294967295)するため、無効ゾーンは固定文字列 ",-1" を出力。
    統計行の avg/center の負値化けも回避。
    [tof_vl53l5cx.c]
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2026-06-20 feat(tools): ビューアに背景差分表示・検出バナーを追加、距離前景の全消えバグ修正
    dual_viewer.py:
    - パーサ extract_messages にサーマル前景フレーム(magic 0xAA56, 768画素)を追加
    - diffパネルをフレーム間差分→ファーム背景差分(前景)表示に置換(Hotスケール、0以上)
    - 上部に検出バナー追加(CANDIDATE赤 / no candidate / initializing)。DET行をパース
    - 距離前景の全消えバグ修正: DFG が DIST と別の読み取りバッチに割れると、
    DIST受信時に前景をゼロ上書きして「検出中の対象がまるごと消える」現象が発生。
    距離前景を永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
    [dual_viewer.py, dual_viewer_web.py]
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2026-06-20 feat(ml): 自作NPUモデルをNeutron NPUで実機疎通(converter版不一致を解消)
    neutron-converter 3.0.0(SDK内蔵ドライバと同じ microcode 0X6d41ac8b)で
    再変換し、op resolver を 3op(Softmax+Slice+NEUTRON_GRAPH)に合わせることで
    Microcode mismatch / driver error 109 を解消。自作3クラスtinyモデルが
    FRDM-MCXN947 の eIQ Neutron NPU で Invoke 成功(推論 221us)。
    - tools/ml/make_model_data_h.py: 生.h を SDK枠(.model配置/arena/MODEL_NAME)へ流し込む合成器
    - docs/nxp/HANDOFF-npu-custom-model.md: 疎通成功までの手順と落とし穴を記録
    - docs/nxp/HANDOFF-npu-cifar10-debug.md: cifar10 NPU疎通(無音の真因=受信タイミン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
    [make_model_data_h.py]
2026-06-20 feat(ml): カラス検出データ収集〜学習〜NPU変換の基盤を構築(2クラス/32x32x4)
    実機(MLX90640+VL53L5CX)からカラス検出用データを集めて学習し、NPUへ
    デプロイするまでの一連のツールを追加。今フェーズは「カラス or not」の
    2クラス分類。入力は最終仕様に合わせ 32x32x4(thermal/thermal_fg/distance/
    distance_fg)。ダミーデータで学習→int8→3.0.0 NPU変換(12/14 op)まで疎通確認。
    - collect_dataset.py: dual_viewerのパーサを再利用しライブ収集。キー打鍵
    (c=crow/n=not_crow/s=skip)で連続ラベリング。生32x24を.npzで連番保存
    - build_trainset.py: .npz群→[N,32,32,4]f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
    [build_trainset.py, collect_dataset.py, train_model.py]
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2026-06-20 fix(bg): 途中登場のカラスがサーマル前景に出ないバグを修正
    背景のEMA凍結をセンサごとに独立判定するよう変更。旧実装は
    「サーマル AND 距離」の候補成立時のみ凍結していたため、片方(サーマル)の
    前景が候補不成立だと前景の出ているセンサの背景までEMA更新され続け、
    途中で現れた対象が数秒で背景に吸収され前景が消えていた。
    → 各センサは自分の前景が立つ間は自分の背景を凍結する。
    あわせて低解像度MLXで対象が画素間平均化されピーク差が目減りするのに対応:
    - BG_THERMAL_FG_MIN_C 2.0→1.0℃（羽毛表面30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
2026-06-20 feat(viewer): 背景リセットボタンを追加しUIを英語化・横長レイアウトに
    ファーム(led_blinky.c):
    - メインループでデバッグUART(LPUART4)を非ブロッキングにポーリングし、
    'R'/'r' 受信で bg_reset() を呼ぶ。背景を任意のタイミングで取り直せる
    （ビューアの Reset background ボタンから送信）。GETCHARはブロッキングで
    センサ処理を止めるため、LPUARTを直接ポーリングする方式にした。
    ビューア(dual_viewer_web.py):
    - Reset background ボタンを追加。押すと 'R' を送信し背景を再確立。
    - レイアウトを横長に変更: 左=2x2チャート、右=操作&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
    [dual_viewer_web.py, led_blinky.c]
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2026-06-20 feat(fw): terra-guard-ai 本体にeIQ Neutron NPU推論を統合(ビルド疎通)
    tflm_cifar10 サンプルからTFLite Micro推論基盤を移植し、本体(センサ+背景差分)に
    NPU推論を同居させた。MODEL_Init() まで実装しビルド成功(m_flash1にカラスモデル
    8208B配置、m_text 29.7%)。
    - tflm/model.cpp + tflm/model/model.h: 推論API(MODEL_Init/RunInference/テンソル
    取得)をSDK共通から移植。output_postproc/get_top_n はcifar10固有(labels.h/chgui.h
    依存)なので取り込まず、2クラス判定は本体側で独自実装する方針
    - tflm/pcq_npu/: 学習済みカラスモデル(model_data.h, terra_guard_crow 8208B) +
    op resolver(So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
    [led_blinky.c]
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2026-06-20 fix(bg): サーマル前景の市松模様を修正(前景閾値を1.0→2.0℃に戻す)
    前景閾値を1.0℃に下げたら完璧な市松模様が出た(実機確認)。原因はMLX90640の
    サブページ0/1の系統的オフセット差(約1〜1.6℃)。閾値が低いと片サブページ
    (市松の片半分)だけ一様に閾値を超えて前景化し、もう片方は0になりチェッカー
    ボードになる(生サーマルは市松でないのに前景だけ市松)。2.0℃ならサブページ差を
    超えるので市松が消えることを実機で確認。面積閾値も4に戻した。
    カラス(羽毛表面30-35℃)は近接・大きく写れば背景と2℃以上の差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
2026-06-20 chore(3d-models): カラスSTLをcraw/に整理、筐体enclosure(box top/bottom)を追加
    - craw-small1/2.stl, craw1/2.stl, craw1.3mf を craw/ サブフォルダへ移動・整理
    - enclosure/ を新規追加: terra-guard-box-top.stl / terra-guard-box-bottom.stl
    [craw-small1.stl, craw-small2.stl, craw1.3mf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]
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2026-06-20 chore(3d-models): カメラジョイント部品を追加、筐体box top/bottomを更新
    - enclosure/terra-guard-camera-joint.stl を新規追加（カメラ取付ジョイント）
    - terra-guard-box-top.stl / terra-guard-box-bottom.stl を更新
    [terra-guard-box-bottom.stl, terra-guard-box-top.stl, terra-guard-camera-joint.stl]
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2026-06-22 feat(thermal): MLX90640を90度右回転(センサ取付向き補正)
    サーマルセンサを物理的に90度回転して取り付けたため、ファーム側で
    取得直後に90度右回転(時計回り)し、以降の全消費者(bin送出/統計/背景差分/
    NPU入力)に正立画像を渡す。距離センサ(VL53L5CX)は回転しない。
    ファーム:
    - thermal_mlx90640.c: 完成フレーム時に rotate_cw90() で生32×24 →
    回転後24列×32行(s_mlxTo)。stats中心画素も24列前提に修正。
    - npu_infer.c: 回転後フレームを24×24 crop(中央24行)→32×32中央pad。
    距離は従来通り8×8最近傍4倍(回転なし)。
    学習パイプライン(再学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
    [build_trainset.py, collect_dataset.py, thermal_mlx90640.c]
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2026-06-22 fix(thermal): サブページ段差補正(dechess_subpage)で前景の市松模様を除去
    MLX90640 Chess モードのサブページ0/1系統オフセット差(約1〜1.6℃)が
    背景差分の生差分に漏れ、サーマル前景マップが市松模様になっていた。
    rotate_crop 直前に生フレーム(行24×列32)へ subpage=(r+c)&1 で中央値段差
    補正を適用し根本除去。thermal_abs/thermal_fg/背景/NPU入力/データ収集
    すべてがクリーンな24×24を見る。実機検証(36フレーム)でA/Bゼロ率差0.046。
    model_data.h はNPUワークフロー疎通時の再変換分を反映。
    [thermal_mlx90640.c]
2026-06-22 docs: サーマル処理解像度を24×24に統一(センサ生32×24は取得直後に24×24化)
    センサ生は32×24だが rotate_crop で取得直後に24×24化し、以降の全処理
    (背景差分/前景/送出/NPU入力/データ収集)は一貫して24×24で行われる旨を明記。
    処理文脈で32×24/768/16×12/3クラスとなっていた旧記述を24×24/576/2クラスに修正。
    バイナリ仕様も576×int16(1156B)へ訂正。
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2026-06-22 feat(npu): 純背景追加で再学習+デバウンス強化(全部crow誤判定を解消)
    not_crow に『人/腕』だけでなく『人もカラスもいない純背景(前景ほぼ0)』を
    十分含めて再学習(val_acc 0.972)。前景少=crow の誤学習が直り、静止背景で
    安定して not_crow(確信度0.996)を出すように。デバウンスは実測7fpsに合わせ
    CROW_CONFIRM_FRAMES 2→10(≒1.4秒連続)に強化し境界スパイクの誤確定を抑制。
    コメントの32×32×4→24×24×4 / fps表記も実機値に修正。
    [led_blinky.c]
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
